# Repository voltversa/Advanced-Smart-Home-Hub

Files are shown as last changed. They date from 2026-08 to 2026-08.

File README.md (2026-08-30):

# STM32F746 Smart Home Hub

<p align="center">
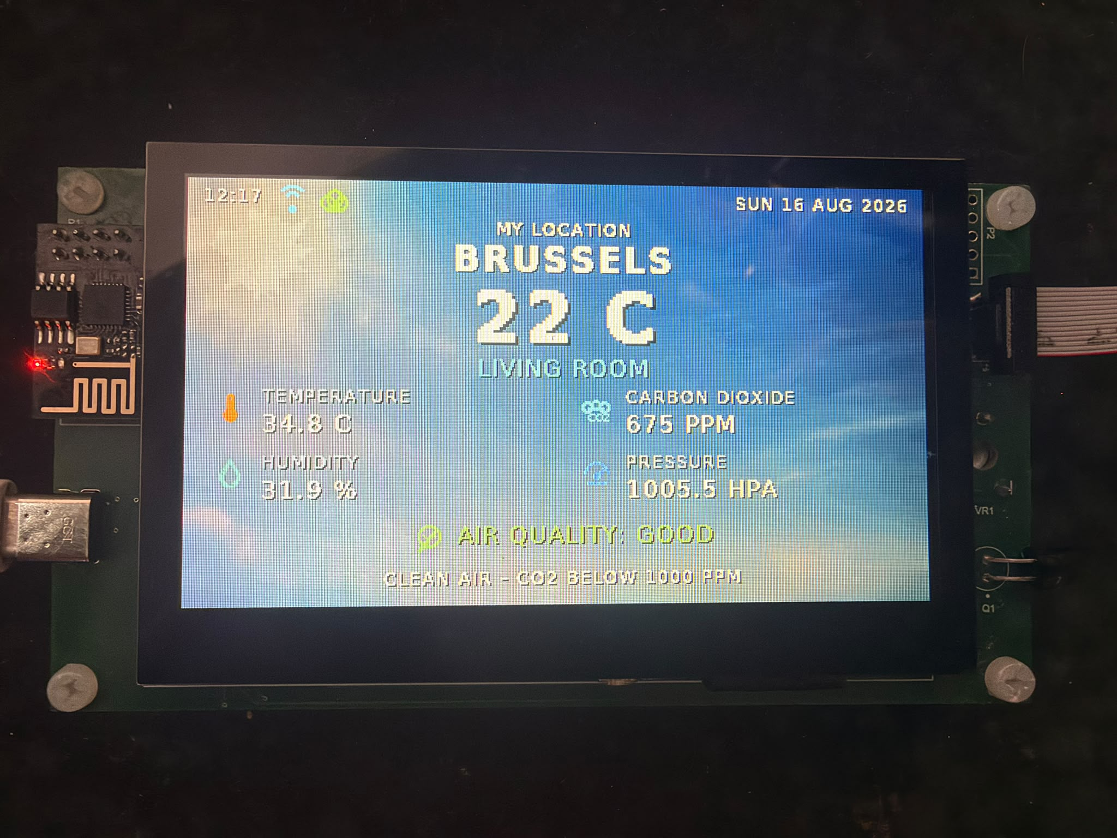
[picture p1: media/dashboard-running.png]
Smart Home Hub dashboard running on the assembled prototype
  
</p>

<p align="center">
  <strong>A custom embedded platform for environmental monitoring, local visualization, alarms, USB diagnostics, and Wi-Fi connectivity.</strong>
</p>






The Smart Home Hub is a manufactured and assembled Advanced PCB course project built around the STM32F746BGT6. It combines a 4.3-inch RGB display, external SDRAM and QSPI Flash, environmental sensing, an optical flame front end, an audible alarm, ESP-01/Blynk connectivity, and an MCP2221A USB service console on one custom PCB.

The repository contains the native Altium design history, a final four-layer submission package, manufacturing outputs, recovered application sources and GUI assets, test evidence, technical documentation, photographs, video, and the oral-demonstration presentation.

> [!IMPORTANT]
> This is an educational laboratory prototype. It is not a certified smoke, flame, gas, carbon-monoxide, or life-safety detector and must not replace approved safety equipment.

## System overview

```mermaid
flowchart TB
    POWER["USB-C power and 3.3 V buck"] --> MCU["STM32F746 control and graphics"]
    SENSORS["Environmental and flame sensors"] --> MCU
    MCU --> HMI["RGB LCD, backlight, and buzzer"]
    MCU <--> MEMORY["SDRAM and QSPI Flash"]
    MCU <--> COMMS["Wi-Fi and USB service console"]
```

| Subsystem | Implementation | Role |
|---|---|---|
| Main controller | STM32F746BGT6 | Acquisition, graphics, alarms, memory, and communications |
| Local interface | 4.3-inch 480×272 RGB LCD | Live dashboard and priority warning screens |
| Working memory | IS42S16400J, 8 MB SDRAM | Double-buffered graphics and temporary data |
| Asset storage | W25Q128JV, 16 MB QSPI NOR Flash | Persistent backgrounds, fonts, and icons |
| Environmental sensors | SCD41 and BME688 | CO₂, temperature, humidity, pressure, and relative gas-resistance diagnostics |
| Optical warning input | PT334-6B + LMV393 | Analog flame/IR response and active-low digital threshold |
| Connectivity | ESP-01 + Blynk | Wi-Fi telemetry and laboratory weather/time retrieval |
| Service interface | MCP2221A on USART3 | USB virtual COM-port diagnostics and commands |
| Power | USB-C, protected 5 V input, AP63203 3.3 V buck | Local power entry, protection, and regulation |
| Backlight | TPS61165 boost current driver | Constant-current LCD backlight control |

## Verified prototype status

These are observed bench results from the final Rev 2.1 report, not calculated targets.

| Test | Result | Evidence / note |
|---|---:|---|
| 5 V input and AP63203 3.3 V rail | **PASS** | Rails are present; the board and core peripherals operate. Fuse-trip and TVS-clamp stress tests were not documented |
| STM32 boot and SWD programming | **PASS** | Firmware programs and runs |
| RGB LCD and backlight | **PASS** | Stable image after correcting the boost-diode orientation |
| SCD41 | **PASS** | CO₂ plus temperature/humidity using a 9.3 °C installation-specific sensor offset |
| BME688 | **PASS** | Pressure, gas resistance, and diagnostics acquired |
| Flame analog/digital path | **PASS** | ADC and active-low comparator output respond |
| Buzzer driver | **PASS** | Controlled by the STM32 and silent during reset |
| ESP-01, Blynk, and outdoor data | **PASS** | AT, Wi-Fi, TCP, Blynk, and weather/time path demonstrated |
| W25Q128 QSPI | **PASS** | JEDEC ID `EF 40 18`; stored assets verified |
| IS42S16400 SDRAM | **PASS** | Full 8 MB repeatedly verified at approximately 66 MHz |
| MCP2221A USB-UART | **PASS** | Enumerates and exchanges bidirectional USART3 traffic after D+ path repair |
| GT911 capacitive touch | **NOT TESTABLE** | The display assembly's external touch flex is mechanically torn |

The current BME688 source learns 60 valid samples, then triggers only when gas resistance remains at or below 55% of baseline for six samples (about 30 seconds); it clears at or above 75% for six samples. This is only a relative air-change indicator. A calibrated gas identity, ppm result, or end-to-end gas-triggered safety response was not validated.

<p align="center">
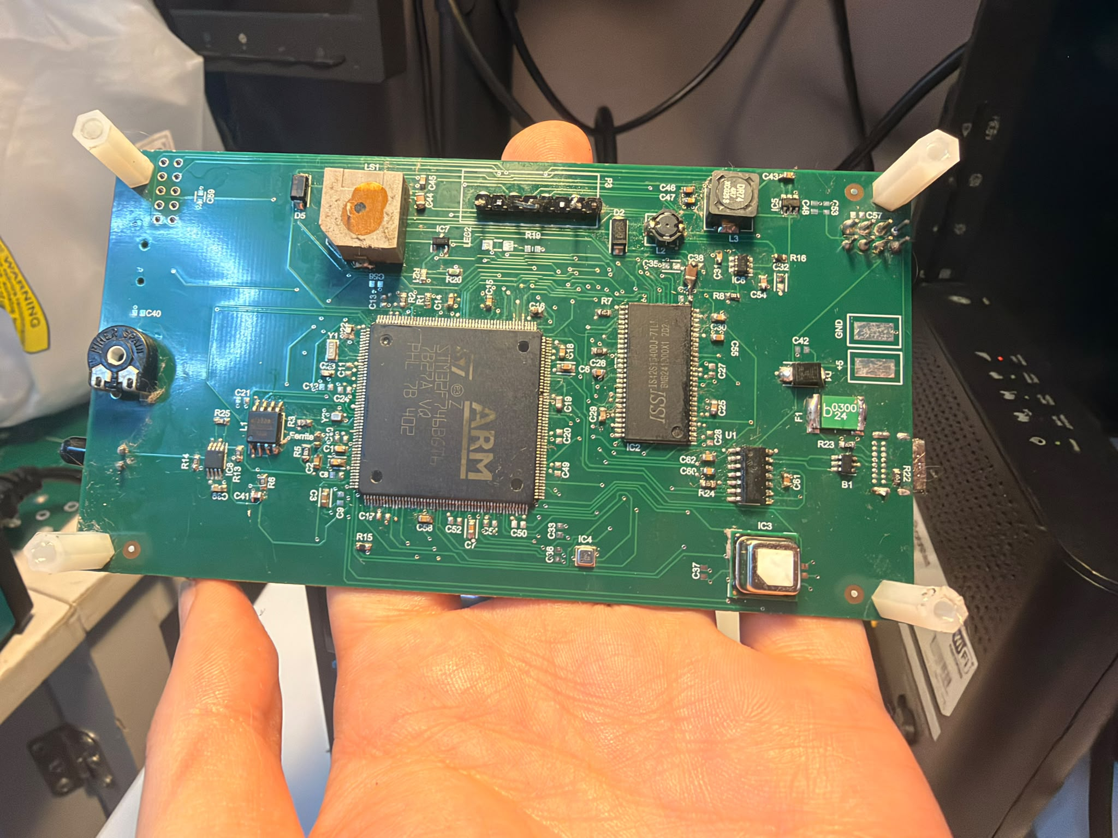
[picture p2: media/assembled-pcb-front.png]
Assembled PCB component side
  
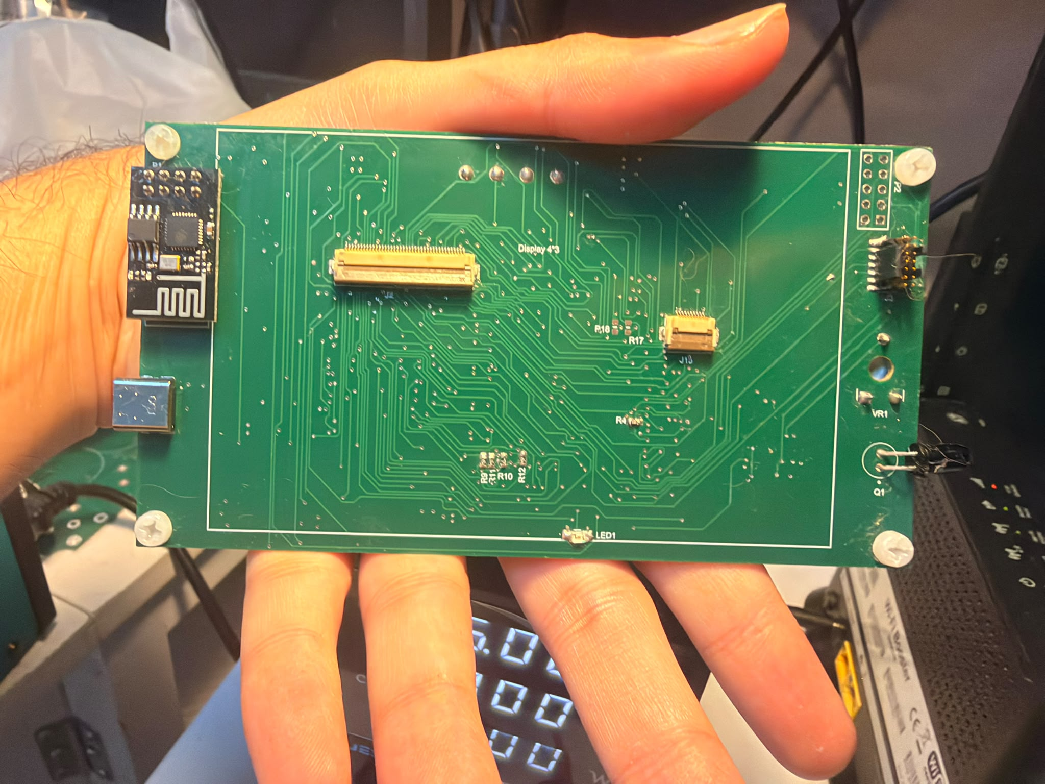
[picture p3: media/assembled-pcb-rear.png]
Assembled PCB rear side
  
</p>

## Why two external memories?

- **QSPI Flash is persistent storage.** It keeps the GUI backgrounds, fonts, icons, metadata, and checksums when power is removed.
- **SDRAM is fast working memory.** It stores the live framebuffers and temporary graphics data, but loses its contents after power-off.

The final GUI draws into an inactive SDRAM buffer and swaps the LTDC address during vertical blanking. This removes whole-screen flashing while QSPI supplies the reusable visual assets.

<p align="center">
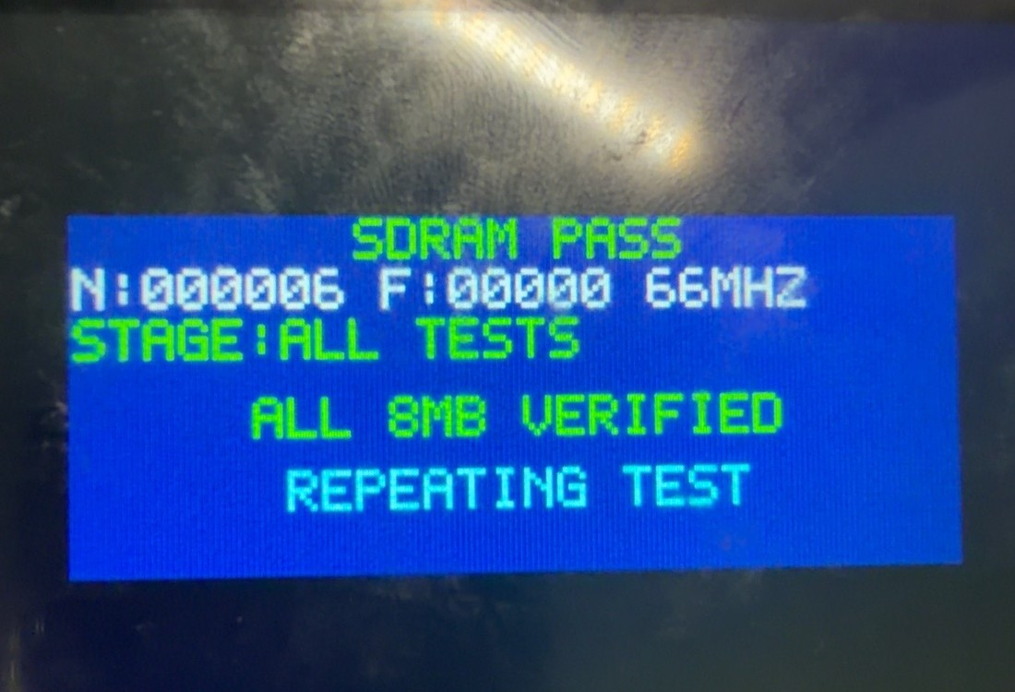
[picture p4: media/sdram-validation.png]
Repeated full 8 MB SDRAM validation result
  
</p>

## Repository layout

```text
.
├── firmware/
│   ├── Core/                 Final recovered application and asset sources
│   ├── Assets/               Weather artwork used to generate QSPI content
│   ├── Tools/                Asset-generation and preview scripts
│   └── Reference/            SDRAM diagnostic and dated legacy CubeMX files
├── hardware/
│   ├── altium/               Earlier two-layer native-design snapshot
│   └── manufacturing/        Earlier two-layer manufacturing snapshot
├── docs/
│   ├── report/               Rev 2.1 technical report in DOCX and PDF
│   ├── presentation/         Editable project presentation
│   ├── firmware-guide/       Firmware code guide in DOCX and PDF
│   └── configuration/        Legacy V0–V12 Blynk export
├── media/                    README photographs, diagrams, and validation images
└── submission/               Final four-layer handoff, complete sanitized firmware, and media
```

See [`firmware/README.md`](firmware/README.md) for source integration and QSPI installation, [`hardware/README.md`](hardware/README.md) for the hardware revision history, and [`submission/README.md`](submission/README.md) for the attached final handoff.

## Firmware integration

The curated `firmware/` tree contains the recovered final application layer, QSPI/GUI assets, MCP2221A console, asset tools, and diagnostics. The attached [`09_Firmware_sanitized.zip`](submission/Mahmoud_Mostafa_Adv_pcb/09_Firmware_sanitized.zip) adds a structurally complete STM32CubeIDE project with HAL/CMSIS drivers, startup and linker files, `main.h`, the `.ioc`, and the Bosch BME68x driver. Live credentials and the compiled `Debug/` tree were deliberately removed.

The complete archive's `main.c` and CubeMX/FMC snapshot differ from the curated final source and the passing SDRAM settings documented in Rev 2.1. It is therefore a useful integration base, not a verified one-click reproducible build.

1. Extract the sanitized complete CubeIDE archive, or generate a new `STM32F746BGTx` project.
2. Use `firmware/Core/Inc` and `firmware/Core/Src` as the application-behavior reference.
3. Reconcile the archive's FMC/LTDC configuration with the final verified settings documented in the report before regenerating code.
4. Copy `firmware/Core/Inc/app_secrets.h.example` to `app_secrets.h` and enter local credentials. Never commit that file.
5. Follow the QSPI workflow in `firmware/README.md`; the longer weather/asset guide is retained as a clearly marked historical reference.
6. Flash through SWD/ST-LINK, then verify the service console, memory tests, sensors, display, and network path.

The dated IOC under `firmware/Reference/legacy-cubemx/` is retained only as a pin-allocation reference. It predates the final verified SDRAM timing and must not be treated as a turnkey final configuration.

## USB service console

The MCP2221A exposes USART3 at **115200 8N1**. Available commands include:

- `PING` — verifies the complete PC ↔ USB ↔ MCP2221A ↔ STM32 round trip.
- `STATUS` — summarizes memory, sensor, network, and alarm state.
- `SENSORS` — prints live SCD41, BME688, gas, and flame values.
- `NETWORK` — reports ESP-01, Wi-Fi, Blynk, location, and weather state.
- `MEMORY` — reports SDRAM and QSPI state.

## Design notes and limitations

- **Touch:** the GT911 path is unavailable because the external display flex is torn; the operating dashboard does not depend on touch.
- **Location and time:** the recovered final `main.c` is fixed to Brussels for the displayed city and weather request. Its UTC offset is also fixed at `+7200` seconds, so Belgian winter time will display one hour fast unless the firmware is updated for DST. It does not provide GPS-level positioning.
- **Gas channel:** BME688 gas resistance is interpreted relative to a learned baseline. It cannot identify a gas or report validated concentration.
- **Optical flame channel:** sunlight, lamps, and other infrared sources can affect the phototransistor.
- **SCD41 compensation:** the configured 9.3 °C offset is installation-specific and must be recalibrated if enclosure, airflow, display heating, or sensor placement changes.
- **Networking:** the working ESP-01 path uses plain HTTP as a laboratory compatibility workaround; it is not a production security design.
- **Validation scope:** no claim is made for formal sensor calibration, long-duration reliability, EMC, or electrical-safety certification.
- **DRC status:** the later four-layer submission reports 23 violations (one solder-mask sliver and 22 silkscreen-to-mask); the earlier two-layer snapshot reports 55 plus two waived polygon warnings. Neither package is a clean fabrication release.
- **Layer history:** the earlier expanded `hardware/` snapshot is two-layer. The attached final Altium archive supersedes it with a native four-copper-layer stack—Top, GND plane, 3V3 plane, Bottom—and matching `GP1`/`GP2` production outputs.
- **Design archives:** the earlier Altium project references external libraries that were not recovered. Preserve both revisions and verify library resolution before editing or regenerating outputs.
- **BOM metadata:** the earlier CSV BOM contains conflicting value/description/MPN fields; the final submission adds an XLSX BOM, but procurement fields still require verification against the final schematic and selected datasheets.
- **Buzzer documentation:** the Rev 2.1 narrative describes a 5 V buzzer rail and 100 kΩ gate pull-down, while the earlier recovered schematic/BOM show 3.3 V and 10 kΩ. Verify the final native revision and assembled board before relying on either description.
- **USB schematic history:** the earlier compiled MCP2221A/USBLC6 sheet contains inconsistent D−/VUSB connections and did not capture the repaired working path. Verify the later native revision and physical board before reproducing this section.
- **Manufacturing data:** the final Altium archive includes `PCB1.cvg`, an IPC-2581 Revision B XML file despite its extension, plus a STEP model and a four-layer production archive. No claim is made that the package is order-ready while DRC violations remain.
- **Altium PDFs:** several compiled schematic/PCB/ERC PDFs contain embedded JavaScript and vendor-link actions. Open them only in a trusted viewer with active content disabled, or export flattened copies from Altium before wider distribution.

Do not test the alarm using dangerous gas exposure or uncontrolled flame. Use independently powered, certified detectors for real protection.

## Documentation

- [Technical Report — Rev 2.1 (PDF)](docs/report/Smart_Home_Hub_Technical_Report_Rev2.1.pdf)
- [Technical Report — Rev 2.1 (DOCX)](docs/report/Smart_Home_Hub_Technical_Report_Rev2.1.docx)
- [Firmware Code Guide — historical snapshot (PDF)](docs/firmware-guide/Smart_Home_Hub_Firmware_Code_Guide.pdf)
- [Project Presentation (PPTX)](docs/presentation/Smart_Home_Hub_Presentation.pptx)
- [Compiled Schematic PDF](hardware/altium/Hub_Unit%20-%20Copy.pdf)
- [Canonical Blynk V0–V16 definition](firmware/BLYNK_DATASTREAMS.md)
- [Final submission package index](submission/README.md)
- [Final four-layer Altium archive](submission/Mahmoud_Mostafa_Adv_pcb/01_Altium_Project.zip)
- [Oral-demonstration presentation](submission/Mahmoud_Mostafa_Adv_pcb/11_Smart_Home_Hub_Oral_Demonstration.pptx)

## Security

Real Wi-Fi and Blynk credentials are intentionally excluded. The attached raw firmware archive contained live credentials in `app_secrets.h` and compiled copies in its debug binaries; the repository includes a sanitized replacement without those files. Rotate the exposed credentials. The current laboratory firmware sends the Blynk token and telemetry over unencrypted HTTP; a failed ESP-01 echo-disable command can also expose the Wi-Fi join command in debug output. Do not use production credentials with this firmware.

---

Built as an Advanced PCB educational project; Rev 2.1 documentation dated 16 August 2026.

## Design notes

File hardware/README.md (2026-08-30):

# Hardware design and manufacturing data

## Final four-layer submission

The later attached handoff is preserved under [`submission/Mahmoud_Mostafa_Adv_pcb/`](../submission/Mahmoud_Mostafa_Adv_pcb/):

- `01_Altium_Project.zip` contains the native project, a four-layer `PCB1.PcbDoc`, `PCB1.step`, and `PCB1.cvg`.
- `PCB1.cvg` is an IPC-2581 Revision B XML document despite its nonstandard extension.
- The active native stack is Top copper → GND plane → 3V3 plane → Bottom copper and is configured at approximately 0.624 mm including solder masks; confirm finished thickness with the fabricator.
- `02_Production_Data.zip` includes matching `GTL`, `GP1`, `GP2`, and `GBL` files, drill data, pick-and-place, and an XLSX BOM.
- The final DRC report records 23 unwaived violations: one solder-mask sliver and 22 silkscreen-to-mask entries. Electrical routing rule groups report zero, but the release is not DRC-clean.

The final native PCB/STEP and IPC-2581 are dated in August, while the production outputs remain dated 17 July. Regenerate the production set from the final native PCB before fabrication. The XLSX BOM/PnP reference sets agree at 122 designators, but value/description/MPN conflicts remain and require line-by-line procurement review.

This final submission supersedes the layer count of the earlier snapshot below, but both are preserved for traceability.

## Earlier `altium/` snapshot

Native design data recovered from the archived Altium project:

- `Hub_Unit - Copy.PrjPcb`
- six hierarchical `SchDoc` sheets
- `PCB1.PcbDoc`
- `Hub_Unit - Copy.OutJob`
- CAM files
- compiled smart schematic PDF

The original filenames are preserved to avoid breaking Altium project references.

The project file still references three external integrated/schematic/PCB libraries that were not present in the recovered archive, and the OutJob retains dated absolute Windows output paths. The native documents can be inspected, but this is not a self-contained Altium workspace.

## Earlier `manufacturing/` snapshot

This directory preserves a 17 July 2026 output snapshot without regenerating it:

- Gerber/layer files
- plated, non-plated, slot, and counter-hole drill data
- drill reports
- pick-and-place CSV
- BOM CSV (`Hub_Unit - Copy.csv`)
- DRC report

Keep this package unchanged for traceability. Do **not** submit it unchanged for a new order. Its native `PCB1.PcbDoc` master stack contains top copper, one dielectric, and bottom copper; its Gerbers likewise contain only top and bottom copper. This is an earlier two-layer snapshot, not the later four-layer handoff.

The archived DRC report is historical output, not a zero-violation signoff. It records 55 detected violations, two waived violations, and a modified-polygon warning. Repour polygons and run a clean DRC before placing a new manufacturing order.

The BOM and PnP files contain the same populated reference set, but several BOM value/description/manufacturer-part fields conflict. Treat them as historical assembly records, not procurement-ready data; verify every line against the schematic, the assembled board, and the selected component datasheet.

One known report/schematic discrepancy is the buzzer driver: the Rev 2.1 narrative says 5 V with a 100 kΩ gate pull-down, while the recovered schematic and BOM show 3.3 V with 10 kΩ. Verify the physical board before updating or reproducing this section.

The compiled MCP2221A/USBLC6 sheet also appears to route D− and VUSB through incompatible protection-device pins and does not represent a valid USB path. The reworked prototype enumerated after a D+ repair, which means this archived drawing is not a dependable as-built record. Trace the physical board and correct/regenerate the Altium source before fabricating this section.

## Release caveats

The earlier expanded snapshot lacks IPC-2581, STEP, and a standalone XLSX BOM; the later submission provides all three. Neither revision includes a clean DRC signoff or evidence that the output set was independently approved by a fabricator. Verify stack-up, dimensions, apertures, drill classes, BOM fields, and DRC from the final native project before ordering.

The compiled Altium smart PDF contains embedded JavaScript and vendor-link actions. Use a trusted viewer with active content disabled, or export a flattened schematic PDF from Altium before wider distribution.

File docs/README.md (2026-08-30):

# Documentation index

- `report/` — final Rev 2.1 technical report, dated 16 August 2026, in editable DOCX and PDF form.
- `presentation/` — editable project presentation.
- `firmware-guide/` — historical firmware function guide in DOCX and PDF form; its IP-geolocation, timing, and source-line descriptions predate the recovered final `main.c`.
- `configuration/Blynk_Datastreams.csv` — legacy V0–V12 Blynk export recovered from the project. The canonical V0–V16 definition is `../firmware/BLYNK_DATASTREAMS.md`.
- `../submission/` — later final handoff with Rev A hardware PDFs, XLSX BOM, ERC/difference reports, a second Rev 2.1 document set, the oral-demonstration deck, photographs, and video.

The report is the primary project narrative for architecture, validation scope, repairs, limitations, and bench results. Cross-check exact thresholds, firmware behaviour, schematic values, and manufacturing metadata against the current source and native design files. The later submission's four-layer native stack and inner-plane outputs supersede the earlier two-layer snapshot retained under `hardware/`.

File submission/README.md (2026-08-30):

# Final submission package

This directory preserves the contents of the later `Mahmoud_Mostafa_Adv_pcb.zip` handoff in a browsable repository layout. Original deliverable names are retained under `Mahmoud_Mostafa_Adv_pcb/`, except that the unsafe firmware archive is replaced by `09_Firmware_sanitized.zip`.

- Source attachment SHA-256: `7dd5dbed5942abe31eb20fdf98b530309be2df47fd8e590c0eb552e7d38fed2e`
- Sanitized firmware SHA-256: `28649cce5e507eb17961e5c7566a2afb844a6b307e8eba77be5b6ce73bb02d63`
- File checksums: [`MANIFEST.sha256`](MANIFEST.sha256)

From the repository root, verify the complete submission with `sha256sum -c submission/MANIFEST.sha256`.

## Contents

| Item | Description |
|---|---|
| `01_Altium_Project.zip` | Final native four-layer Altium project, STEP model, and IPC-2581 Rev B file (`PCB1.cvg`) |
| `02_Production_Data.zip` | Four-layer Gerber/plane outputs, drill data, BOM, pick-and-place, and DRC snapshot |
| `03_*` through `08_*` | PCB/schematic PDFs, PCB documentation, XLSX BOM, DRC, ERC, and schematic-to-PCB difference report |
| `09_Firmware_sanitized.zip` | Complete CubeIDE project with HAL/CMSIS, startup/linker files, `.ioc`, Bosch BME68x, and application sources |
| `10_*` | Rev 2.1 report in DOCX and PDF |
| `11_*` | Editable oral-demonstration presentation |
| `images&videos/` | Submitted prototype screenshots, photographs, and demonstration video |
| `PCB_3D_photo.png` | Submitted PCB 3D rendering |

## Hardware evidence

The final native `PCB1.PcbDoc` uses four copper layers: Top, internal GND plane, internal 3V3 plane, and Bottom. The production archive contains corresponding `GTL`, `GP1`, `GP2`, and `GBL` outputs. The file named `PCB1.cvg` begins with an IPC-2581 Revision B XML root and is the requested IPC-2581 deliverable.

The configured native/IPC stack is approximately 0.624 mm including solder masks; confirm the intended finished thickness with the fabricator. The preserved DRC is not clean: it records 23 unwaived violations—one solder-mask sliver and 22 silkscreen-to-mask entries—although its electrical routing rule groups report zero violations. Review and resolve every entry before any fabrication order.

The production outputs and DRC are dated 17 July 2026, while the native PCB/STEP are dated 13 August and IPC-2581 was generated 16 August. Regenerate the complete output set from the final native PCB before ordering. The BOM/PnP reference sets agree, but several value/description/MPN fields remain inconsistent and are not procurement-ready.

Several Altium-generated PDFs in this package contain embedded JavaScript for document interactivity and vendor links. Open them only in a trusted viewer with active content disabled, or export flattened derivatives before wider distribution.

## Credential sanitization

The raw attached `09_Firmware.zip` is intentionally not committed. It contained live Wi-Fi/Blynk credentials in `Core/Inc/app_secrets.h`, with compiled copies embedded in debug binaries. `09_Firmware_sanitized.zip` removes that file and the entire `Debug/` tree while retaining the safe `app_secrets.h.example`, full source, device drivers, startup code, linker scripts, and project metadata.

The original outer ZIP is also omitted because it contains that unsafe nested archive; its safe contents are represented individually in this directory.

Rotate the exposed credentials before using the project again. Do not commit a replacement `app_secrets.h`.

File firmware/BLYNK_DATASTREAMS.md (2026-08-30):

# Home HUB Blynk datastreams

Create every datastream below in **Developer Zone -> Templates -> Home HUB ->
Datastreams**. The batch update is rejected if the firmware requests a pin that
does not exist in this template.

| Pin | Name | Type | Units | Suggested range |
|---|---|---|---|---|
| V0 | Flame detected | Integer | Boolean | 0 to 1 |
| V1 | Flame ADC | Integer | ADC counts | 0 to 4095 |
| V2 | Flame voltage | Double | V | 0 to 3.3 |
| V3 | CO2 | Integer | ppm | 0 to 5000 |
| V4 | Room temperature (compensated SCD41) | Double | °C | -40 to 70 |
| V5 | Room humidity (compensated SCD41) | Double | % | 0 to 100 |
| V6 | BME688 PCB temperature diagnostic | Double | °C | -40 to 85 |
| V7 | BME688 PCB humidity diagnostic | Double | % | 0 to 100 |
| V8 | BME688 pressure | Double | hPa | 300 to 1100 |
| V9 | BME688 gas resistance | Double | kΩ | 0 to 10000 |
| V10 | Gas baseline ratio | Integer | % | 0 to 200 |
| V11 | Gas alarm | Integer | Boolean | 0 to 1 |
| V12 | Outside temperature | Integer | °C | -50 to 60 |
| V13 | Outside feels-like | Integer | °C | -50 to 60 |
| V14 | Outside daily high | Integer | °C | -50 to 60 |
| V15 | Outside daily low | Integer | °C | -50 to 60 |
| V16 | Weather theme | Integer | Index | 0 to 15 |

The pin numbers are centralized in `Core/Inc/app_config.h`. If you change a
pin in Blynk, change its matching `VPIN_...` definition there as well.

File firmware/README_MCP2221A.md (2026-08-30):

# MCP2221A debug-console integration

This source package keeps the ESP-01 on **USART1** and uses the MCP2221A-I/SL
only as the PC debug console on **USART3**.

## Hardware mapping

> **As-built caveat:** the mapping below is the intended functional interface.
> The archived compiled schematic's MCP2221A/USBLC6 section contains
> inconsistent D− and VUSB connections and does not capture a reliable
> as-built path. The prototype worked after a D+ repair; trace the physical
> board and correct the Altium source before reproducing this interface.

- STM32 `PC10 / USART3_TX` -> MCP2221A `URX`
- STM32 `PC11 / USART3_RX` <- MCP2221A `UTX`
- MCP2221A `VDD` = 3.3 V
- MCP2221A `VUSB` must follow the device datasheet and the verified board wiring; do not infer it from the archived sheet
- Common ground

The MCP2221A is a transparent USB-to-UART bridge. It does not require a
special STM32 driver.

## CubeMX USART3 configuration

- Mode: Asynchronous
- Baud rate: 115200
- Word length: 8 bits
- Parity: None
- Stop bits: 1
- Hardware flow control: None
- TX: PC10, AF7
- RX: PC11, AF7

## Files to copy into the CubeIDE project

1. Replace `Core/Src/main.c` with the supplied organized version.
2. Copy `Core/Src/mcp2221a_console.c` into `Core/Src`.
3. Copy these files into `Core/Inc`:
   - `mcp2221a_console.h`
   - `app_config.h`
   - create `app_secrets.h` from `app_secrets.h.example`
4. Refresh the CubeIDE project and run **Project -> Clean**, then **Build**.

The credential-bearing `app_secrets.h` is intentionally excluded from this
repository. Keep the local file untracked; `app_secrets.h.example` is the safe
template.

## Terminal configuration

Open the MCP2221A COM port in RealTerm, Tera Term or PuTTY using:

- 115200 baud
- 8 data bits
- No parity
- 1 stop bit
- No flow control
- ASCII display

Reset the board. A HOME HUB banner should appear.

## Commands

- `HELP` or `?` - list commands
- `PING` - test both UART directions; response must be `PONG`
- `INFO` - display the USART3/MCP2221A configuration
- `STATUS` - memory, sensor, network and alarm summary
- `SENSORS` - live SCD41, BME688, gas and flame values
- `NETWORK` - ESP-01, Wi-Fi, Blynk, location and weather state
- `MEMORY` - SDRAM and QSPI state

`SENSORS` also reports the compensated SCD41 room temperature/humidity, the
BME688 PCB-side diagnostics, and their thermal difference.

Typing `PING` manually verifies the complete path:

PC -> USB -> MCP2221A UTX -> STM32 PC11 -> firmware -> STM32 PC10 ->
MCP2221A URX -> USB -> PC.

## Blynk reminder

The firmware batch request uses virtual pins V0 through V16 when all data is
available. Every transmitted pin must exist as a datastream in the `Home HUB`
template with a compatible data type.

## Temperature compensation

The dashboard and room-temperature alarms use the SCD41. At startup the
firmware writes the configured SCD41 integration offset from
`SCD41_TEMPERATURE_OFFSET10` in `app_config.h`. The current value is 93,
meaning 9.3 °C. The BME688 temperature is not averaged into the room value
because its gas heater and PCB heat make it unsuitable as the ambient source
in this assembly.

After changing the enclosure, ventilation, display brightness or power load,
run the complete hub for at least 30 minutes beside a trusted thermometer and
recalibrate the offset under thermal equilibrium.

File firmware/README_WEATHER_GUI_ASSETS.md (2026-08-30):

# Smart Home Hub — Weather GUI, QSPI Assets and SDRAM Frames

> **Historical reference:** this document describes the 14 August 2026
> IP-geolocation/Open-Meteo revision from which the GUI assets were recovered.
> The final 16 August `Core/Src/main.c` in this repository instead fixes the
> displayed location to Brussels and uses `wttr.in`. Use this guide for the
> QSPI asset map, installer workflow, artwork, and generation tools; use the
> root README and current source for final application behaviour.

This is the recovered weather/asset application package. It preserves the
working SCD41, BME688, flame detector, buzzer, ESP-01, Blynk and double-buffered
LTDC code, then adds:

- approximate IP-based city/coordinates and timezone;
- local time and date;
- outside temperature, feels-like, daily high/low and condition;
- eight full-screen weather/time backgrounds (day, dawn, sunset, night,
  cloudy, rain, storm and snow);
- a card-free 480x272 GUI in the style requested;
- calmer, persistent air-quality alarm thresholds;
- outside readings on Blynk V12 through V16.

No weather API key or ESP SSL support is needed. Location is requested from
the free HTTP `ip-api.com` JSON endpoint and weather from a compact one-day
Open-Meteo forecast containing only the fields used by the dashboard.

References:

- <https://ip-api.com/docs/api:json>
- <https://open-meteo.com/en/docs>

IP geolocation is approximate. A VPN, mobile network or ISP exit point can
produce a nearby city instead of the exact building. See “fixed location”
below if exact coordinates are required.

## What each memory does

| Memory | Address | Job |
|---|---:|---|
| STM32 internal Flash | `0x08000000` | Firmware/application logic; temporary compressed installer images only during the first build |
| W25Q128 QSPI | `0x90000000` | Eight native L8 backgrounds, shared CLUT, fonts and icons |
| IS42S16400J SDRAM | `0xC0000000` | Two live 480x272 L8 framebuffers |
| STM32 internal SRAM | automatic | Stack, sensor values and network response buffers |

The front and back display frames use 261,120 bytes total. The CPU finishes a
new frame in the hidden SDRAM buffer and swaps it only during LTDC vertical
blanking. The full background can therefore be rebuilt atomically with no
visible white/black flash.

## Files to copy into STM32CubeIDE

Back up the currently working CubeIDE project first.

Copy to `Core/Src`:

- `main.c`
- `qspi_assets.c`
- `weather_backgrounds.c` (first installer build only)
- `gui_modern_assets.c` (first installer build only)

Copy to `Core/Inc`:

- `qspi_assets.h`
- `weather_backgrounds.h`
- `gui_modern_assets.h`

Keep your already-working Bosch `bme68x.c` and `bme68x.h`. Do not add
`SDRAM_Diagnostic_main.c` to the application build; it contains another
`main()` and is only a separate diagnostic reference.

## Set the private values

For the recovered final application, copy `Core/Inc/app_secrets.h.example` to
the ignored local file `Core/Inc/app_secrets.h` and replace its placeholders:

```c
#define WIFI_SSID         "REPLACE_WITH_YOUR_WIFI_NAME"
#define WIFI_PASSWORD     "REPLACE_WITH_YOUR_WIFI_PASSWORD"
#define BLYNK_AUTH_TOKEN  "REPLACE_WITH_YOUR_DEVICE_TOKEN"
```

The template ID/name in the code are metadata for documentation. Raw Blynk
HTTP updates require the device authentication token, not those two template
strings.

Do not publish real Wi-Fi credentials or the Blynk device token in the course
archive, report, screenshots or public repository.

## First build: install QSPI asset version 4

The delivered `qspi_assets.h` intentionally starts with:

```c
#define QSPI_ASSET_INSTALLER  1U
```

1. Ensure `weather_backgrounds.c` and `gui_modern_assets.c` are included in
   the active Debug build (right-click each file, Resource Configurations,
   Exclude from Build, and leave Debug unchecked).
2. Project > Clean.
3. Build and flash.
4. Do not remove power while the display says the assets are being installed.
5. Wait until the display reports `QSPI ASSETS / INSTALLED` and then reaches
   the application.

The eight C source images are only 240x136 indexed pixels. During this one
build, the installer expands every pixel to a 2x2 block and writes native
480x272 frames into QSPI. This keeps the temporary firmware small enough for
the STM32F746 internal Flash.

## Second build: normal application

After the successful installer boot:

1. Change `QSPI_ASSET_INSTALLER` from `1U` to `0U` in `qspi_assets.h`.
2. Right-click `weather_backgrounds.c` > Resource Configurations > Exclude
   from Build, and check both Debug and Release.
3. Do the same for `gui_modern_assets.c`.
4. Clean, build and flash again.

Do not delete either generated file from your submitted source archive. They
are required to reproduce the QSPI image later, but they should not occupy
STM32 internal Flash in the normal build.

## QSPI version-4 map

| Region | QSPI offset |
|---|---:|
| Header | `0x000000` |
| 8 x 480x272 L8 backgrounds | `0x001000` to `0x0FFFFF` |
| Shared 256-entry CLUT | `0x100000` |
| Fallback 5x7 font | `0x101000` |
| Modern fonts/icons | `0x102000` |
| End of erased asset region | `0x104000` |

`qspi_assets.c` verifies W25Q128 JEDEC ID `EF 40 18`, version-4 metadata and
CRC32 values before entering memory-mapped mode.

## Blynk datastreams

The existing V0–V11 measurements are preserved. Add these optional
datastreams to show outside weather:

| Pin | Type | Meaning |
|---|---|---|
| V12 | Integer | Outside temperature, C |
| V13 | Integer | Feels-like temperature, C |
| V14 | Integer | Daily high, C |
| V15 | Integer | Daily low, C |
| V16 | Integer | Theme number: 0 day, 1 dawn, 2 sunset, 3 night, 4 cloudy, 5 rain, 6 storm, 7 snow |

## Network behavior

- Location/timezone: refresh every six hours; retry every five minutes.
- Weather: refresh every 15 minutes; retry every minute after a failure.
- The last valid forecast remains on screen and is marked `STALE` after
  30 minutes without an update.
- The HTTP `Date` header supplies UTC. The location response supplies the
  local UTC/DST offset, and `HAL_GetTick()` advances the clock between syncs.
- Weather is never required for local flame/gas/sensor alarms to function.

To use exact fixed coordinates instead of IP geolocation, set
`internet_weather.latitude`, `.longitude`, `.city`, `.utc_offset_seconds` and
`.location_valid = true` before the first `Weather_Fetch()`, then disable the
periodic `Location_Fetch()` block. Keep in mind that a manually fixed UTC
offset must be changed when daylight-saving time changes.

## Calmer air-quality behavior

The displayed CO2 interpretation is now:

| CO2 | Display/action |
|---:|---|
| below 1000 ppm | GOOD |
| 1000–1499 ppm | FAIR |
| 1500–2499 ppm | POOR; a short reminder beep every 30 seconds |
| 2500 ppm or higher | DANGER/critical alarm |

The BME688 gas alarm now:

- learns its heater-stable baseline for 60 valid samples (about five minutes);
- ignores resistance increases;
- triggers only below 55% of baseline for six consecutive samples
  (about 30 seconds);
- clears only above 75% for six consecutive samples.

Flame detection stays immediate and uses the fast critical buzzer pattern.
Sensor-maintenance faults now beep only once per minute.

These thresholds reduce nuisance alarms, but the BME688 is not a calibrated
combustible-gas or CO safety detector. This project remains an experimental
monitor. Keep independently powered, certified smoke, fire, carbon-monoxide
and combustible-gas alarms installed.

## CubeMX settings that must remain unchanged

Use the already proven settings:

- HCLK: 200 MHz;
- FMC SDCLK: HCLK/3 = 66.667 MHz;
- SDRAM refresh count: 1022;
- 8 column bits, 12 row bits, 16-bit bus, 4 banks, CAS 3;
- read burst disabled and read-pipe delay 0;
- HSE bypass for the powered 8 MHz ASCO oscillator;
- LTDC 480x272 timings already proven on the MDT0430A01ISC-RGB;
- I2C3/BME688, I2C4/SCD41, ADC1 IN1/PA1, PH2 flame input,
  USART1/ESP-01 and the current buzzer GPIO.

## Bench test

1. First installer boot reports `QSPI ASSETS / INSTALLED`.
2. Normal build reports `QSPI ASSETS / READY`.
3. City, local time/date and outside forecast appear after Wi-Fi connects.
4. Background changes for day, dawn, sunset, night and weather conditions.
5. Indoor values update without a whole-screen flash.
6. Disconnect the router briefly: the local sensors and alarms continue.
7. Reconnect: weather and Blynk recover automatically.
8. Exercise alarm logic electronically by simulating inputs or flags. Do not
   use dangerous gas exposure or uncontrolled flame; use certified test
   equipment and independently powered approved detectors.
9. Run the complete hub continuously for at least 30 minutes.

`Assets/previews/weather_gui_preview_sheet.png` shows four representative
no-card layouts after running `Tools/preview_weather_gui.py`.

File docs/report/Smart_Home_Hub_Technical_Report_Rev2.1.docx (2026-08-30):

THOMAS MORE · ELECTRONICS-ICT

ADVANCED PCB PROJECT

Smart Home Hub

Four-layer STM32F746 environmental, connected-weather and alert platform

STUDENT | Mahmoud Mostafa
PROGRAMME | Professional Bachelor Electronics-ICT
COURSE | Advanced PCB: Lab · B-TM-YT6250 · 3 ECTS
LECTURER | Jurre De Weerdt
ACADEMIC YEAR | 2025–2026

AS-BUILT TECHNICAL REPORT · REVISION 2.1

# Document summary

Field | Value
Document | Smart Home Hub — Advanced PCB Project Technical Report
Revision / date | 2.1 / 16 August 2026
Project stage | Manufactured, assembled and integrated prototype; full core system demonstrated
Design tools | Altium Designer; STM32CubeMX / STM32CubeIDE
Board | Four-layer rigid PCB: Top signal / GND plane / 3V3 plane / Bottom signal
Primary MCU | STM32F746BGT6

## Abstract

This report documents the design, manufacture, assembly and bench verification of a smart-home hub developed for the Advanced PCB laboratory. The custom four-layer board is centred on an STM32F746BGT6 microcontroller and integrates a 4.3-inch RGB display, SCD41 and BME688 environmental sensors, a flame-detection front end, an audible alarm, Wi-Fi connectivity, a USB service interface and two external memories.

The final system presents location-aware outdoor information and the important indoor measurements on a QSPI-themed graphical dashboard. The SCD41 provides the compensated room temperature, relative humidity and CO₂ concentration; the BME688 provides pressure and relative gas-resistance diagnostics. Flame and persistent gas-change monitoring remain active in the background and can raise a priority on-screen warning and sound the buzzer independently of the cloud connection.

Bench testing confirms the protected 5 V input, regulated 3.3 V rail, MCU, RGB display and backlight, SCD41, BME688, flame detector, buzzer, ESP-01 Wi-Fi/Blynk link, internet time/date/outdoor temperature, W25Q128 QSPI flash, the full 8 MB IS42S16400 SDRAM and the MCP2221A USB-to-UART console. The USB bridge originally failed because the USBLC6-2SC6 D+ protection path was shorted to ground; after rework it enumerated and carried bidirectional USART3 traffic. The only remaining unavailable function is touch input because the display assembly's external GT911 flex tail is mechanically torn.

SAFETY SCOPE
This is an educational prototype. The flame and gas-change functions are not certified fire, gas-leak or life-safety detectors and must not replace approved alarms.

# Project outcome at a glance

Area | Status | Evidence
Core environmental dashboard | PASS | Live compensated SCD41 values and BME688 pressure shown on the RGB display
Local alarm path | PASS | Priority warning screen and controlled buzzer verified
Cloud and weather data | PASS | Blynk plus Brussels outdoor temperature, time and date
External graphics storage | PASS | W25Q128 ID EF 40 18; themed backgrounds, fonts and icons
External frame memory | PASS | All 8 MB repeatedly verified and used for GUI double buffering
USB service console | PASS | MCP2221A enumerates and exchanges terminal commands over USART3
Capacitive touch | NOT TESTABLE | External GT911 FPC mechanically torn


Figure 1 — Final working dashboard with network/cloud status, outdoor temperature, indoor measurements and evaluated air quality.

# Contents

1 | Introduction and scope
2 | Requirements and success criteria
3 | System architecture
4 | Hardware design
5 | PCB implementation
6 | Manufacture and assembly
7 | Firmware and graphical interface
8 | Verification and test results
9 | Problems, corrections and lessons
10 | Improvement plan for Rev B
11 | Conclusion
Appendix A | Delivered project data
Appendix B | References

READING GUIDE
Sections 4–7 explain the implementation. Sections 8–10 contain the strongest evaluation evidence because they distinguish verified behaviour from remaining technical risks.

# 1 Introduction and scope

A single PCB that senses, informs, communicates and warns

The Smart Home Hub was conceived as a compact wall-mounted room controller and environmental monitor. It collects indoor measurements, presents them locally on a 480 × 272 display, publishes selected values remotely, retrieves location-aware outdoor information and raises an alert when an abnormal condition persists. The project deliberately combines digital buses, analog sensing, a high-pin-count RGB interface, switch-mode power conversion, external memory, USB and radio communication so that the PCB exercises the complete Advanced PCB workflow.

## 1.1 Functional scope

- Measure CO₂ concentration, temperature and humidity using the SCD41 on I²C4.
- Measure barometric pressure and relative gas resistance using the BME688 on I²C3; retain its temperature as a PCB/heater diagnostic.
- Monitor a phototransistor flame channel through ADC1/PA1 and an active-low comparator output on PH2.
- Show compensated room temperature/humidity, CO₂, pressure, air-quality interpretation, Wi-Fi/cloud state, local time/date and outdoor temperature on the 4.3-inch RGB display.
- Maintain flame and persistent gas-change monitoring in the background; display a warning and sound the buzzer when alarm criteria are met.
- Connect the ESP-01 through USART1 for Wi-Fi, Blynk and weather/time HTTP; use the MCP2221A on USART3 for PC service commands.

## 1.2 Deliberate limitations

The board is a laboratory prototype rather than a certified appliance. No claim is made for calibrated gas identification, fire-alarm compliance, long-term environmental accuracy, EMC or electrical-safety certification. The BME688 gas channel is a relative baseline-change detector and does not report a validated gas concentration in ppm. Plain HTTP is used only as a laboratory compatibility workaround for the installed ESP-01 firmware.

## 1.3 Evaluation evidence

Evidence comes from the archived Altium project, production data, schematic and PCB documentation, assembly observations, firmware source and repeatable bench tests. PASS is reserved for an observed end-to-end path. The GT911 touch function is marked NOT TESTABLE because its external flex is torn rather than because the PCB interface failed.

# 2 Requirements and success criteria

ID | Requirement | Acceptance evidence | Status
R1 | 5 V input and stable 3.3 V rail | Power-up without overheating; regulated rail present | PASS
R2 | STM32 boots and can be programmed | SWD programming and integrated firmware execution | PASS
R3 | Environmental sensing | Credible SCD41 and BME688 data | PASS
R4 | Local display | Legible dashboard; smooth double-buffered updates | PASS
R5 | Abnormal-condition alert | Priority screen and controlled buzzer | PASS
R6 | Wi-Fi/cloud link | ESP-01 joins AP; Blynk update succeeds | PASS
R7 | QSPI asset storage | JEDEC ID plus read/write and asset loading | PASS
R8 | SDRAM | Repeated full 8 MB test at 0xC0000000 | PASS
R9 | Capacitive touch | GT911 enumeration and coordinate reports | NOT TESTABLE
R10 | USB-to-UART contingency | COM enumeration and bidirectional terminal commands | PASS

DEFINITION OF DONE
The prototype is demonstrable when the MCU, display, environmental sensors, local alarm, Wi-Fi telemetry, memories and PC service interface operate together. Touch remains an external mechanical limitation and is disclosed separately.

# 3 System architecture

Domain separation simplifies design, bring-up and fault isolation

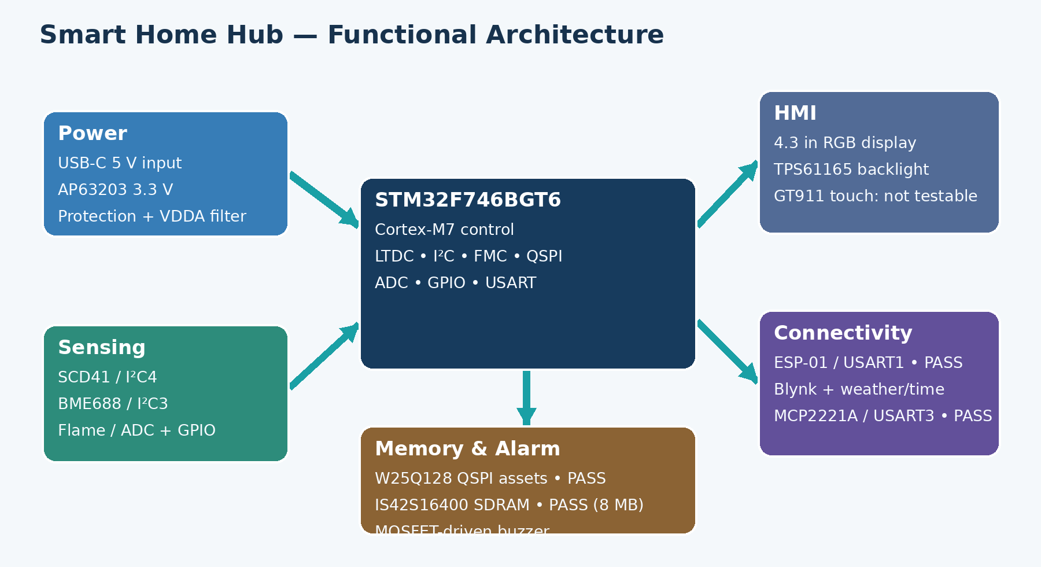
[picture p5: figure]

Figure 2 — Functional architecture and final verification state.

## 3.1 Interface allocation

MCU resource | Connected block | Purpose
LTDC / RGB | MDT0430A01ISC-RGB | 480 × 272 parallel pixel data and timing
I²C4 | SCD41 | Compensated room CO₂, temperature and humidity
I²C3 | BME688 | Pressure, gas resistance and PCB thermal diagnostics
ADC1 IN1 / PA1 | Flame A0 | Continuous analog optical response
GPIO PH2 | Flame D0 | Active-low comparator alarm
USART1 | ESP-01 | AT commands, Wi-Fi, Blynk and weather/time HTTP
USART3 | MCP2221A | Bidirectional USB PC service console
QUADSPI | W25Q128JV | Background themes, font glyphs and icons
FMC SDRAM | IS42S16400J | 8 MB framebuffers and working memory
GPIO | Buzzer MOSFET | Default-off low-side alarm switching

# 4 Hardware design

Power, processing, sensing, HMI, alarm, connectivity and memory

## 4.1 Power entry, protection and conversion

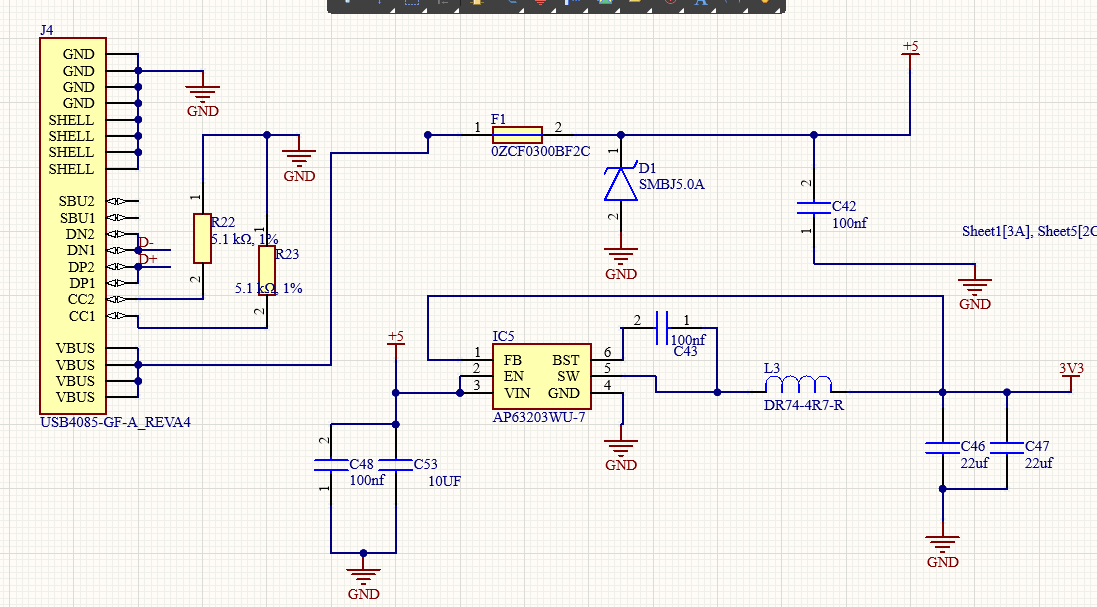
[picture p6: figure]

Figure 3 — USB-C power entry, protection and AP63203 3.3 V buck converter.

The hub is powered from a 5 V adapter rated for 3–5 A. The USB-C receptacle is configured as a sink with 5.1 kΩ pull-downs on CC1 and CC2. Joined VBUS pins feed a resettable fuse and 5 V TVS device before the protected rail reaches the load. The AP63203 synchronous buck converts 5 V to 3.3 V using local ceramic input, bootstrap and output capacitors and a shielded inductor.

The 5 V rail also supplies the display backlight and buzzer. The 3.3 V plane supplies the STM32 digital domain, sensors, memories, MCP2221A I/O and ESP-01. A ferrite-bead branch supplies VDDA to reduce switching noise before the ADC/reference domain.

BRING-UP RULE
Fit the MCU decoupling capacitors before functional testing. A Cortex-M7 may appear to boot without every 100 nF capacitor, but that is not a robust or valid hardware test.

# 4.2 MCU supply, clocking and display backlight

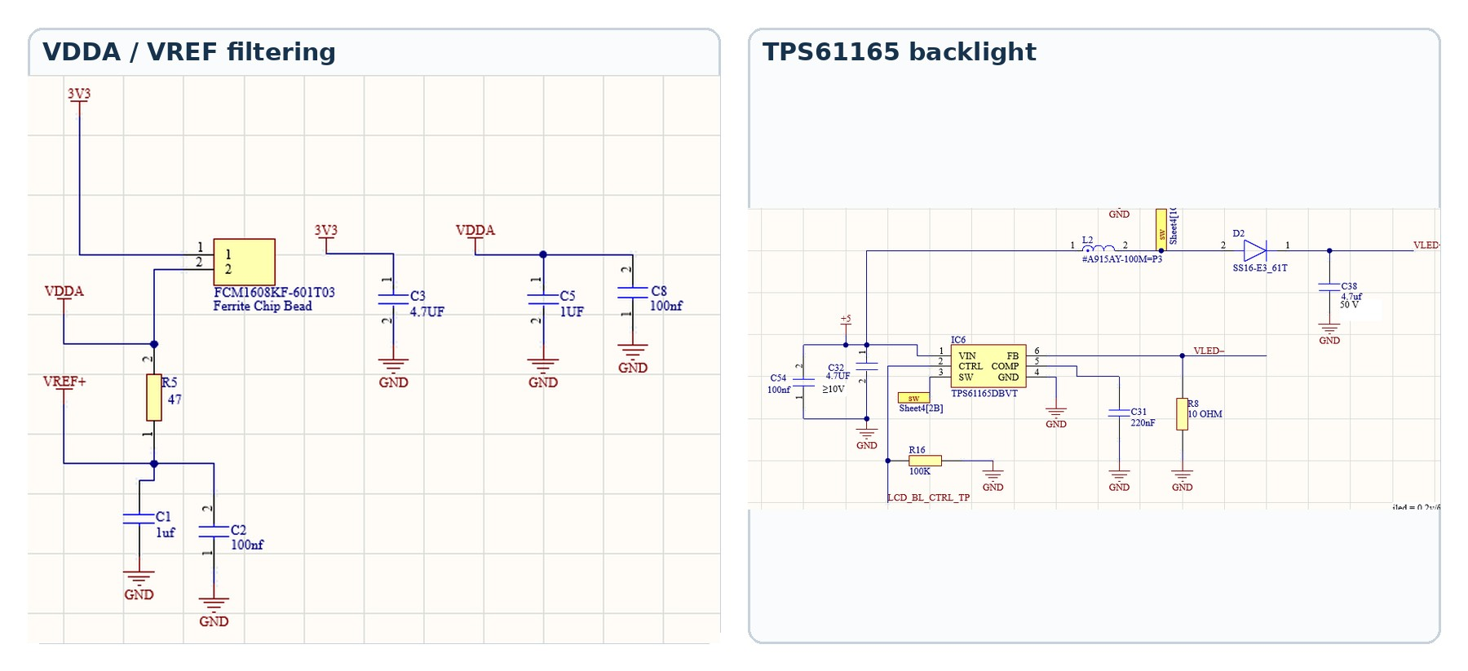
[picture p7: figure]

Figure 4 — Analog-supply filtering and the TPS61165 constant-current backlight stage.

## MCU and analog reference

The STM32F746BGT6 is powered at 3.3 V with one 100 nF ceramic capacitor per VDD group and nearby bulk capacitance. VDDA is fed through the FCM1608KF-601T03 ferrite bead and locally decoupled. VREF+ is derived through 47 Ω and separately filtered, providing a quiet reference for the flame-sensor ADC.

The clock tree uses a 32.768 kHz low-speed crystal and an 8 MHz oscillator module. The final system runs at 200 MHz HCLK, while the FMC SDRAM clock is approximately 66 MHz.

## Display and backlight

The 40-contact display flex carries 24-bit RGB, pixel clock, display enable and synchronization. The TPS61165 regulates LED-string current. CTRL is driven by the STM32 and has a 100 kΩ pull-down, so the backlight remains off while the MCU is unpowered. The boost output capacitor is rated for the LED-string voltage.

ASSEMBLY CORRECTION
The first backlight test failed because the external Schottky diode was fitted with reversed polarity. Correcting its orientation restored operation; the 4.7 µF / 50 V output capacitor was not the root cause.

# 4.3 Environmental sensing and compensation

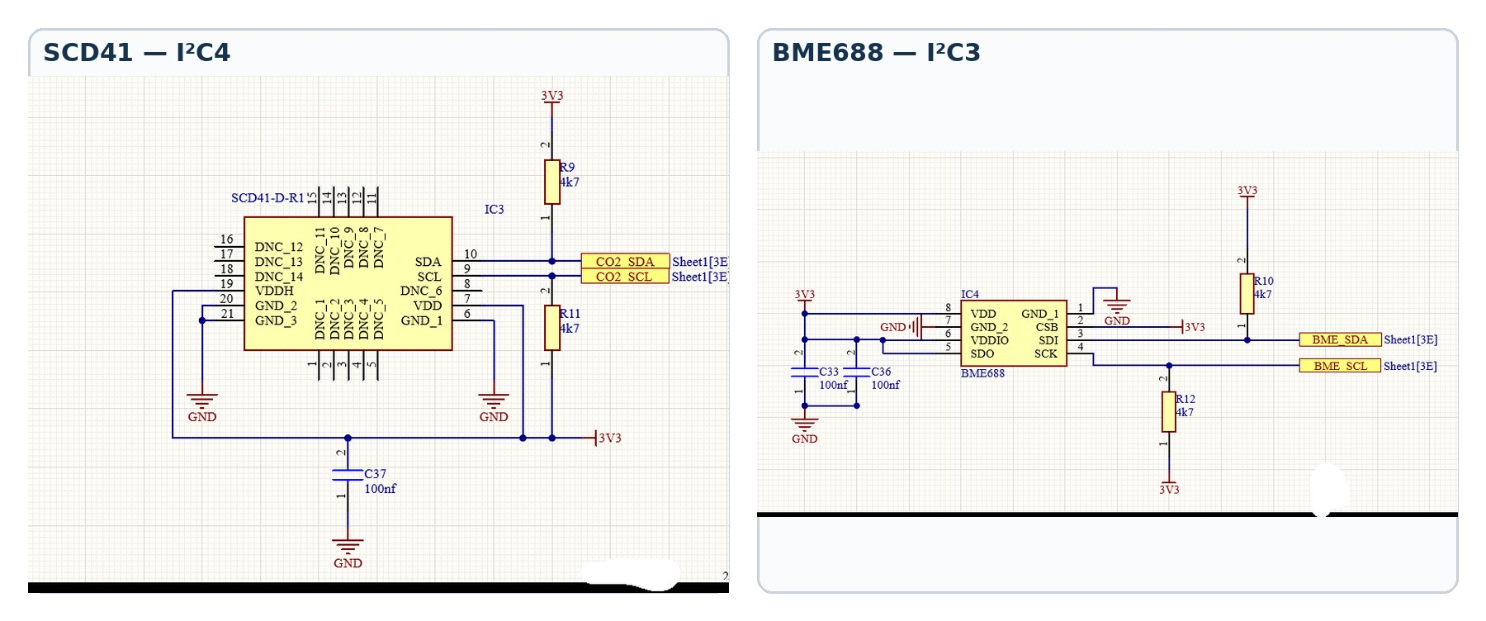
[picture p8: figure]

Figure 5 — Separate I²C buses and local pull-ups for the SCD41 and BME688.

The SCD41 is powered from 3.3 V and connected to I²C4 with 4.7 kΩ pull-ups. It is the authoritative source for room CO₂, temperature and relative humidity. Because the assembled display/PCB heats the local air, firmware programs a board-specific 9.3 °C SCD4x temperature offset at boot and applies 1/4 IIR smoothing. The compensated SCD41 values drive the dashboard, Blynk V4/V5 and room temperature/humidity alarms.

The BME688 is connected to I²C3 with independent VDD/VDDIO decoupling. CSB selects I²C mode, and firmware checks addresses 0x76 and 0x77. Pressure and gas resistance are used operationally. BME688 temperature remains visible in diagnostics as an indicator of PCB/heater conditions rather than the displayed room temperature.

## Relative gas-change interpretation

After 60 valid heater-stable samples at 5 s intervals (about 5 min in clean air), the firmware establishes a baseline. An alarm requires a persistent change of roughly 30% from baseline for four consecutive samples (about 20 s). It clears only after the value returns within roughly 15% for six samples (about 30 s). This persistence and hysteresis suppress nuisance alarms while retaining sensitivity to a sustained change.

CALIBRATION CAUTION
The 9.3 °C SCD41 offset is installation-specific and must be recalibrated if the enclosure, display heating, airflow or sensor placement changes. Neither sensor result is a traceable calibration certificate.

# 4.4 Flame detector and audible alarm

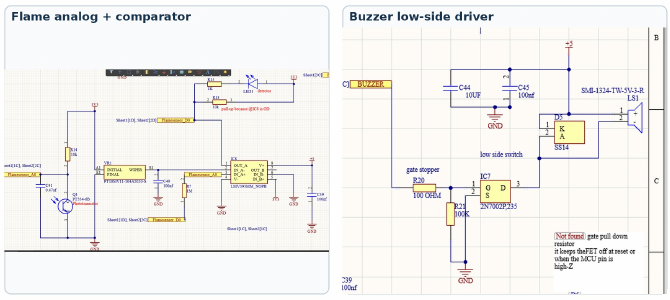
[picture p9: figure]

Figure 6 — Dual analog/digital flame path and default-off buzzer driver.

The PT334-6B phototransistor creates a light-dependent voltage at Flamesensor_A0. A 10 kΩ pull-up converts photocurrent to voltage and a 0.47 µF capacitor reduces high-frequency noise. PA1 samples this node using ADC1. The LMV393 compares the signal with the potentiometer threshold and generates an open-drain active-low D0 signal on PH2; a 10 kΩ pull-up defines the logic level and a local LED indicates detection.

The buzzer is supplied from 5 V and switched on the low side by a 2N7002 MOSFET. A 100 Ω gate resistor limits edge current, while the essential 100 kΩ gate-to-ground resistor keeps the MOSFET off during reset so the buzzer does not sound immediately at power-up.

Condition | Analog observation | Comparator | System response
No flame | A0 ≈ 3.19 V / ADC ≈3950 | D0 high | Buzzer off
Lighter presented | A0 ≈ 1.5 V / ADC ≈1730 | D0 low | Priority alarm logic active

SENSOR LIMITATION
A phototransistor can respond to sunlight, lamps and infrared sources. The dual analog/digital path aids diagnosis but is not a certified flame detector.

# 4.5 Connectivity and service interfaces

Interface | Electrical link | Purpose | Observed state
ESP-01 | USART1 | Wi-Fi AT command link | PASS — WLAN, TCP, Blynk and weather/time
MCP2221A | USB D+/D−; USART3 | PC service/debug console | PASS — enumerates and exchanges commands
SWD | SWDIO / SWCLK / NRST | Programming and debug | PASS — essential bring-up path
Test pads | Power/control nets | Probe access and rework | Included where practical

## ESP-01 and cloud path

The ESP-01 operates at 3.3 V on USART1. Firmware confirms AT operation, joins the configured access point, opens TCP connections, updates Blynk and retrieves Brussels weather/time data. The working laboratory build uses plain HTTP on port 80 because the installed ESP AT firmware could not complete current TLS negotiation.

## MCP2221A USB service console — resolved

The MCP2221A initially stopped enumerating and D+ measured shorted to ground. Continuity inspection isolated the fault to the USBLC6-2SC6 protection pin/path. After removing the short/reworking the device, Windows enumeration returned, the Microchip utility read the bridge configuration and bidirectional UART traffic was verified. PC10/USART3_TX drives MCP2221A URX; PC11/USART3_RX receives MCP2221A UTX at 115200 8N1.

The service console accepts HELP, PING, INFO, STATUS, SENSORS, NETWORK and MEMORY. A PING→PONG round trip proves the complete PC→USB→MCP2221A→STM32→MCP2221A→USB→PC path.

SECURITY IMPROVEMENT
Plain HTTP is acceptable only as a laboratory diagnostic. A deployable product should use current TLS, certificate validation and secure credential provisioning.

# 4.6 External memory

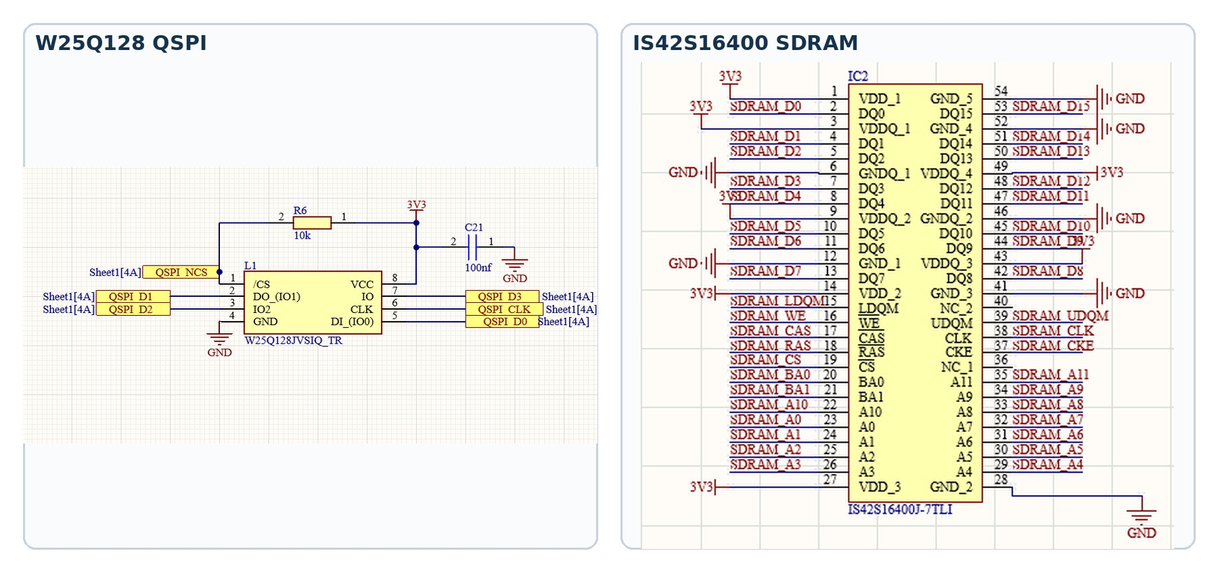
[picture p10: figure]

Figure 7 — External W25Q128 QSPI flash and 16-bit IS42S16400 SDRAM interfaces.

## W25Q128JV QSPI flash

The 128-Mbit W25Q128JV provides 16 MB of non-volatile storage. /CS has a 10 kΩ pull-up so the flash remains deselected during reset. Firmware read JEDEC ID EF 40 18 and verified erase/program/read in a reserved region. The final build stores time/condition-themed backgrounds, the modern font and GUI icons in QSPI.

## IS42S16400J SDRAM

The 64-Mbit SDR SDRAM is connected to the FMC through a 16-bit data bus plus address, bank, byte-mask, clock, enable and command signals. Startup issues clock-enable, precharge-all, auto-refresh and mode-register commands before programming refresh. Rework and a clean CubeMX FMC pin/timing configuration converted an early mismatch into a repeatable full-capacity PASS.

Item | Verified result
Base address | 0xC0000000
Capacity exercised | 8 MB / complete address range
Diagnostic clock | Approximately 66 MHz
Test | Address + multiple data patterns, repeated
Production use | Two 480 × 272 L8 GUI buffers plus working memory

MEMORY ROLE SEPARATION
QSPI is persistent asset storage; SDRAM is volatile framebuffer/working memory; internal SRAM holds stacks, drivers and compact control state.

# 5 PCB implementation

Four-layer stack, plane strategy, routing and design-rule control

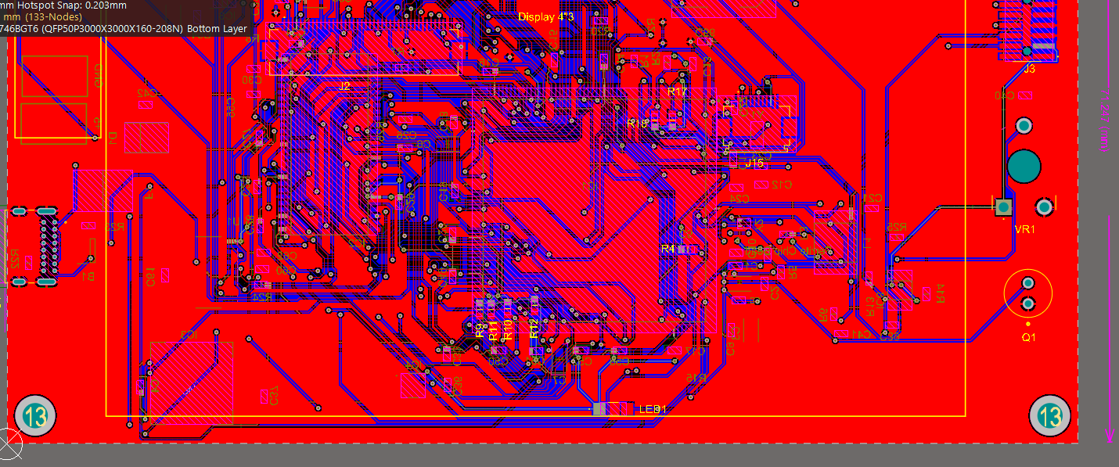
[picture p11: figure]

Figure 8 — Altium PCB view with top/bottom routing and internal planes visible.

Layer | Assignment | Design intent
Top | Signal + components | Dense STM32, memory and display escape routing
Layer 1 | GND plane | Low-impedance return path and reference plane
Layer 2 | 3V3 plane | Main low-voltage distribution
Bottom | Signal + components | Secondary routing, connectors and peripheral circuits

## 5.1 Placement and routing strategy

The STM32, SDRAM and QSPI flash occupy the dense central region to minimize parallel-bus length. The display connector sits at the edge to suit the flex direction. Power conversion remains near USB-C, while the optical flame sensor and threshold control are near the perimeter. Situs autorouting provided a starting point, followed by visual review and manual cleanup of power distribution, plane connections and constrained areas.

- Reference high-frequency signals to an uninterrupted ground plane and avoid return-current detours.
- Place each 100 nF decoupler beside its supply pin group with a short pad-to-via loop.
- Keep the backlight SW/inductor loop compact and away from analog/sensor signals.
- Use wide copper for 5 V backlight/buzzer current and the 3.3 V regulator output.

# 5.2 Design-rule and manufacturing checks

The board was checked for electrical clearance, routing width, via geometry, solder-mask slivers, silkscreen-to-mask clearance, component clearance and power-plane relief. Rules that generated excessive warnings were aligned with the selected fabricator's published capability; individual geometry errors were corrected rather than hidden by globally disabling checks.

Review item | Final treatment
Copper clearance / width | Checked against the selected fabricator's limits
Solder-mask slivers | Rule aligned with process capability; dense-pad cases manually reviewed
Silkscreen clearance | Overlay moved where it could interfere with soldering
Plane thermal relief | Blocked-spoke warnings reviewed at USB-C and plane-connected pads
Hole geometry | Four overlapping NPTH features corrected after CAM feedback

PLANE CONNECTIVITY
Layer 1 is assigned to GND and Layer 2 to 3V3. Plane-net assignment, repour, zero unrouted nets and final DRC are all required; a visually filled plane alone does not prove connectivity.

# 6 Manufacture and assembly


(a) Component side of the functional PCB. | (b) Rear/connector side with display interfaces, ESP-01 and USB.

Figure 9 — Assembled four-layer prototype, shown from both sides.

## 6.1 Production package

Output | Purpose
Gerber / layer outputs | Copper, mask, overlay, paste and mechanical data
NC drill | Plated, non-plated, round and slot holes
Pick-and-place + BOM | Centroids/orientations and fitted-part information
Draftsman | Fabrication, assembly and drill drawings
DRC / ERC / differences | Design verification records
STEP | Board-level 3D exchange model

## 6.2 Fabrication query and assembly lessons

The fabricator identified four overlapping non-plated holes and asked whether the final diameter should be 3.45 mm or 3.2 mm. The source geometry was corrected before production. The most important component-level faults were also diagnosed systematically: the reversed TPS61165 Schottky diode, FMC/SDRAM solder/configuration issues and the USBLC6-2SC6 D+ short.

# 7 Firmware and graphical interface

Non-blocking acquisition, compensated values, local alarms and external-memory graphics

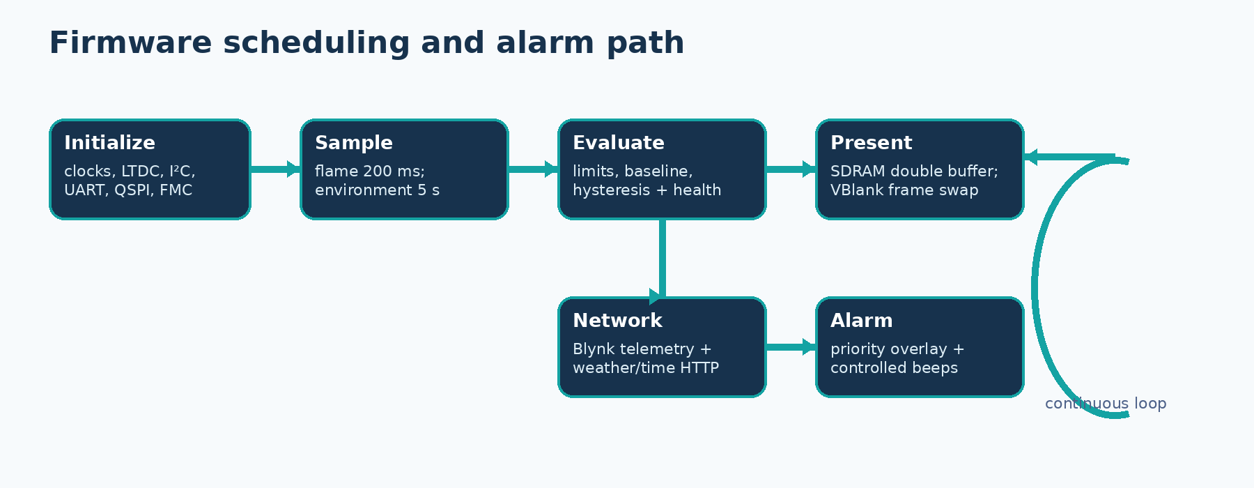
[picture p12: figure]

Figure 10 — Cooperative time-based scheduler used by the integrated firmware.

## 7.1 Peripheral configuration

Peripheral | Role
LTDC | 480 × 272 RGB timing with SDRAM-backed L8 layers
I²C3 / I²C4 | BME688 and SCD41 on separate buses
ADC1 / GPIO | Flame analog PA1, D0 PH2 and buzzer control
USART1 | ESP-01 AT commands and internet services
USART3 | MCP2221A bidirectional PC service console
QUADSPI | W25Q128 background/font/icon assets
FMC | 8 MB SDRAM diagnostics and GUI framebuffers

## 7.2 Timing and fault isolation

HAL_GetTick() schedules the cooperative main loop. Flame sampling runs every 200 ms; environmental acquisition approximately every 5 s; GUI refresh every 500 ms; Blynk upload every 10 s; Wi-Fi retry every 30 s; and weather/time retrieval at a slower interval. Each service owns an independent status so a failed cloud request does not disable local sensing or alarms.

# 7.3 Final graphical dashboard

Figure 11 — Final QSPI-themed, SDRAM-double-buffered dashboard with live local and internet data.

The top bar shows the clock, Wi-Fi/cloud icons and date. The centre shows the configured location and outdoor temperature. Indoor values use a two-column layout: compensated SCD41 room temperature/humidity on the left, and SCD41 CO₂ plus BME688 pressure on the right. The air-quality state and explanation remain visible below. Raw flame, gas and BME temperature continue in diagnostics/background monitoring and do not clutter the normal screen.

Flicker was removed by drawing the next dynamic layer into the inactive 480 × 272 L8 buffer in SDRAM, cleaning the relevant Cortex-M7 cache range and swapping the LTDC layer address during vertical blanking. QSPI supplies the themed background, modern font and icons; only a complete, ready frame is presented.

MEMORY USAGE
Two L8 GUI buffers consume about 255 KiB of SDRAM. QSPI supplies persistent assets without enlarging internal flash, and internal SRAM remains available for the scheduler, network parser and drivers.

# 7.4 Cloud data and alarm policy

Blynk datastream | Content | Representation
V0–V2 | Flame state, ADC and voltage | Boolean / raw / V
V3 | SCD41 CO₂ | ppm
V4 / V5 | Compensated SCD41 room T / RH | °C / %RH
V6 / V7 | BME688 temperature / humidity diagnostics | °C / %RH
V8 | BME688 pressure | hPa
V9–V11 | Gas resistance, ratio and alarm | Ω / % / Boolean

Measurements are batched where possible; flame state changes can be sent immediately. A separate HTTP request obtains Brussels outdoor temperature and the HTTP Date header supplies local date/time. The parser anchors on the actual HTTP/1.x header within the ESP-01 transcript, skips the header terminator and parses the signed body value.

## Alarm philosophy

- Local indication and buzzer control never depend on Wi-Fi or Blynk availability.
- SCD41 compensated values drive room temperature/humidity decisions; BME temperature is diagnostic only.
- Gas detection arms only after a stable baseline and uses persistence plus clear hysteresis.
- The physical MOSFET gate pull-down guarantees buzzer-off during reset.
- Flame has priority; severe persistent environmental conditions can also produce a priority screen and buzzer pattern.

# 8 Verification and test results

Bench evidence for every major subsystem

## 8.1 Incremental method

Power rails and control pins were measured before firmware integration. Each digital peripheral was first tested with a narrow diagnostic program and only then added to the combined dashboard. The display was an immediate local test surface; the MCP2221A/USART3 console provided persistent diagnostic responses.

- Power — verify 5 V, regulated 3.3 V, acceptable current and repeatable MCU boot.
- Sensors — confirm I²C acknowledgement, manufacturer command sequence and plausible live values.
- Flame/buzzer — compare ADC voltage and D0/LED state, then verify controlled sounder behaviour.
- Connectivity — verify ESP AT responses, WLAN, Blynk, weather/time parsing and MCP terminal round trips.
- Memory — read QSPI ID and repeat complete 8 MB SDRAM address/data-pattern tests.
- HMI — verify backlight, QSPI assets, cache maintenance, VBlank buffer swapping and alarm priority.

## 8.2 Integrated demonstration snapshots

Snapshot | Outdoor | Room T / RH | CO₂ | Pressure | Air quality
Normal GUI photo | 22 °C | 34.3 °C / 31.9 % | 675 ppm | 1005.5 hPa | GOOD
Second stable state | 24 °C | 26.3 °C / 52.7 % | 600 ppm | 1009.2 hPa | GOOD

INTERPRETATION
These snapshots prove the complete acquisition/display path. They are not calibration certificates. The installation-specific SCD41 compensation should be verified against a reference after enclosure thermal equilibrium.

# 8.3 Verification matrix

Subsystem | Status | Evidence
5 V input / AP63203 3.3 V | PASS | Rails present; MCU/peripherals operate
STM32F746 boot / SWD | PASS | Firmware programs and runs
RGB LCD + TPS61165 | PASS | Image and backlight stable after diode correction
SCD41 on I²C4 | PASS | Compensated CO₂/T/RH integrated
BME688 on I²C3 | PASS | Pressure/gas and diagnostics acquired
Flame A0 / D0 | PASS | ADC and active-low D0 respond
Buzzer driver | PASS | Controlled by STM32; silent at reset
ESP-01 / Blynk / weather | PASS | AT, AP, TCP, Blynk and outdoor data
W25Q128 QSPI | PASS | EF 40 18; verified data and assets
IS42S16400 SDRAM | PASS | All 8 MB repeatedly verified at ~66 MHz
MCP2221A USB-UART | PASS | USBLC6 fault repaired; enumeration and two-way commands
GT911 touch | NOT TESTABLE | External touch FPC completely torn

## 8.4 Recommended demonstration sequence

1. Show the stable dashboard and explain the compensated indoor values.
2. Present a controlled flame or temperature alarm and the buzzer response.
3. Show a Blynk update and a weather/time refresh through the ESP-01.
4. Open the MCP2221A COM port and demonstrate PING→PONG plus SENSORS or MEMORY.
5. Run QSPI identification and the repeated full 8 MB SDRAM diagnostic.
6. Show the archived Altium source, layer stack, DRC/ERC, Draftsman, BOM, STEP and factory outputs.

# 8.5 Priority alarm evidence

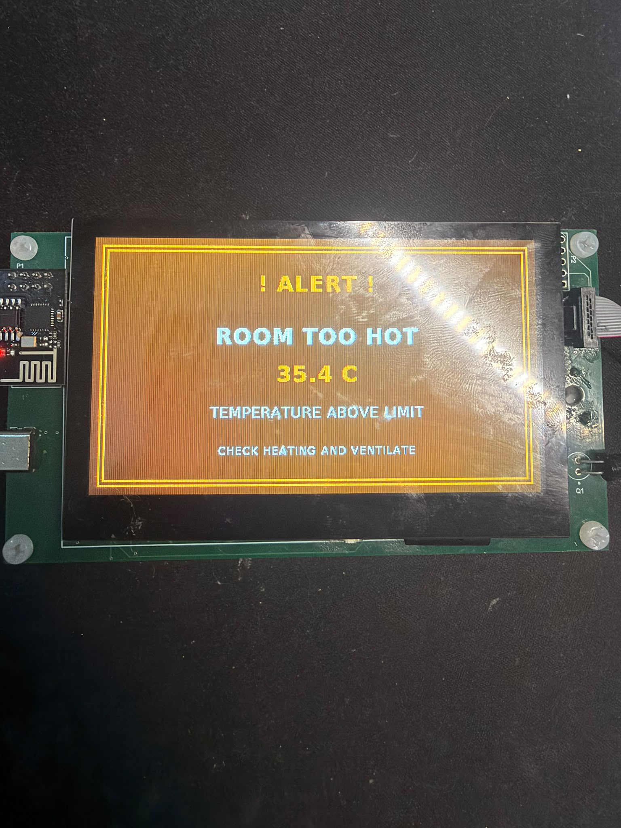
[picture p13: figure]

Figure 12 — Persistent high-temperature condition produces a priority warning screen and simultaneously activates the controlled buzzer.

The screen explicitly identifies the active condition, measured value and recommended response. The dashboard is restored after the alarm clears. This behaviour verifies the complete sensor decision → GUI priority → GPIO/MOSFET → buzzer chain rather than only an isolated buzzer test.

SAFETY STATEMENT
Alarm functions are valuable course demonstrations but remain non-certified. The hub must not replace approved smoke, flame, gas or carbon-monoxide alarms.

# 9 Problems, corrections and lessons

Failures were retained as structured engineering evidence

Symptom | Cause / status | Action | Rev-B prevention
Backlight remained off | External Schottky reversed | Corrected polarity | Larger cathode marking + checklist
Display flashed | Whole frame exposed while drawing | SDRAM double buffer + VBlank swap | Retain cache/VBlank discipline
ESP weather/SSL failed | Old TLS path; parser start wrong | HTTP and bounded HTTP-body parser | Current TLS-capable radio/firmware
MCP2221A did not enumerate | USBLC6-2SC6 D+ path shorted to GND | Continuity diagnosis + rework; full UART PASS | Verify ESD footprint; isolation/loopback pads
SDRAM mismatch | FMC conflicts plus solder/contact | Rework + clean FMC config; 8 MB PASS | Preserve production self-test
Touch unavailable | External flex mechanically torn | Removed from demonstration | Replaceable FFC + strain relief
Fabricator hole query | Four overlapping NPTH features | Corrected before production | Explicit hole-to-hole review


Figure 13 — Repeated full 8 MB SDRAM diagnostic after FMC correction and rework.

ENGINEERING LESSON
The SDRAM fault was not solved by adding bus pull-ups, and the MCP fault was not software. Repeatable electrical measurements, narrow subsystem tests and controlled rework converted both faults into repeatable PASS results.

# 10 Improvement plan for Rev B

Priority | Change | Implementation | Benefit
P1 | Touch serviceability | Replaceable FFC/assembly, strain relief and no copper at bend | Restores and protects input
P1 | Secure radio | Current TLS, certificate validation and supply margin | Removes plain-HTTP dependency
P2 | USB robustness | Keep ESD, add labelled D+/D−/TX/RX loopback and 0 Ω isolation | Faster deterministic diagnosis
P2 | Sensor thermal layout | Vented edge/peninsula away from display, MCU and inductors | Improves accuracy/response
P2 | Memory robustness | Preserve 8 MB self-test and optional series footprints | Protects framebuffer path
P2 | Manufacturing clarity | Stronger polarity/pin-1/NPTH checks and assembly drawings | Reduces rework/CAM queries
P3 | Firmware resilience | Watchdog, fault log, alarm latching, OTA and self-test | Improves maintainability

## 10.1 Validation additions

A second revision should include a written test specification covering supply current/ripple, sensor warm-up, reference-instrument comparison, gas-baseline repeatability, alarm thresholds, Wi-Fi reconnect behaviour, extended run time, temperature exposure and ESD/EMI pre-compliance. The present board proves the architecture but does not provide statistical product-validation evidence.

HIGHEST-VALUE NEXT ACTION
Replace the damaged touch assembly and improve touch-flex strain relief, then repeat sensor compensation inside the intended enclosure. Preserve the passing SDRAM and MCP service tests as production self-tests.

# 11 Conclusion

The Smart Home Hub achieved the central objective of the Advanced PCB course: a custom manufactured four-layer PCB that boots, senses the room, presents information locally, warns through an independently controlled buzzer and communicates over both Wi-Fi and USB service links. The design integrates a high-pin-count STM32, parallel RGB display, multiple I²C buses, analog comparator/ADC path, switch-mode conversion, external serial flash, parallel SDRAM and a complete production-data workflow.

Every populated/core PCB subsystem now passes end-to-end testing: stable power, STM32/SWD, display/backlight, SCD41, BME688, flame detector, buzzer, ESP-01/Blynk, internet weather/time, W25Q128 QSPI, full 8 MB SDRAM and the repaired MCP2221A/USART3 service console. The final firmware assigns memory correctly: QSPI holds persistent backgrounds, fonts and icons; SDRAM provides double-buffered GUI layers and working space; internal SRAM retains control state.

The only unavailable feature is GT911 touch input because the display assembly's external flex tail is mechanically torn. The operating hub does not depend on that input. Plain HTTP, installation-specific temperature compensation and non-certified flame/gas algorithms remain explicit development limitations rather than hidden product claims.

FINAL ASSESSMENT
The prototype is demonstrable and functionally useful for the course. Core paths, external memories, cloud data, alarm behaviour and the USB service console are verified; the remaining touch limitation and Rev-B risks are clearly documented.

## Submission talking points

- Explain the four-layer GND/3V3 plane stack and dense FMC/LTDC routing.
- Demonstrate the compensated dashboard, alarm screen and controlled buzzer.
- Show the separate QSPI asset-store and SDRAM framebuffer roles.
- Demonstrate the MCP2221A console and explain how the USBLC6 short was diagnosed.
- State the torn touch flex and safety/calibration scope without overstating the result.

# Appendix A Delivered project data

ID | Deliverable | Content | State
A1 | Archived Altium project | PrjPcb, SchDoc, PcbDoc, OutJob and STEP | READY
A2 | Production package | Factory Gerber/layer files and NC drill | READY
A3 | Smart schematic PDF | Compiled hierarchical schematic set | READY
A4 | Draftsman | Assembly, fabrication and drill drawings | READY
A5 | Bill of materials | Standalone XLSX export | READY
A6 | Verification | DRC, ERC and differences reports | READY
A7 | Firmware | STM32CubeIDE project/source and build notes | READY
A8 | Technical report | This Rev 2.1 DOCX and PDF | READY
A9 | Presentation | Project PPT for oral demonstration | READY
A10 | A4 poster | Concise project overview | PENDING

## Recommended submission folder

Folder | Contents
01_Altium_Source | Archived source project and libraries
02_Production_Data | Exact factory-accepted package
03_Schematic_PDF | Smart PDF
04_Draftsman | Assembly/fabrication/drill PDF
05_BOM | XLSX and optional PDF
06_Verification | DRC, ERC and differences
07_3D | Board STEP
08_Firmware | STM32CubeIDE project/source and notes
09_Report | DOCX and PDF
10_Presentation_Poster | PPTX and A4 poster

REPRODUCIBILITY
Keep the production package identical to the fabricator-accepted files. If outputs are regenerated later, archive them as a separate revision with an explicit reason.

# Appendix B References

[1] STMicroelectronics, STM32F746BG product page and device documentation. https://www.st.com/en/microcontrollers-microprocessors/stm32f746bg.html

[2] Sensirion, SCD41 product page, SCD4x data sheet and temperature-offset guidance. https://sensirion.com/products/catalog/SCD41

[3] Bosch Sensortec, BME688 gas sensor product documentation. https://www.bosch-sensortec.com/en/products/environmental-sensors/gas-sensors/bme688/

[4] Texas Instruments, TPS61165 high-brightness LED driver data sheet. https://www.ti.com/product/TPS61165

[5] Diodes Incorporated, AP63203 synchronous buck converter. https://www.diodes.com/part/view/AP63203

[6] Microchip Technology, MCP2221A USB-to-I²C/UART bridge. https://www.microchip.com/en-us/product/mcp2221a

[7] Integrated Silicon Solution Inc., IS42S16400J SDR SDRAM family. https://www.issi.com/US/product-dram-SDR.shtml

[8] Winbond Electronics, W25Q128JV QSPI NOR flash family. https://www.winbond.com/hq/product/code-storage-flash/qspi-nor/

[9] Blynk documentation. https://docs.blynk.io/

[10] Altium Designer documentation. https://www.altium.com/documentation/altium-designer

[11] Project evidence: archived Altium design, factory outputs, schematics, STM32CubeIDE firmware, final dashboard photographs and bench observations.

## Component naming note

Part numbers in this report follow the design and assembled prototype evidence available during preparation. The fabrication BOM, schematic libraries and fitted-component inspection remain authoritative for package, tolerance and ordering-suffix details.

Mahmoud Mostafa | Rev 2.1 · 16 August 2026 | Page 1

SMART HOME HUB | ADVANCED PCB TECHNICAL REPORT

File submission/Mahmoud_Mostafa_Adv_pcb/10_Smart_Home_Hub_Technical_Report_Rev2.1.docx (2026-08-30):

THOMAS MORE · ELECTRONICS-ICT

ADVANCED PCB PROJECT

Smart Home Hub

Four-layer STM32F746 environmental, connected-weather and alert platform

STUDENT | Mahmoud Mostafa
PROGRAMME | Professional Bachelor Electronics-ICT
COURSE | Advanced PCB: Lab · B-TM-YT6250 · 3 ECTS
LECTURER | Jurre De Weerdt
ACADEMIC YEAR | 2025–2026

AS-BUILT TECHNICAL REPORT · REVISION 2.1

# Document summary

Field | Value
Document | Smart Home Hub — Advanced PCB Project Technical Report
Revision / date | 2.1 / 16 August 2026
Project stage | Manufactured, assembled and integrated prototype; full core system demonstrated
Design tools | Altium Designer; STM32CubeMX / STM32CubeIDE
Board | Four-layer rigid PCB: Top signal / GND plane / 3V3 plane / Bottom signal
Primary MCU | STM32F746BGT6

## Abstract

This report documents the design, manufacture, assembly and bench verification of a smart-home hub developed for the Advanced PCB laboratory. The custom four-layer board is centred on an STM32F746BGT6 microcontroller and integrates a 4.3-inch RGB display, SCD41 and BME688 environmental sensors, a flame-detection front end, an audible alarm, Wi-Fi connectivity, a USB service interface and two external memories.

The final system presents location-aware outdoor information and the important indoor measurements on a QSPI-themed graphical dashboard. The SCD41 provides the compensated room temperature, relative humidity and CO₂ concentration; the BME688 provides pressure and relative gas-resistance diagnostics. Flame and persistent gas-change monitoring remain active in the background and can raise a priority on-screen warning and sound the buzzer independently of the cloud connection.

Bench testing confirms the protected 5 V input, regulated 3.3 V rail, MCU, RGB display and backlight, SCD41, BME688, flame detector, buzzer, ESP-01 Wi-Fi/Blynk link, internet time/date/outdoor temperature, W25Q128 QSPI flash, the full 8 MB IS42S16400 SDRAM and the MCP2221A USB-to-UART console. The USB bridge originally failed because the USBLC6-2SC6 D+ protection path was shorted to ground; after rework it enumerated and carried bidirectional USART3 traffic. The only remaining unavailable function is touch input because the display assembly's external GT911 flex tail is mechanically torn.

SAFETY SCOPE
This is an educational prototype. The flame and gas-change functions are not certified fire, gas-leak or life-safety detectors and must not replace approved alarms.

# Project outcome at a glance

Area | Status | Evidence
Core environmental dashboard | PASS | Live compensated SCD41 values and BME688 pressure shown on the RGB display
Local alarm path | PASS | Priority warning screen and controlled buzzer verified
Cloud and weather data | PASS | Blynk plus Brussels outdoor temperature, time and date
External graphics storage | PASS | W25Q128 ID EF 40 18; themed backgrounds, fonts and icons
External frame memory | PASS | All 8 MB repeatedly verified and used for GUI double buffering
USB service console | PASS | MCP2221A enumerates and exchanges terminal commands over USART3
Capacitive touch | NOT TESTABLE | External GT911 FPC mechanically torn

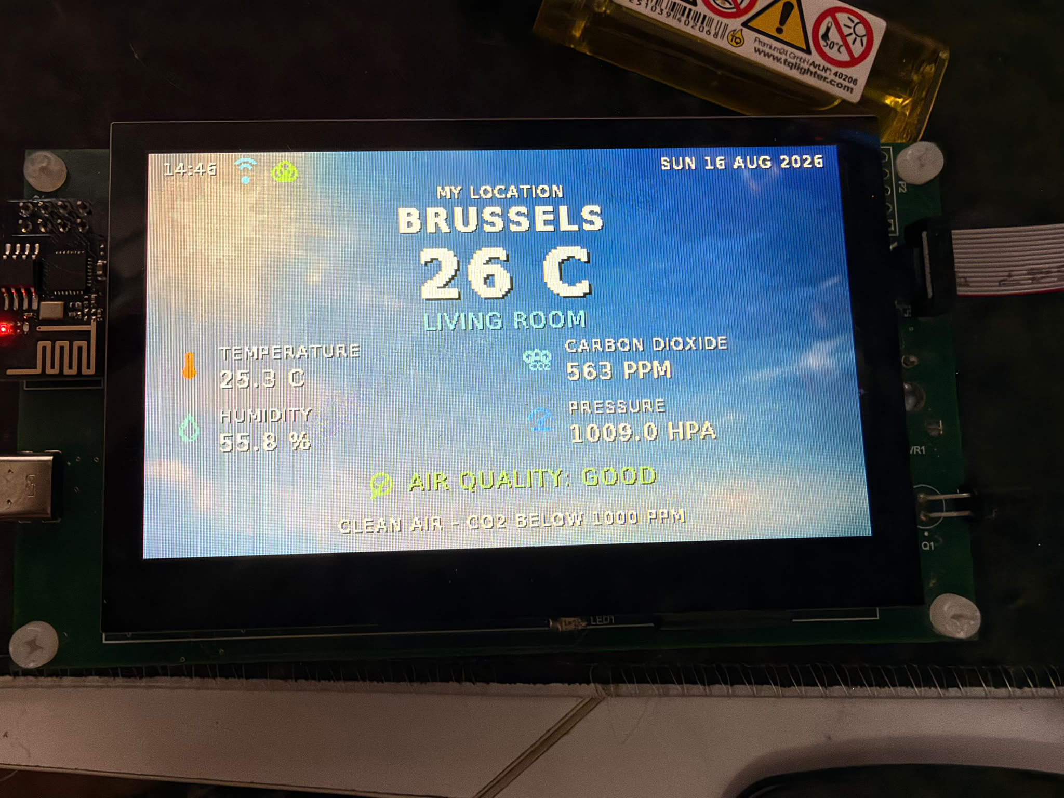
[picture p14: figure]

Figure 1 — Final working dashboard with network/cloud status, outdoor temperature, indoor measurements and evaluated air quality.

# Contents

1 | Introduction and scope
2 | Requirements and success criteria
3 | System architecture
4 | Hardware design
5 | PCB implementation
6 | Manufacture and assembly
7 | Firmware and graphical interface
8 | Verification and test results
9 | Problems, corrections and lessons
10 | Improvement plan for Rev B
11 | Conclusion
Appendix A | Delivered project data
Appendix B | References

READING GUIDE
Sections 4–7 explain the implementation. Sections 8–10 contain the strongest evaluation evidence because they distinguish verified behaviour from remaining technical risks.

# 1 Introduction and scope

A single PCB that senses, informs, communicates and warns

The Smart Home Hub was conceived as a compact wall-mounted room controller and environmental monitor. It collects indoor measurements, presents them locally on a 480 × 272 display, publishes selected values remotely, retrieves location-aware outdoor information and raises an alert when an abnormal condition persists. The project deliberately combines digital buses, analog sensing, a high-pin-count RGB interface, switch-mode power conversion, external memory, USB and radio communication so that the PCB exercises the complete Advanced PCB workflow.

## 1.1 Functional scope

- Measure CO₂ concentration, temperature and humidity using the SCD41 on I²C4.
- Measure barometric pressure and relative gas resistance using the BME688 on I²C3; retain its temperature as a PCB/heater diagnostic.
- Monitor a phototransistor flame channel through ADC1/PA1 and an active-low comparator output on PH2.
- Show compensated room temperature/humidity, CO₂, pressure, air-quality interpretation, Wi-Fi/cloud state, local time/date and outdoor temperature on the 4.3-inch RGB display.
- Maintain flame and persistent gas-change monitoring in the background; display a warning and sound the buzzer when alarm criteria are met.
- Connect the ESP-01 through USART1 for Wi-Fi, Blynk and weather/time HTTP; use the MCP2221A on USART3 for PC service commands.

## 1.2 Deliberate limitations

The board is a laboratory prototype rather than a certified appliance. No claim is made for calibrated gas identification, fire-alarm compliance, long-term environmental accuracy, EMC or electrical-safety certification. The BME688 gas channel is a relative baseline-change detector and does not report a validated gas concentration in ppm. Plain HTTP is used only as a laboratory compatibility workaround for the installed ESP-01 firmware.

## 1.3 Evaluation evidence

Evidence comes from the archived Altium project, production data, schematic and PCB documentation, assembly observations, firmware source and repeatable bench tests. PASS is reserved for an observed end-to-end path. The GT911 touch function is marked NOT TESTABLE because its external flex is torn rather than because the PCB interface failed.

# 2 Requirements and success criteria

ID | Requirement | Acceptance evidence | Status
R1 | 5 V input and stable 3.3 V rail | Power-up without overheating; regulated rail present | PASS
R2 | STM32 boots and can be programmed | SWD programming and integrated firmware execution | PASS
R3 | Environmental sensing | Credible SCD41 and BME688 data | PASS
R4 | Local display | Legible dashboard; smooth double-buffered updates | PASS
R5 | Abnormal-condition alert | Priority screen and controlled buzzer | PASS
R6 | Wi-Fi/cloud link | ESP-01 joins AP; Blynk update succeeds | PASS
R7 | QSPI asset storage | JEDEC ID plus read/write and asset loading | PASS
R8 | SDRAM | Repeated full 8 MB test at 0xC0000000 | PASS
R9 | Capacitive touch | GT911 enumeration and coordinate reports | NOT TESTABLE
R10 | USB-to-UART contingency | COM enumeration and bidirectional terminal commands | PASS

DEFINITION OF DONE
The prototype is demonstrable when the MCU, display, environmental sensors, local alarm, Wi-Fi telemetry, memories and PC service interface operate together. Touch remains an external mechanical limitation and is disclosed separately.

# 3 System architecture

Domain separation simplifies design, bring-up and fault isolation


Figure 2 — Functional architecture and final verification state.

## 3.1 Interface allocation

MCU resource | Connected block | Purpose
LTDC / RGB | MDT0430A01ISC-RGB | 480 × 272 parallel pixel data and timing
I²C4 | SCD41 | Compensated room CO₂, temperature and humidity
I²C3 | BME688 | Pressure, gas resistance and PCB thermal diagnostics
ADC1 IN1 / PA1 | Flame A0 | Continuous analog optical response
GPIO PH2 | Flame D0 | Active-low comparator alarm
USART1 | ESP-01 | AT commands, Wi-Fi, Blynk and weather/time HTTP
USART3 | MCP2221A | Bidirectional USB PC service console
QUADSPI | W25Q128JV | Background themes, font glyphs and icons
FMC SDRAM | IS42S16400J | 8 MB framebuffers and working memory
GPIO | Buzzer MOSFET | Default-off low-side alarm switching

# 4 Hardware design

Power, processing, sensing, HMI, alarm, connectivity and memory

## 4.1 Power entry, protection and conversion


Figure 3 — USB-C power entry, protection and AP63203 3.3 V buck converter.

The hub is powered from a 5 V adapter rated for 3–5 A. The USB-C receptacle is configured as a sink with 5.1 kΩ pull-downs on CC1 and CC2. Joined VBUS pins feed a resettable fuse and 5 V TVS device before the protected rail reaches the load. The AP63203 synchronous buck converts 5 V to 3.3 V using local ceramic input, bootstrap and output capacitors and a shielded inductor.

The 5 V rail also supplies the display backlight and buzzer. The 3.3 V plane supplies the STM32 digital domain, sensors, memories, MCP2221A I/O and ESP-01. A ferrite-bead branch supplies VDDA to reduce switching noise before the ADC/reference domain.

BRING-UP RULE
Fit the MCU decoupling capacitors before functional testing. A Cortex-M7 may appear to boot without every 100 nF capacitor, but that is not a robust or valid hardware test.

# 4.2 MCU supply, clocking and display backlight


Figure 4 — Analog-supply filtering and the TPS61165 constant-current backlight stage.

## MCU and analog reference

The STM32F746BGT6 is powered at 3.3 V with one 100 nF ceramic capacitor per VDD group and nearby bulk capacitance. VDDA is fed through the FCM1608KF-601T03 ferrite bead and locally decoupled. VREF+ is derived through 47 Ω and separately filtered, providing a quiet reference for the flame-sensor ADC.

The clock tree uses a 32.768 kHz low-speed crystal and an 8 MHz oscillator module. The final system runs at 200 MHz HCLK, while the FMC SDRAM clock is approximately 66 MHz.

## Display and backlight

The 40-contact display flex carries 24-bit RGB, pixel clock, display enable and synchronization. The TPS61165 regulates LED-string current. CTRL is driven by the STM32 and has a 100 kΩ pull-down, so the backlight remains off while the MCU is unpowered. The boost output capacitor is rated for the LED-string voltage.

ASSEMBLY CORRECTION
The first backlight test failed because the external Schottky diode was fitted with reversed polarity. Correcting its orientation restored operation; the 4.7 µF / 50 V output capacitor was not the root cause.

# 4.3 Environmental sensing and compensation


Figure 5 — Separate I²C buses and local pull-ups for the SCD41 and BME688.

The SCD41 is powered from 3.3 V and connected to I²C4 with 4.7 kΩ pull-ups. It is the authoritative source for room CO₂, temperature and relative humidity. Because the assembled display/PCB heats the local air, firmware programs a board-specific 9.3 °C SCD4x temperature offset at boot and applies 1/4 IIR smoothing. The compensated SCD41 values drive the dashboard, Blynk V4/V5 and room temperature/humidity alarms.

The BME688 is connected to I²C3 with independent VDD/VDDIO decoupling. CSB selects I²C mode, and firmware checks addresses 0x76 and 0x77. Pressure and gas resistance are used operationally. BME688 temperature remains visible in diagnostics as an indicator of PCB/heater conditions rather than the displayed room temperature.

## Relative gas-change interpretation

After 60 valid heater-stable samples at 5 s intervals (about 5 min in clean air), the firmware establishes a baseline. An alarm requires a persistent change of roughly 30% from baseline for four consecutive samples (about 20 s). It clears only after the value returns within roughly 15% for six samples (about 30 s). This persistence and hysteresis suppress nuisance alarms while retaining sensitivity to a sustained change.

CALIBRATION CAUTION
The 9.3 °C SCD41 offset is installation-specific and must be recalibrated if the enclosure, display heating, airflow or sensor placement changes. Neither sensor result is a traceable calibration certificate.

# 4.4 Flame detector and audible alarm


Figure 6 — Dual analog/digital flame path and default-off buzzer driver.

The PT334-6B phototransistor creates a light-dependent voltage at Flamesensor_A0. A 10 kΩ pull-up converts photocurrent to voltage and a 0.47 µF capacitor reduces high-frequency noise. PA1 samples this node using ADC1. The LMV393 compares the signal with the potentiometer threshold and generates an open-drain active-low D0 signal on PH2; a 10 kΩ pull-up defines the logic level and a local LED indicates detection.

The buzzer is supplied from 5 V and switched on the low side by a 2N7002 MOSFET. A 100 Ω gate resistor limits edge current, while the essential 100 kΩ gate-to-ground resistor keeps the MOSFET off during reset so the buzzer does not sound immediately at power-up.

Condition | Analog observation | Comparator | System response
No flame | A0 ≈ 3.19 V / ADC ≈3950 | D0 high | Buzzer off
Lighter presented | A0 ≈ 1.5 V / ADC ≈1730 | D0 low | Priority alarm logic active

SENSOR LIMITATION
A phototransistor can respond to sunlight, lamps and infrared sources. The dual analog/digital path aids diagnosis but is not a certified flame detector.

# 4.5 Connectivity and service interfaces

Interface | Electrical link | Purpose | Observed state
ESP-01 | USART1 | Wi-Fi AT command link | PASS — WLAN, TCP, Blynk and weather/time
MCP2221A | USB D+/D−; USART3 | PC service/debug console | PASS — enumerates and exchanges commands
SWD | SWDIO / SWCLK / NRST | Programming and debug | PASS — essential bring-up path
Test pads | Power/control nets | Probe access and rework | Included where practical

## ESP-01 and cloud path

The ESP-01 operates at 3.3 V on USART1. Firmware confirms AT operation, joins the configured access point, opens TCP connections, updates Blynk and retrieves Brussels weather/time data. The working laboratory build uses plain HTTP on port 80 because the installed ESP AT firmware could not complete current TLS negotiation.

## MCP2221A USB service console — resolved

The MCP2221A initially stopped enumerating and D+ measured shorted to ground. Continuity inspection isolated the fault to the USBLC6-2SC6 protection pin/path. After removing the short/reworking the device, Windows enumeration returned, the Microchip utility read the bridge configuration and bidirectional UART traffic was verified. PC10/USART3_TX drives MCP2221A URX; PC11/USART3_RX receives MCP2221A UTX at 115200 8N1.

The service console accepts HELP, PING, INFO, STATUS, SENSORS, NETWORK and MEMORY. A PING→PONG round trip proves the complete PC→USB→MCP2221A→STM32→MCP2221A→USB→PC path.

SECURITY IMPROVEMENT
Plain HTTP is acceptable only as a laboratory diagnostic. A deployable product should use current TLS, certificate validation and secure credential provisioning.

# 4.6 External memory


Figure 7 — External W25Q128 QSPI flash and 16-bit IS42S16400 SDRAM interfaces.

## W25Q128JV QSPI flash

The 128-Mbit W25Q128JV provides 16 MB of non-volatile storage. /CS has a 10 kΩ pull-up so the flash remains deselected during reset. Firmware read JEDEC ID EF 40 18 and verified erase/program/read in a reserved region. The final build stores time/condition-themed backgrounds, the modern font and GUI icons in QSPI.

## IS42S16400J SDRAM

The 64-Mbit SDR SDRAM is connected to the FMC through a 16-bit data bus plus address, bank, byte-mask, clock, enable and command signals. Startup issues clock-enable, precharge-all, auto-refresh and mode-register commands before programming refresh. Rework and a clean CubeMX FMC pin/timing configuration converted an early mismatch into a repeatable full-capacity PASS.

Item | Verified result
Base address | 0xC0000000
Capacity exercised | 8 MB / complete address range
Diagnostic clock | Approximately 66 MHz
Test | Address + multiple data patterns, repeated
Production use | Two 480 × 272 L8 GUI buffers plus working memory

MEMORY ROLE SEPARATION
QSPI is persistent asset storage; SDRAM is volatile framebuffer/working memory; internal SRAM holds stacks, drivers and compact control state.

# 5 PCB implementation

Four-layer stack, plane strategy, routing and design-rule control

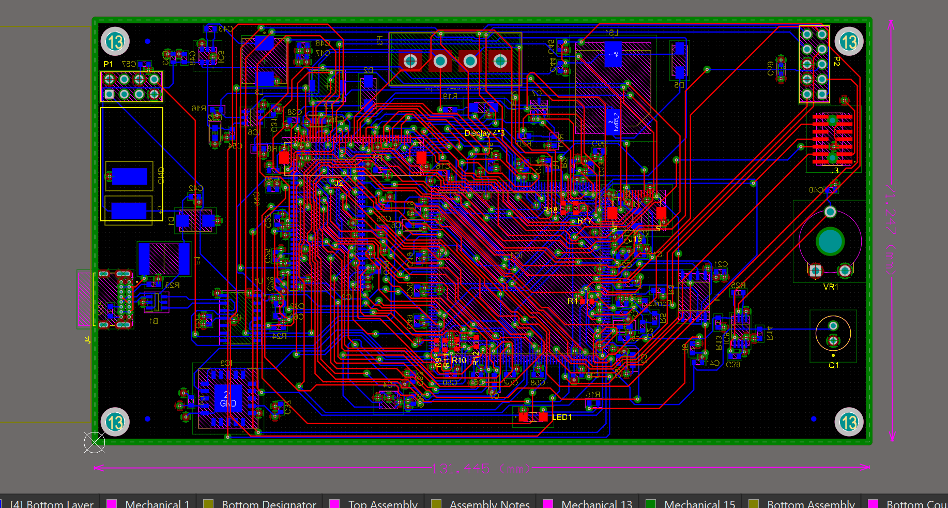
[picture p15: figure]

Figure 8 — Altium PCB view with top/bottom routing and internal planes visible.

Layer | Assignment | Design intent
Top | Signal + components | Dense STM32, memory and display escape routing
Layer 1 | GND plane | Low-impedance return path and reference plane
Layer 2 | 3V3 plane | Main low-voltage distribution
Bottom | Signal + components | Secondary routing, connectors and peripheral circuits

## 5.1 Placement and routing strategy

The STM32, SDRAM and QSPI flash occupy the dense central region to minimize parallel-bus length. The display connector sits at the edge to suit the flex direction. Power conversion remains near USB-C, while the optical flame sensor and threshold control are near the perimeter. Situs autorouting provided a starting point, followed by visual review and manual cleanup of power distribution, plane connections and constrained areas.

- Reference high-frequency signals to an uninterrupted ground plane and avoid return-current detours.
- Place each 100 nF decoupler beside its supply pin group with a short pad-to-via loop.
- Keep the backlight SW/inductor loop compact and away from analog/sensor signals.
- Use wide copper for 5 V backlight/buzzer current and the 3.3 V regulator output.

# 5.2 Design-rule and manufacturing checks

The board was checked for electrical clearance, routing width, via geometry, solder-mask slivers, silkscreen-to-mask clearance, component clearance and power-plane relief. Rules that generated excessive warnings were aligned with the selected fabricator's published capability; individual geometry errors were corrected rather than hidden by globally disabling checks.

Review item | Final treatment
Copper clearance / width | Checked against the selected fabricator's limits
Solder-mask slivers | Rule aligned with process capability; dense-pad cases manually reviewed
Silkscreen clearance | Overlay moved where it could interfere with soldering
Plane thermal relief | Blocked-spoke warnings reviewed at USB-C and plane-connected pads
Hole geometry | Four overlapping NPTH features corrected after CAM feedback

PLANE CONNECTIVITY
Layer 1 is assigned to GND and Layer 2 to 3V3. Plane-net assignment, repour, zero unrouted nets and final DRC are all required; a visually filled plane alone does not prove connectivity.

# 6 Manufacture and assembly


(a) Component side of the functional PCB. | (b) Rear/connector side with display interfaces, ESP-01 and USB.

Figure 9 — Assembled four-layer prototype, shown from both sides.

## 6.1 Production package

Output | Purpose
Gerber / layer outputs | Copper, mask, overlay, paste and mechanical data
NC drill | Plated, non-plated, round and slot holes
Pick-and-place + BOM | Centroids/orientations and fitted-part information
Draftsman | Fabrication, assembly and drill drawings
DRC / ERC / differences | Design verification records
STEP | Board-level 3D exchange model

## 6.2 Fabrication query and assembly lessons

The fabricator identified four overlapping non-plated holes and asked whether the final diameter should be 3.45 mm or 3.2 mm. The source geometry was corrected before production. The most important component-level faults were also diagnosed systematically: the reversed TPS61165 Schottky diode, FMC/SDRAM solder/configuration issues and the USBLC6-2SC6 D+ short.

# 7 Firmware and graphical interface

Non-blocking acquisition, compensated values, local alarms and external-memory graphics


Figure 10 — Cooperative time-based scheduler used by the integrated firmware.

## 7.1 Peripheral configuration

Peripheral | Role
LTDC | 480 × 272 RGB timing with SDRAM-backed L8 layers
I²C3 / I²C4 | BME688 and SCD41 on separate buses
ADC1 / GPIO | Flame analog PA1, D0 PH2 and buzzer control
USART1 | ESP-01 AT commands and internet services
USART3 | MCP2221A bidirectional PC service console
QUADSPI | W25Q128 background/font/icon assets
FMC | 8 MB SDRAM diagnostics and GUI framebuffers

## 7.2 Timing and fault isolation

HAL_GetTick() schedules the cooperative main loop. Flame sampling runs every 200 ms; environmental acquisition approximately every 5 s; GUI refresh every 500 ms; Blynk upload every 10 s; Wi-Fi retry every 30 s; and weather/time retrieval at a slower interval. Each service owns an independent status so a failed cloud request does not disable local sensing or alarms.

# 7.3 Final graphical dashboard

Figure 11 — Final QSPI-themed, SDRAM-double-buffered dashboard with live local and internet data.

The top bar shows the clock, Wi-Fi/cloud icons and date. The centre shows the configured location and outdoor temperature. Indoor values use a two-column layout: compensated SCD41 room temperature/humidity on the left, and SCD41 CO₂ plus BME688 pressure on the right. The air-quality state and explanation remain visible below. Raw flame, gas and BME temperature continue in diagnostics/background monitoring and do not clutter the normal screen.

Flicker was removed by drawing the next dynamic layer into the inactive 480 × 272 L8 buffer in SDRAM, cleaning the relevant Cortex-M7 cache range and swapping the LTDC layer address during vertical blanking. QSPI supplies the themed background, modern font and icons; only a complete, ready frame is presented.

MEMORY USAGE
Two L8 GUI buffers consume about 255 KiB of SDRAM. QSPI supplies persistent assets without enlarging internal flash, and internal SRAM remains available for the scheduler, network parser and drivers.

# 7.4 Cloud data and alarm policy

Blynk datastream | Content | Representation
V0–V2 | Flame state, ADC and voltage | Boolean / raw / V
V3 | SCD41 CO₂ | ppm
V4 / V5 | Compensated SCD41 room T / RH | °C / %RH
V6 / V7 | BME688 temperature / humidity diagnostics | °C / %RH
V8 | BME688 pressure | hPa
V9–V11 | Gas resistance, ratio and alarm | Ω / % / Boolean

Measurements are batched where possible; flame state changes can be sent immediately. A separate HTTP request obtains Brussels outdoor temperature and the HTTP Date header supplies local date/time. The parser anchors on the actual HTTP/1.x header within the ESP-01 transcript, skips the header terminator and parses the signed body value.

## Alarm philosophy

- Local indication and buzzer control never depend on Wi-Fi or Blynk availability.
- SCD41 compensated values drive room temperature/humidity decisions; BME temperature is diagnostic only.
- Gas detection arms only after a stable baseline and uses persistence plus clear hysteresis.
- The physical MOSFET gate pull-down guarantees buzzer-off during reset.
- Flame has priority; severe persistent environmental conditions can also produce a priority screen and buzzer pattern.

# 8 Verification and test results

Bench evidence for every major subsystem

## 8.1 Incremental method

Power rails and control pins were measured before firmware integration. Each digital peripheral was first tested with a narrow diagnostic program and only then added to the combined dashboard. The display was an immediate local test surface; the MCP2221A/USART3 console provided persistent diagnostic responses.

- Power — verify 5 V, regulated 3.3 V, acceptable current and repeatable MCU boot.
- Sensors — confirm I²C acknowledgement, manufacturer command sequence and plausible live values.
- Flame/buzzer — compare ADC voltage and D0/LED state, then verify controlled sounder behaviour.
- Connectivity — verify ESP AT responses, WLAN, Blynk, weather/time parsing and MCP terminal round trips.
- Memory — read QSPI ID and repeat complete 8 MB SDRAM address/data-pattern tests.
- HMI — verify backlight, QSPI assets, cache maintenance, VBlank buffer swapping and alarm priority.

## 8.2 Integrated demonstration snapshots

Snapshot | Outdoor | Room T / RH | CO₂ | Pressure | Air quality
Normal GUI photo | 22 °C | 34.3 °C / 31.9 % | 675 ppm | 1005.5 hPa | GOOD
Second stable state | 24 °C | 26.3 °C / 52.7 % | 600 ppm | 1009.2 hPa | GOOD

INTERPRETATION
These snapshots prove the complete acquisition/display path. They are not calibration certificates. The installation-specific SCD41 compensation should be verified against a reference after enclosure thermal equilibrium.

# 8.3 Verification matrix

Subsystem | Status | Evidence
5 V input / AP63203 3.3 V | PASS | Rails present; MCU/peripherals operate
STM32F746 boot / SWD | PASS | Firmware programs and runs
RGB LCD + TPS61165 | PASS | Image and backlight stable after diode correction
SCD41 on I²C4 | PASS | Compensated CO₂/T/RH integrated
BME688 on I²C3 | PASS | Pressure/gas and diagnostics acquired
Flame A0 / D0 | PASS | ADC and active-low D0 respond
Buzzer driver | PASS | Controlled by STM32; silent at reset
ESP-01 / Blynk / weather | PASS | AT, AP, TCP, Blynk and outdoor data
W25Q128 QSPI | PASS | EF 40 18; verified data and assets
IS42S16400 SDRAM | PASS | All 8 MB repeatedly verified at ~66 MHz
MCP2221A USB-UART | PASS | USBLC6 fault repaired; enumeration and two-way commands
GT911 touch | NOT TESTABLE | External touch FPC completely torn

# 8.5 Priority alarm evidence


Figure 12 — Persistent high-temperature condition produces a priority warning screen and simultaneously activates the controlled buzzer.

The screen explicitly identifies the active condition, measured value and recommended response. The dashboard is restored after the alarm clears. This behaviour verifies the complete sensor decision → GUI priority → GPIO/MOSFET → buzzer chain rather than only an isolated buzzer test.

SAFETY STATEMENT
Alarm functions are valuable course demonstrations but remain non-certified. The hub must not replace approved smoke, flame, gas or carbon-monoxide alarms.

# 9 Problems, corrections and lessons

Failures were retained as structured engineering evidence

Symptom | Cause / status | Action | Rev-B prevention
Backlight remained off | External Schottky reversed | Corrected polarity | Larger cathode marking + checklist
Display flashed | Whole frame exposed while drawing | SDRAM double buffer + VBlank swap | Retain cache/VBlank discipline
ESP weather/SSL failed | Old TLS path; parser start wrong | HTTP and bounded HTTP-body parser | Current TLS-capable radio/firmware
MCP2221A did not enumerate | USBLC6-2SC6 D+ path shorted to GND | Continuity diagnosis + rework; full UART PASS | Verify ESD footprint; isolation/loopback pads
SDRAM mismatch | FMC conflicts plus solder/contact | Rework + clean FMC config; 8 MB PASS | Preserve production self-test
Touch unavailable | External flex mechanically torn | Removed from demonstration | Replaceable FFC + strain relief
Fabricator hole query | Four overlapping NPTH features | Corrected before production | Explicit hole-to-hole review


Figure 13 — Repeated full 8 MB SDRAM diagnostic after FMC correction and rework.

ENGINEERING LESSON
The SDRAM fault was not solved by adding bus pull-ups, and the MCP fault was not software. Repeatable electrical measurements, narrow subsystem tests and controlled rework converted both faults into repeatable PASS results.

# 10 Improvement plan for Rev B

Priority | Change | Implementation | Benefit
P1 | Touch serviceability | Replaceable FFC/assembly, strain relief and no copper at bend | Restores and protects input
P1 | Secure radio | Current TLS, certificate validation and supply margin | Removes plain-HTTP dependency
P2 | USB robustness | Keep ESD, add labelled D+/D−/TX/RX loopback and 0 Ω isolation | Faster deterministic diagnosis
P2 | Sensor thermal layout | Vented edge/peninsula away from display, MCU and inductors | Improves accuracy/response
P2 | Memory robustness | Preserve 8 MB self-test and optional series footprints | Protects framebuffer path
P2 | Manufacturing clarity | Stronger polarity/pin-1/NPTH checks and assembly drawings | Reduces rework/CAM queries
P3 | Firmware resilience | Watchdog, fault log, alarm latching, OTA and self-test | Improves maintainability

## 10.1 Validation additions

A second revision should include a written test specification covering supply current/ripple, sensor warm-up, reference-instrument comparison, gas-baseline repeatability, alarm thresholds, Wi-Fi reconnect behaviour, extended run time, temperature exposure and ESD/EMI pre-compliance. The present board proves the architecture but does not provide statistical product-validation evidence.

HIGHEST-VALUE NEXT ACTION
Replace the damaged touch assembly and improve touch-flex strain relief, then repeat sensor compensation inside the intended enclosure. Preserve the passing SDRAM and MCP service tests as production self-tests.

# 11 Conclusion

The Smart Home Hub achieved the central objective of the Advanced PCB course: a custom manufactured four-layer PCB that boots, senses the room, presents information locally, warns through an independently controlled buzzer and communicates over both Wi-Fi and USB service links. The design integrates a high-pin-count STM32, parallel RGB display, multiple I²C buses, analog comparator/ADC path, switch-mode conversion, external serial flash, parallel SDRAM and a complete production-data workflow.

Every populated/core PCB subsystem now passes end-to-end testing: stable power, STM32/SWD, display/backlight, SCD41, BME688, flame detector, buzzer, ESP-01/Blynk, internet weather/time, W25Q128 QSPI, full 8 MB SDRAM and the repaired MCP2221A/USART3 service console. The final firmware assigns memory correctly: QSPI holds persistent backgrounds, fonts and icons; SDRAM provides double-buffered GUI layers and working space; internal SRAM retains control state.

The only unavailable feature is GT911 touch input because the display assembly's external flex tail is mechanically torn. The operating hub does not depend on that input. Plain HTTP, installation-specific temperature compensation and non-certified flame/gas algorithms remain explicit development limitations rather than hidden product claims.

FINAL ASSESSMENT
The prototype is demonstrable and functionally useful for the course. Core paths, external memories, cloud data, alarm behaviour and the USB service console are verified; the remaining touch limitation and Rev-B risks are clearly documented.

# Appendix A Delivered project data

ID | Deliverable | Content | State
A1 | Archived Altium project | PrjPcb, SchDoc, PcbDoc, OutJob and STEP | READY
A2 | Production package | Factory Gerber/layer files and NC drill | READY
A3 | Smart schematic PDF | Compiled hierarchical schematic set | READY
A4 | Draftsman | Assembly, fabrication and drill drawings | READY
A5 | Bill of materials | Standalone XLSX export | READY
A6 | Verification | DRC, ERC and differences reports | READY
A7 | Firmware | STM32CubeIDE project/source and build notes | READY
A8 | Technical report | This Rev 2.1 DOCX and PDF | READY
A9 | Presentation | Project PPT for oral demonstration | READY
A10 | A4 poster | Concise project overview | READY

## Submission folder

Folder | Contents
01_Altium_Source | Archived source project and libraries
02_Production_Data | Exact factory-accepted package
03_Schematic_PDF | Smart PDF
04_Draftsman | Assembly/fabrication/drill PDF
05_BOM | XLSX and optional PDF
06_Verification | DRC, ERC and differences
07_ Electrical Rules Check Report
08_ PCB Differences | Differences
09_Firmware | STM32CubeIDE project/source and notes
10_Report | DOCX and PDF
11_Presentation_Poster | PPTX and A4 poster

# Appendix B References

[1] STMicroelectronics, STM32F746BG product page and device documentation. https://www.st.com/en/microcontrollers-microprocessors/stm32f746bg.html

[2] Sensirion, SCD41 product page, SCD4x data sheet and temperature-offset guidance. https://sensirion.com/products/catalog/SCD41

[3] Bosch Sensortec, BME688 gas sensor product documentation. https://www.bosch-sensortec.com/en/products/environmental-sensors/gas-sensors/bme688/

[4] Texas Instruments, TPS61165 high-brightness LED driver data sheet. https://www.ti.com/product/TPS61165

[5] Diodes Incorporated, AP63203 synchronous buck converter. https://www.diodes.com/part/view/AP63203

[6] Microchip Technology, MCP2221A USB-to-I²C/UART bridge. https://www.microchip.com/en-us/product/mcp2221a

[7] Integrated Silicon Solution Inc., IS42S16400J SDR SDRAM family. https://www.issi.com/US/product-dram-SDR.shtml

[8] Winbond Electronics, W25Q128JV QSPI NOR flash family. https://www.winbond.com/hq/product/code-storage-flash/qspi-nor/

[9] Blynk documentation. https://docs.blynk.io/

[10] Altium Designer documentation. https://www.altium.com/documentation/altium-designer

[11] Project evidence: archived Altium design, factory outputs, schematics, STM32CubeIDE firmware, final dashboard photographs and bench observations.

## Component naming note

Part numbers in this report follow the design and assembled prototype evidence available during preparation. The fabrication BOM, schematic libraries and fitted-component inspection remain authoritative for package, tolerance and ordering-suffix details.

Mahmoud Mostafa | Rev 2.1 · 16 August 2026 | Page 1

SMART HOME HUB | ADVANCED PCB TECHNICAL REPORT

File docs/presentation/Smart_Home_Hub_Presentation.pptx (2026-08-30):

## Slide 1

THOMAS MORE · ELECTRONICS-ICT

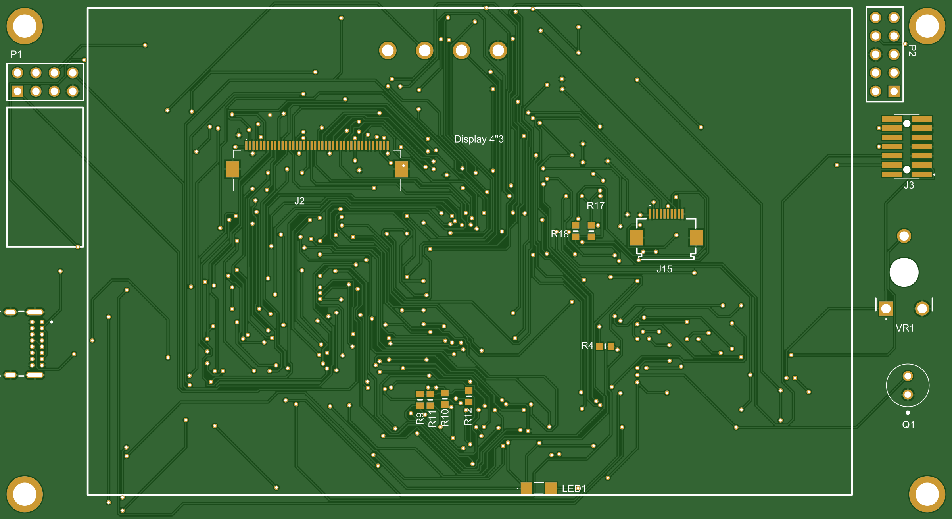
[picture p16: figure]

SMART HOME
HUB

A manufactured four-layer STM32 platform that senses the room, communicates and alarms locally.

Mahmoud Mostafa
Advanced PCB: Lab · 2025–2026

STM32F746 · RGB TFT · SCD41 · BME688 · ESP-01 · QSPI

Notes: Opening: the goal was not a development board demo, but a complete custom PCB that combines environmental sensing, a local GUI, alarms, Wi-Fi and service interfaces.

[Sources]
- Project PCB Gerber render: user-authored production data.

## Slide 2

DESIGN CHALLENGE

One board had to sense, warn and communicate

High-speed video and memory share the board with quiet analog sensing and two power rails.

- 480 × 272 RGB display driven directly by LTDC
- CO₂, temperature, humidity, pressure and relative gas response
- Independent local flame warning and default-off buzzer
- Wi-Fi telemetry through an ESP-01
- Manufacturable four-layer PCB with reproducible outputs

4

PCB layers

2

I²C buses

480×272

RGB pixels

5 V

system input

Success criterion

3.3 V

logic rail

16 MB

QSPI flash

A demonstrable working unit with traceable production data—and limitations that are measured, contained and documented.

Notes: Explain that the challenge was the combination of interfaces, not any one sensor. The central engineering problem was maintaining power integrity and return paths while routing LTDC/FMC-density signals.

[Sources]
- Project requirements and measurements: user-authored technical report.

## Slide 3

SYSTEM ARCHITECTURE

Domain separation simplified bring-up

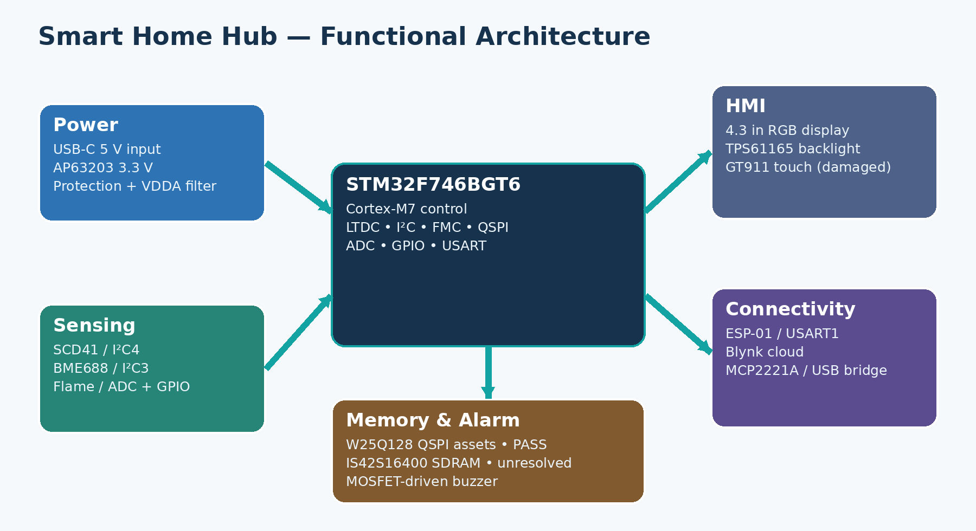
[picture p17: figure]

Interface map

LTDC

RGB display

I²C4

SCD41

I²C3

BME688

ADC1 / PH2

USART1

Flame A0 / D0

ESP-01

QUADSPI

W25Q128

FMC

SDRAM

Why it matters

A failed bus or memory device does not prevent the rest of the dashboard and alarms from operating.

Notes: Walk clockwise through the architecture. Emphasize separate I²C buses and the decision to keep the working GUI independent of SDRAM.

[Sources]
- Project architecture graphic: user-authored report asset.
- STMicroelectronics STM32F746BG: https://www.st.com/en/microcontrollers-microprocessors/stm32f746bg.html

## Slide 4

POWER AND DISPLAY

Power integrity anchors the HMI

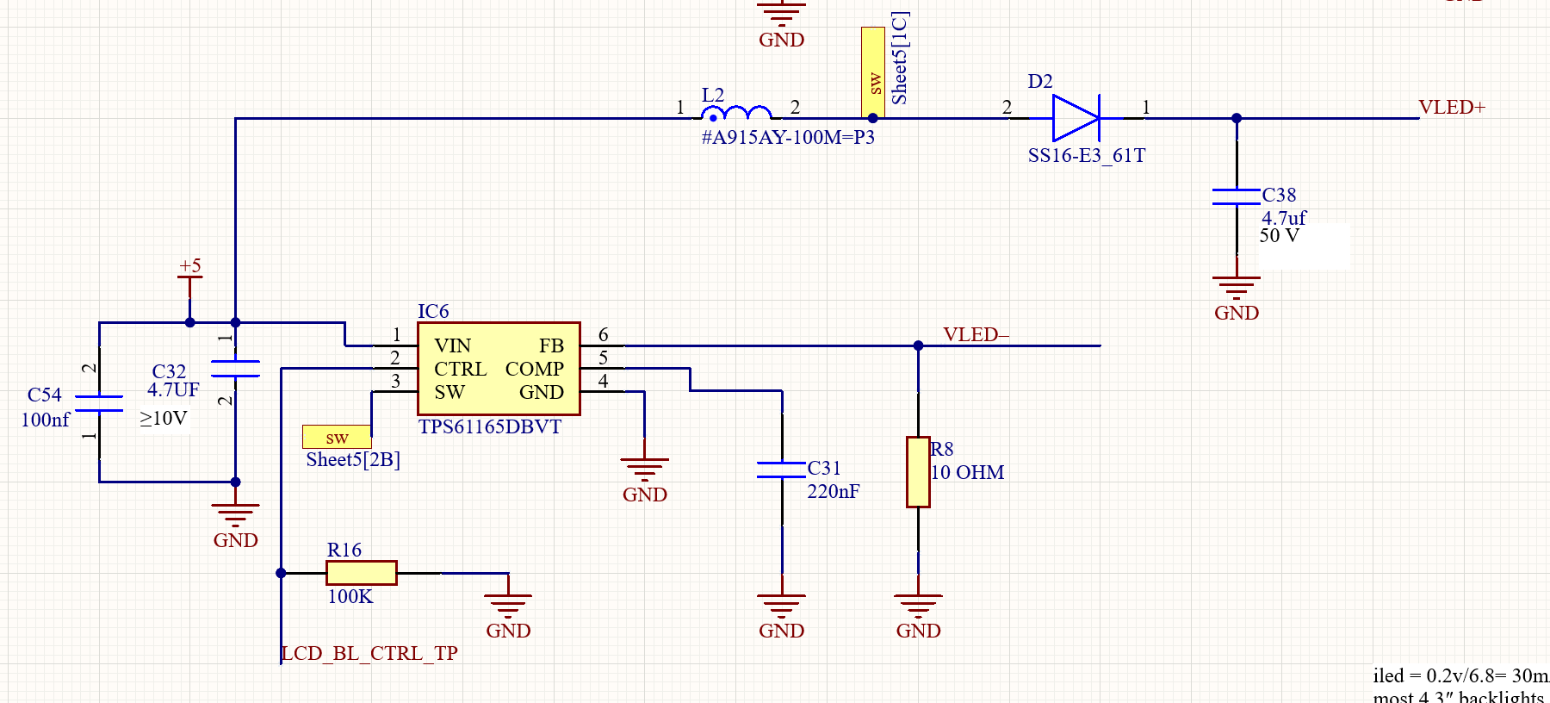
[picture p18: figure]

5 V → 3.3 V power tree

- USB-C sink: 5.1 kΩ on CC1/CC2
- Fuse + TVS protection
- AP63203 synchronous buck
- Ferrite-isolated VDDA/VREF+

TPS61165 backlight

- Constant-current LED-string drive
- CTRL held low until MCU control
- High-voltage output capacitor
- Schottky polarity corrected during bring-up

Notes: Explain the two power domains and the VDDA filter. For the backlight, the first failure was not the capacitor or inductor: the external Schottky diode was reversed. Measurements at VIN, CTRL, FB and VLED led to the correction.

[Sources]
- User-authored schematic captures.
- Texas Instruments TPS61165: https://www.ti.com/product/TPS61165
- Diodes AP63203: https://www.diodes.com/part/view/AP63203

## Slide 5

SENSING AND ALARMS

Visible comfort data, hidden safety channels

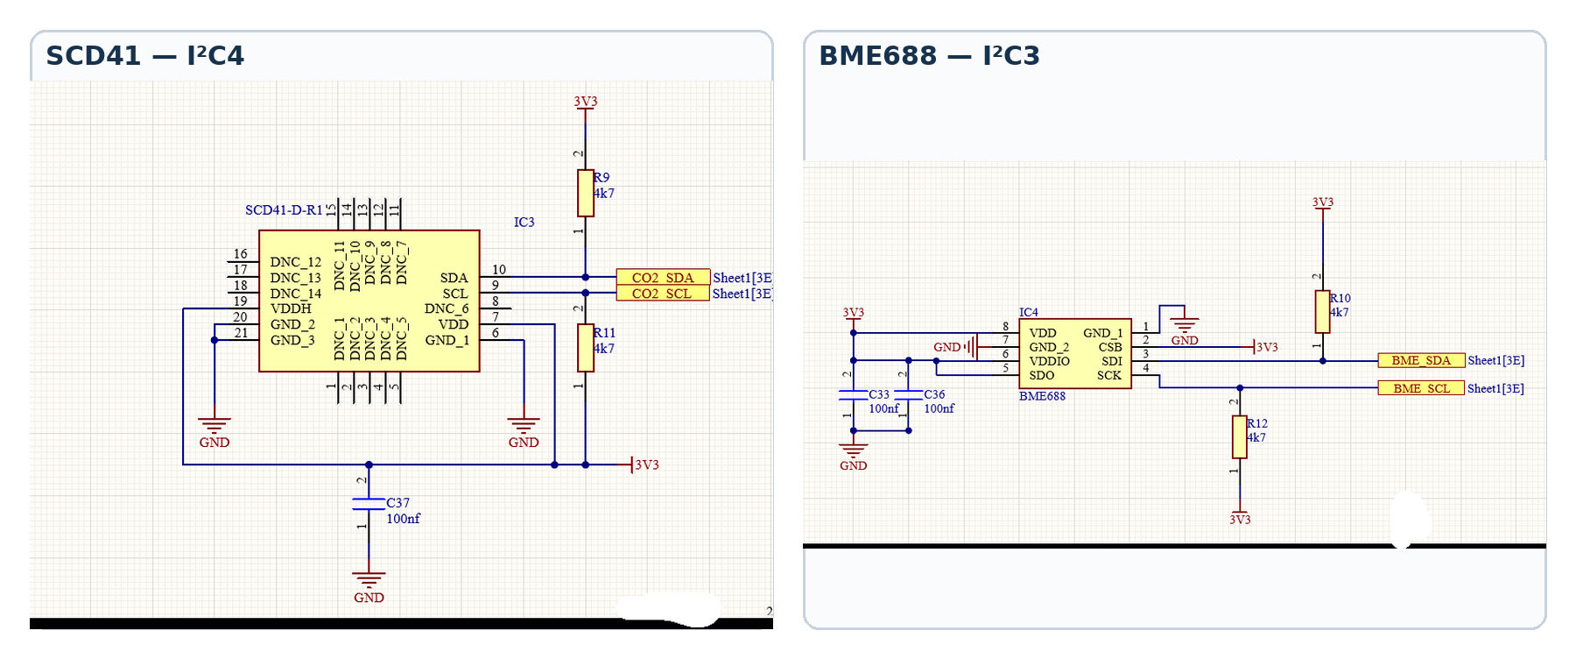
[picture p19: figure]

Visible environmental data

- SCD41: CO₂ + T/RH on I²C4
- BME688: T/RH + pressure + gas resistance on I²C3
- Local pull-ups and decoupling on both buses

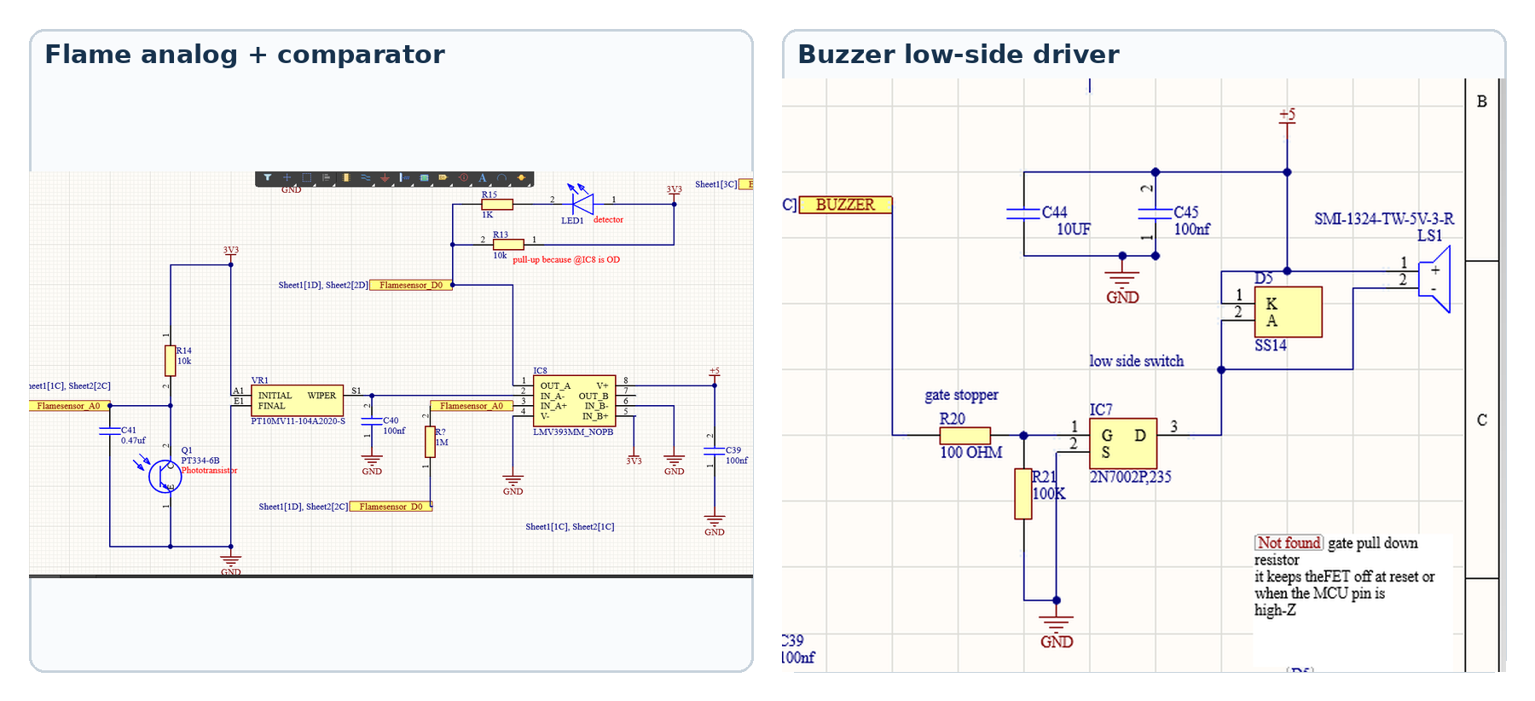
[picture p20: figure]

Background safety logic

- PA1 continuously samples flame A0
- PH2 reads active-low comparator D0
- Gas change is judged against a learned clean-air baseline
- 100 kΩ gate pull-down keeps buzzer silent at reset

LOCAL ALARM DOES NOT REQUIRE WI-FI

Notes: The normal dashboard intentionally does not show flame or gas values. They remain active in the background and take over the screen only during a fault. Gas resistance is a relative air-change indicator—not gas identification.

[Sources]
- User-authored schematic captures and firmware tests.
- Sensirion SCD41: https://sensirion.com/products/catalog/SCD41
- Bosch BME688: https://www.bosch-sensortec.com/products/environmental-sensors/gas-sensors/bme688/

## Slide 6

PCB IMPLEMENTATION

A four-layer stack protects return paths

The autorouter established a baseline; power, constrained regions and return paths were reviewed manually.

TOP

signals + components

L1

solid GND plane

L2

3.3 V plane

BOTTOM

signals + components

Routing priorities

- Dense MCU–memory escape
- Compact boost SW loop
- Wide 5 V / 3.3 V paths
- Manufacturer-aligned DRC

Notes: Describe the L1 GND and L2 3V3 plane assignment. The PCB view is derived from the production Gerbers; final constrained and power routes were manually reviewed after autorouting.

[Sources]
- PCB Gerber render: user-authored production data.
- Altium Designer documentation: https://www.altium.com/documentation/altium-designer

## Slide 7

FIRMWARE AND GUI

Partial updates eliminate screen flashing

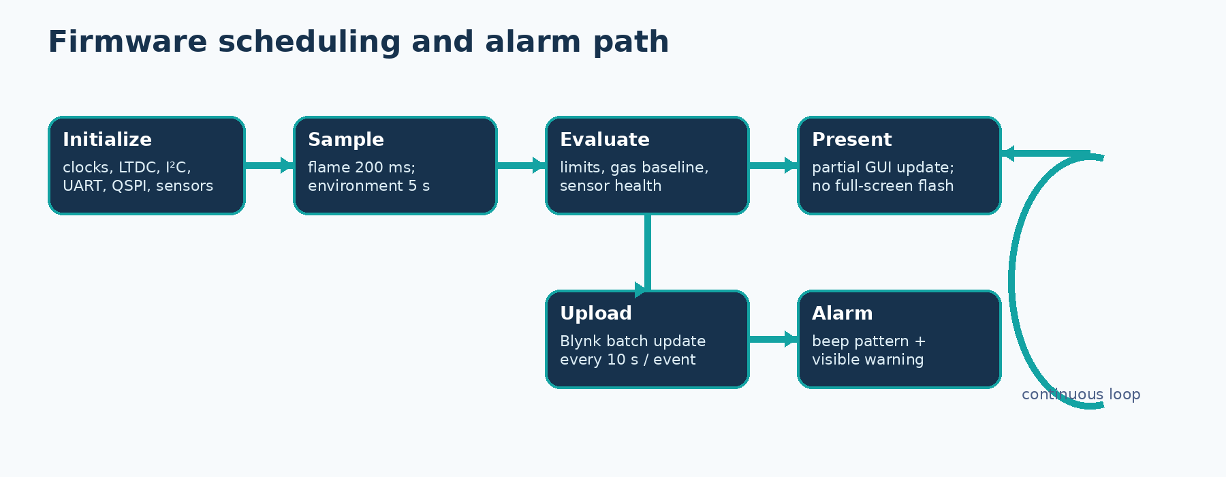
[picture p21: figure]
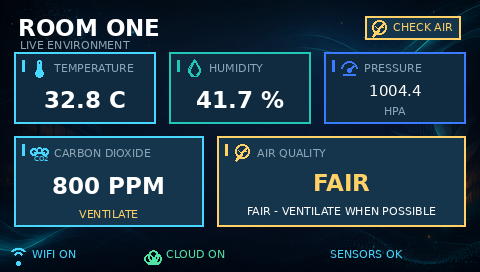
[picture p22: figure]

Smooth rendering

- Static QSPI background remains in place
- Only changed value rectangles are redrawn
- D-cache cleaned before LTDC presentation when required

200 ms

flame sample

5 s

environment

500 ms

display

10 s

Blynk batch

GUI RUNS WITHOUT SDRAM

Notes: The integrated loop is time-based rather than built around long delays. The final GUI fixes visible flashing by keeping static assets in QSPI and redrawing only dynamic fields.

[Sources]
- Firmware flow and GUI image: user-authored project assets.

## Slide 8

CONNECTIVITY AND STORAGE

QSPI stores visuals; ESP-01 exports data

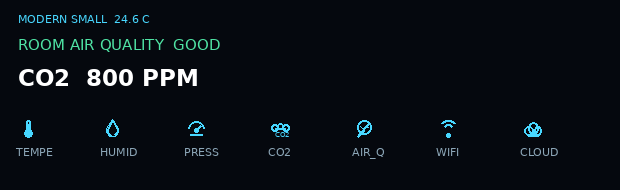
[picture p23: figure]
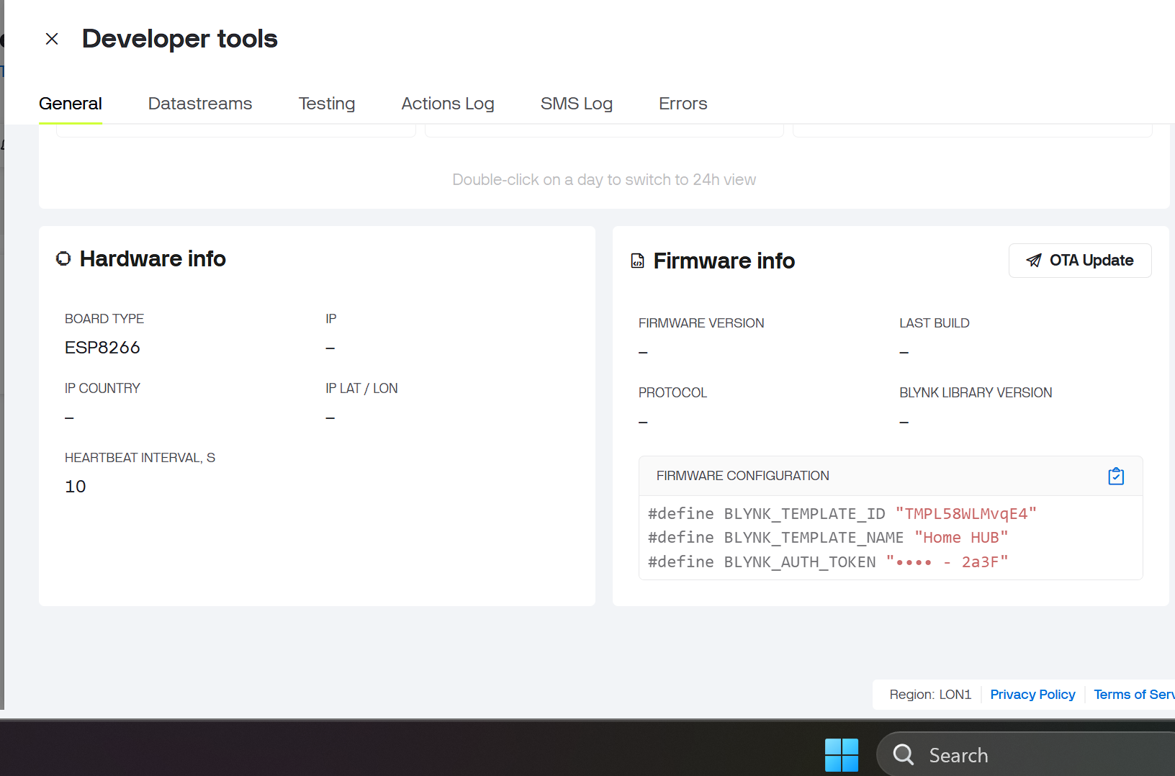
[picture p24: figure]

W25Q128 QSPI

- JEDEC ID EF 40 18 verified
- 16 MB non-volatile storage
- Background and modern font/icon assets

ESP-01 + Blynk

- USART1 AT command link
- Wi-Fi association and TCP confirmed
- Virtual-pin update passed
- Lab proof uses HTTP; Rev B should use current TLS

QSPI PASS

BLYNK PASS

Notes: QSPI is used for the background image and font/icon assets, so internal flash is not consumed by all GUI resources. The installed ESP-01 firmware could not establish a usable SSL path; HTTP was kept only for lab proof.

[Sources]
- User-authored QSPI GUI assets and Blynk screenshot.
- Winbond W25Q128JV family: https://www.winbond.com/hq/product/code-storage-flash/qspi-nor/

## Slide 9

MEASURED EVIDENCE

Live readings confirm both I²C buses

800

ppm CO₂

30.4

°C · SCD41

54.5

%RH · SCD41

Flame response

3.19 V → 1.50 V

ADC ≈3950 → ≈1730 when a lighter is presented

32.8

°C · BME688

41.7

%RH · BME688

1004.4

hPa pressure

Interpretation

These readings prove the electrical and firmware data paths. They are not calibration certificates.

SENSORS PASS

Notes: State the readings exactly as observed. Differences between the SCD41 and BME688 temperature/humidity channels are expected from timestamps, thermal coupling, airflow and self-heating; no calibrated accuracy claim is made.

[Sources]
- Bench observations recorded by the user in the project report.

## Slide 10

VERIFICATION MATRIX

Core functions pass; three features remain limited

SUBSYSTEM | STATUS | EVIDENCE
Power + STM32 + RGB LCD | PASS | Stable rails, boot and visible GUI
SCD41 + BME688 | PASS | Live CO₂ / T / RH / pressure
Flame + buzzer | PASS | ADC + D0 response; silent at reset
ESP-01 + Blynk | PASS | Wi-Fi, TCP and V-pin update
W25Q128 QSPI | PASS | EF 40 18 + data test
IS42S16400 SDRAM | FAIL | A5A55A5A → FF00FF00
GT911 touch | NOT TESTABLE | Flex tail torn
MCP2221A USB-UART | PARTIAL | Enumerates; UART unconfirmed

The demonstrable environmental-monitoring system remains usable because the GUI does not depend on SDRAM and the touch input is not required for sensing or alarm output.

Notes: This is the most important honesty slide. Do not imply that every fitted feature works. Separate the working core from SDRAM FAIL, touch NOT TESTABLE and MCP2221A PARTIAL.

[Sources]
- User-authored bench test results and technical report.

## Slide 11

CORRECTIONS AND LESSONS

Bring-up failures became Rev-B design rules

01

Backlight off

Reversed diode → clearer polarity marking

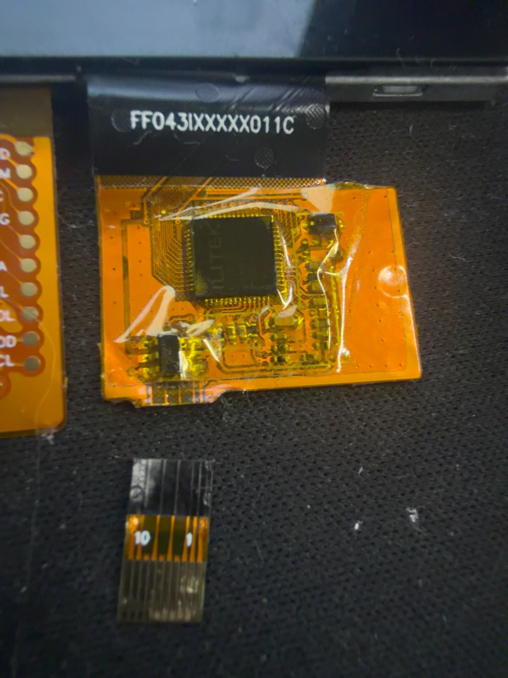
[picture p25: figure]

02

Whole display flashed

Full-frame redraw → update dynamic fields only

03

SSL connection failed

Legacy AT firmware → use current TLS-capable module

04

SDRAM mismatch

Unresolved → verify FMC pins, joints and timing

Mechanical lesson

The touch failure is a torn flex—not a GT911 software problem. Replacement is the robust remedy.

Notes: Use each failure as evidence of diagnostic method: measure first, isolate the subsystem, and prevent the same failure in the next revision. The touch flex is physically severed; it cannot be fixed in software.

[Sources]
- User-authored bring-up record and touch-flex photograph.

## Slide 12

CONCLUSION

The architecture works—and Rev B is clear

Demonstrated now

- Custom four-layer PCB boots reliably
- Environmental dashboard updates smoothly
- Local flame/gas logic drives a controlled buzzer
- Wi-Fi telemetry and QSPI assets work

Rev-B priorities

- Diagnose/redesign the FMC SDRAM path
- Replace the touch assembly and add strain relief
- Use modern secure Wi-Fi hardware
- Add deterministic USB-UART loopback and isolation points

A demonstrable and functionally useful course prototype—with verified core paths and limitations that are explicit, contained and actionable.

LIVE DEMO: power → dashboard → sensor updates → flame warning → Blynk → QSPI test

Final takeaway

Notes: Close by resolving the opening challenge. The board senses, explains, warns and communicates. Then run the live demonstration in the footer order.

[Sources]
- Synthesis of user-authored project evidence and technical report.

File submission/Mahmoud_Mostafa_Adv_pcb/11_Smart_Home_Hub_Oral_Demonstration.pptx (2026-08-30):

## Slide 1

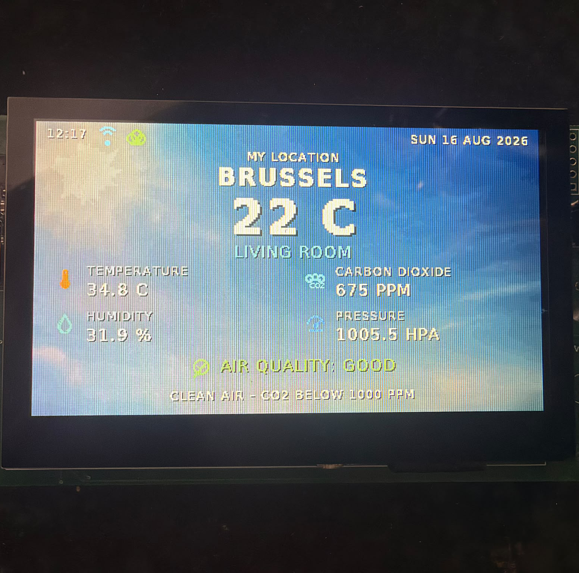
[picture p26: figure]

MANUFACTURED · ASSEMBLED · VERIFIED

ADVANCED PCB PROJECT

Smart Home
Hub

A four-layer STM32 environmental, connected-weather and alert platform

Mahmoud Mostafa

Professional Bachelor Electronics-ICT

B-TM-YT6250 · Jurre De Weerdt · 2025–2026

SMART HOME HUB · ADVANCED PCB

01 / 12

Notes: This project covers the complete Advanced PCB workflow: schematic capture, a custom four-layer PCB, fabrication, assembly, embedded firmware and final verification. The finished hub measures the room, presents data locally, reports selected values remotely and raises independent local alarms.

[Sources]
- Smart_Home_Hub_Technical_Report(1).pdf, cover and pp. 2–5.
- User-supplied final-system photograph: WhatsApp Image 2026-08-16 at 1.04.45 PM.jpeg.

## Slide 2

PROJECT OUTCOME

One PCB delivers four complete outcomes

02

The prototype is evaluated as an integrated system—not as isolated circuits.

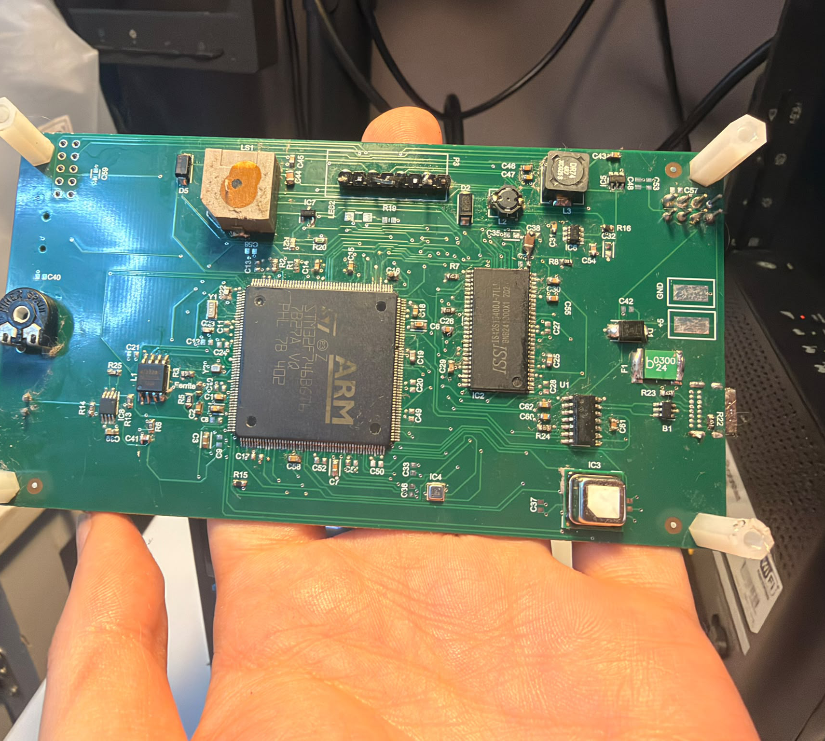
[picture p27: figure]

LIVE

LOCAL ENVIRONMENTAL DASHBOARD

LOCAL

INDEPENDENT ALARM PATH

CLOUD

WI-FI, BLYNK AND WEATHER

2×

EXTERNAL-MEMORY TECHNOLOGIES

Core result

Senses · displays · warns · stores · communicates

SMART HOME HUB · ADVANCED PCB

02 / 12
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

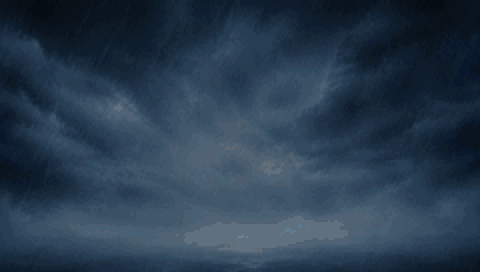
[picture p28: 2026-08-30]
firmware/Assets/weather_generated/rain_480x272.png

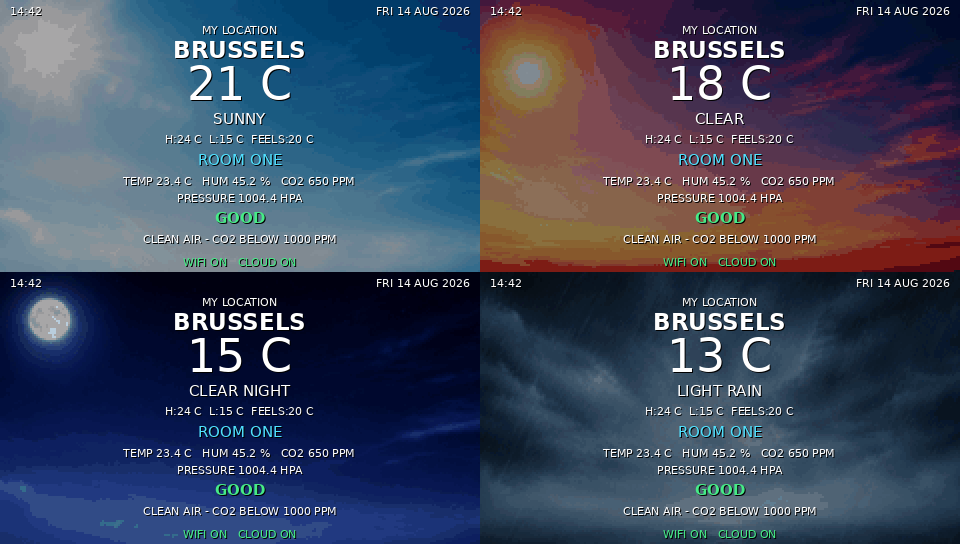
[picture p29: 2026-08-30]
firmware/Assets/previews/weather_gui_preview_sheet.png

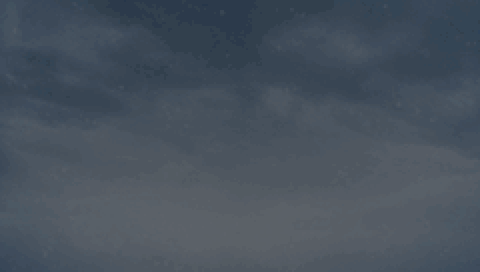
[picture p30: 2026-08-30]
firmware/Assets/weather_generated/snow_480x272.png

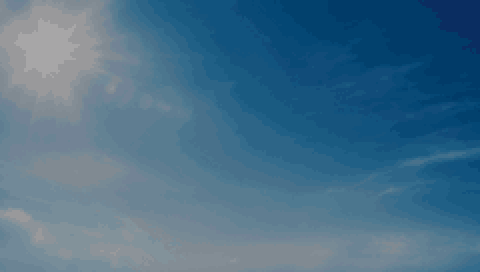
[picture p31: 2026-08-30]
firmware/Assets/weather_generated/clear_day_480x272.png

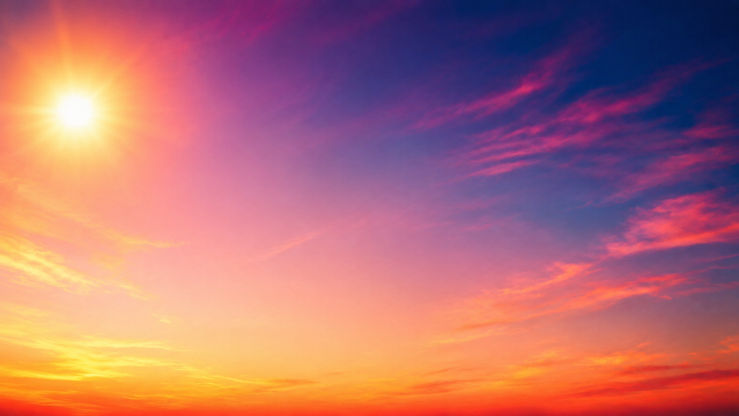
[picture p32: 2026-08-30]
firmware/Assets/weather_sources/sunset_source.png

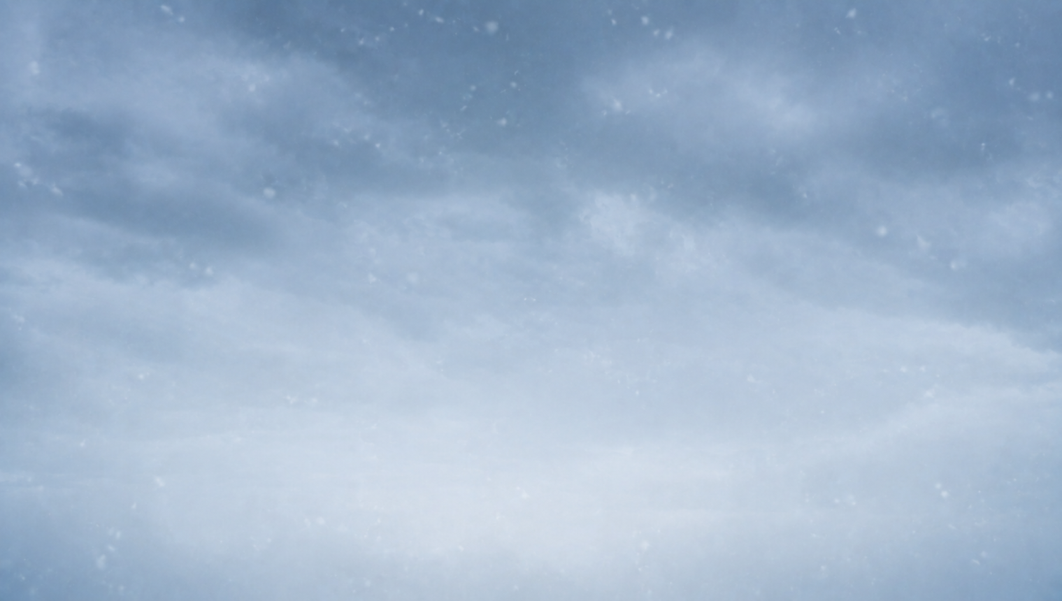
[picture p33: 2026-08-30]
firmware/Assets/weather_sources/snow_source.png

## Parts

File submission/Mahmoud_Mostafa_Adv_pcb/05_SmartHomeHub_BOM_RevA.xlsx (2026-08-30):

Name | Description | Designator | Footprint | LibRef | Quantity
1 |  | +5, GND | ANT | 1 | 2
USBLC6-2SC6 | TVS Diode Array Uni-Directional USBLC6-2SC6 17V, SOT-23 6-Pin | B1 | SOT95P280X145-6N | USBLC6-2SC6 | 1
1uf | WALSIN - 0603X105K250CT - SMD Multilayer Ceramic Capacitor, 1 F, 25 V, 0603 [1608 Metric], +/- 10%, X5R | C1 | CAPC1608X95N | 0603X105K250CT | 1
100nf | Capacitor | C2, C8, C9, C10, C11, C12, C13, C14, C15, C16, C17, C18, C19, C20, C21, C24, C25, C26, C27, C28, C29, C30, C33, C34, C36, C37, C39, C40, C42, C43, C45, C48, C49, C50, C51, C52, C54, C56, C57, C58, C60, C62 | CAPC1608X95N | VJ0603Y104KXACW1BC | 42
4.7uf | Cap Ceramic 2.2uF 10V X7R ±10% Pad SMD 0603 +125°C T/R | C3, C32, C35 | FP-CL10-IPC_A | CMP-13271-003582-1 | 3
10Uf | Capacitor | C4 | CAPC1608X95N | VJ0603Y104KXACW1BC | 1
1UF | Cap Ceramic 2.2uF 10V X7R ±10% Pad SMD 0603 +125°C T/R | C5 | FP-CL10-IPC_A | CMP-13271-003582-1 | 1
2.2uf | Cap Ceramic 2.2uF 10V X7R ±10% Pad SMD 0603 +125°C T/R | C6, C7 | FP-CL10-IPC_A | CMP-13271-003582-1 | 2
18pf | Multilayer Ceramic Capacitors MLCC - SMD/SMT 50volts 18pF 5% C0G | C22, C23 | CAPC1608X87N | C0603C180J5GAC | 2
220nF | WALSIN - 0603B223K500CT - CAPACITOR, MLCC, X7R, 0.022UF, 50V, 0603 | C31 | CAPC1608X87N | 0603B223K500CT | 1
4.7uf | WALSIN - 0603X105K250CT - SMD Multilayer Ceramic Capacitor, 1 F, 25 V, 0603 [1608 Metric], +/- 10%, X5R, Capacitor | C38, C55 | CAPC1608X95N | 0603X105K250CT, VJ0603Y104KXACW1BC | 2
0.47uf | Phycomp 0603 Standard 470nF Ceramic Multilayer Capacitor, 10 V dc, +125C, X7R Dielectric, +/-10% SMD | C41 | CAPC1608X90N | CC0603KRX7R6BB474 | 1
10uf | 10F +/-10% 10V Ceramic Capacitor X5R 0603 (1608 Metric) | C44, C53 | CAPC1608X90N | CL10A106KP8NNNC | 2
22uf | Capacitor | C46, C47 | CAPC1608X95N | VJ0603Y104KXACW1BC | 2
100nf | CAP CER 0.1UF 50V X7R 0603 | C59 | FP-VJ0603X-MFG | CMP-02417-000051-1 | 1
330nf | Capacitor | C61 | CAPC1608X95N | VJ0603Y104KXACW1BC | 1
SMBJ5.0A | TVS Diode (Uni-directional) | D1 | SMBJ12A | SMBJ5.0A | 1
SS16-E3_61T | Diode | D2 | DIOM5127X229N | SS16-E3_61T | 1
SS14 | Battery | D5 | DIOM5026X262N | SS14 | 1
0ZCF0300BF2C | Fuse | F1 | FUSC7451X115N | 0ZCF0300BF2C | 1
FCM1608KF-601T03 | Ferrite Bead | Ferrite | BEADC1608X95N | FCM1608KF-601T03 | 1
STM32F746BGT6 | Integrated Circuit | IC1 | QFP50P3000X3000X160-208N | STM32F746BGT6 | 1
IS42S16400J-7TLI | Integrated Circuit | IC2 | SOP80P1176X120-54N | IS42S16400J-7TLI | 1
SCD41-D-R1 | Integrated Circuit | IC3 | SCD41DR1 | SCD41-D-R1 | 1
BME688 | Integrated Circuit | IC4 | BME688 | BME688 | 1
AP63203WU-7 | Integrated Circuit | IC5 | AP63203WU7 | AP63203WU-7 | 1
TPS61165DBVT | Integrated Circuit | IC6 | SOT95P280X145-6N | TPS61165DBVT | 1
2N7002P,235 | Integrated Circuit | IC7 | SOT95P230X110-3N | 2N7002P,235 | 1
LMV393MM_NOPB | Integrated Circuit | IC8 | SOP65P490X110-8N | LMV393MM_NOPB | 1
FH12-40S-0.5SH_55_ | Connector | J2 | FH1240S05SH55 | FH12-40S-0.5SH_55_ | 1
FTSH-107-01-L-DV-K-A | Connector | J3 | FTSH-107-XX-YYY-DV-K-A | FTSH-107-01-L-DV-K-A | 1
USB4085-GF-A_REVA4 | USB-C (USB TYPE-C) USB 2.0 Receptacle Connector 24 (16+8 Dummy) Position Through Hole, Right Angle, low cost, 3.46mm profile, 16 pin, horizontal, Top mount | J4 | GCT_USB4085-GF-A_REVA4 | USB4085-GF-A_REVA4 | 1
FH12-10S-0.5SH_55_ | Connector | J15 | FH1210S05SH55 | FH12-10S-0.5SH_55_ | 1
W25Q128JVSIQ_TR | Inductor | L1 | SOIC127P780X195-8N | W25Q128JVSIQ_TR | 1
#A915AY-100M=P3 | FIXED IND 10UH 1.49A 90 MOHM SMD | L2 | FP-D53LC-MFG | CMP-06042-000140-1 | 1
DR74-4R7-R | High Power Density, High Efficiency, Shielded Inductor, 4.7 uH, -40 to 125 degC, RoHS, Tape and Reel | L3 | COBU-DR74-4R7-R_V | CMP-2000-06180-1 | 1
KPTL-3216SURCK-01-VS | LED | LED1, LED2 | KPTL3216SURCK01VS | KPTL-3216SURCK-01-VS | 2
SMI-1324-TW-5V-3-R | Loudspeaker or Buzzer | LS1 | SMI1324TW5V3R | SMI-1324-TW-5V-3-R | 1
ESP-01 | Modified .025" SQ Post Header, Through-hole, Vertical, -55 to 105 degC, 2.54 mm Pitch, 8-Pin, Male, RoHS | P1 | SMTC-MTSW-104-12-X-D-006 | CMP-1024-00110-1 | 1
TSW-105-05-G-D | 0.025" SQ Post Header, Through-hole, Vertical, -55 to 125 degC, 2.54 mm Pitch, 10-Pin, Male, RoHS | P2 | SMTC-TSW-105-05-X-D | CMP-1024-00362-1 | 1
691701510004B | Terminal Block, 5.08MM, Close Vertical Pcb Header, Thr Type, 4 Pins | P3 | 691701510004B | CMP-1502-02331-3 | 1
PT334-6B | Phototransistor | Q1 | PT3346B | PT334-6B | 1
10k | Resistor | R1, R2, R3, R4, R6, R13, R14, R24, R26 | RESC1608X55N | RC0603FR-071KL | 9
47 | Resistor | R5 | RESC1608X55N | RC0603FR-071KL | 1
4k7 | Resistor | R7, R9, R10, R11, R12, R17, R18, R19 | RESC1608X55N | CRCW06034K70JNEAC | 8
10 OHM | AR03BTCX6R80 | R8 | RESC1608X50N | RCA0603100KFKEA | 1
1k | CRCW0603 Resistor T/R 0.10W,1%,1K Vishay CRCW Series Thick Film Surface Mount Resistor 0603 Case 1k +/-1% 0.1W +/-100ppm/C | R15 | RESC1608X50N | CRCW06031K00FKEA | 1
100k | 100 kOhms +/-1% 0.1W, 1/10W Chip Resistor 0603 (1608 Metric) Anti-Sulfur, Automotive AEC-Q200 Thick Film | R16 | RESC1608X50N | RCA0603100KFKEA | 1
100 OHM | Res Thin Film 0603 100 Ohm 1% 0.1W(1/10W) +/-50ppm/C Sulfur Resistant Pad SMD Automotive Medical T/R | R20 | RESC1608X55N | TNPW0603100RFHEA | 1
10K | 100 kOhms +/-1% 0.1W, 1/10W Chip Resistor 0603 (1608 Metric) Anti-Sulfur, Automotive AEC-Q200 Thick Film | R21 | RESC1608X50N | RCA0603100KFKEA | 1
5.1 kΩ, 1% | Resistor | R22, R23 | RESC1608X55N | RC0603FR-071KL | 2
1M | Resistor | R25 | RESC1608X55N | RC0603FR-071KL | 1
MCP2221A-I/SL | IC USB TO I2C/UART 14SOIC | U1 | FP-C04-065-SL-MFG | CMP-06284-000011-1 | 1
PT10MV11-104A2020-S | Variable Resistor | VR1 | PT10MV11104A2020S | PT10MV11-104A2020-S | 1
ABS07-32.768KHZ-T | Crystal or Oscillator | Y1 | ABS07 | ABS07-32.768KHZ-T | 1
ASCO-8.000MHZ-EK-T3 | Crystal or Oscillator | Y2 | ASCO16000MHZEKT | ASCO-8.000MHZ-EK-T3 | 1

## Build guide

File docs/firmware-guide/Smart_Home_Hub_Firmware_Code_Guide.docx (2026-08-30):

THOMAS MORE · ELECTRONICS-ICT

SMART HOME HUB

Firmware Code Guide

Function-by-function explanation of the STM32F746 smart-home firmware

Student | Mahmoud Mostafa
Target | STM32F746BGT6 · STM32CubeIDE / HAL
Source baseline | SmartHome_Weather_GUI_CubeIDE
Functions documented | 141
Build state | 124 active · 17 conditional/diagnostic
Revision | 1.0 · 15 August 2026

SCOPE

This guide documents every function defined in main.c and qspi_assets.c. Generated bitmap/font arrays and STM32 HAL library internals contain no project functions and are described only at module level.

1 How the firmware is organized

A map from startup to sensing, safety, presentation and cloud services

The firmware is a cooperative, super-loop application. It has no RTOS: main() owns the schedule and invokes short local tasks at fixed HAL tick intervals. The only intentionally blocking work is ESP-01 AT/HTTP communication; flame safety is sampled inside those waits and the buzzer is restored immediately afterward.


Figure 1. Main-loop scheduling and the local-safety priority path.

## 1.1 Source modules

Module | Role | Function definitions
Core/Src/main.c | Application, drivers, GUI, scheduling and CubeMX initializers | 109
Core/Src/qspi_assets.c | W25Q128 asset installer, CRC validation and memory-mapped accessors | 32
gui_modern_assets.c | Generated font and icon byte arrays; no functions | 0
weather_backgrounds.c | Generated weather background byte arrays; no functions | 0

## 1.2 Important data ownership

Data | Owner / address | Why it matters
GUI frame 0 | SDRAM 0xC0000000 | Visible or drawing L8 frame, depending on current swap state
GUI frame 1 | SDRAM 0xC0040000 | Second full-screen L8 frame for tear-free updates
Weather/fonts/icons | QSPI 0x90000000 window | Persistent, CRC-checked read-only assets after startup
SensorValues | Internal SRAM | Latest validated local readings and alarm state
InternetWeather | Internal SRAM | Detected location, time sync, weather cache and selected theme

UNITS

Temperatures and relative humidity use integer tenths (for example 302 means 30.2 °C). Pressure uses hPa×10. This avoids float-dependent logic in the safety and formatting paths.

2 Complete function reference

Every function defined by the project, including conditional diagnostics and installer-only helpers

Entries are grouped by subsystem rather than source order. “Active” means compiled in the normal application. Conditional entries remain useful documentation but are excluded by #if 0, QSPI_ASSET_INSTALLER or USE_FULL_ASSERT in a normal release build.

## 2.1 Startup, scheduler and fault handling

6 functions in this subsystem.

Function | What it does / how it works | Interface | Dependencies
MPU_FixExternalMemory() main.c:2394–2446 Active | Re-applies safe MPU regions for FMC/QSPI registers, 8 MiB SDRAM and the 16 MiB memory-mapped QSPI window. It coordinates HAL_MPU_Disable(), HAL_MPU_ConfigRegion(), HAL_MPU_Enable(). | In: None. Out: No return value; the function acts through hardware, buffers or state. | Calls: HAL_MPU_Disable(), HAL_MPU_ConfigRegion(), HAL_MPU_Enable(), __DSB(), __ISB(); Uses: LTDC.
main() main.c:5036–5467 Active | Initializes memory, peripherals, sensors and Wi-Fi, then runs the cooperative scheduler for sampling, alarms, GUI, weather and Blynk uploads. It coordinates MPU_Config(), HAL_Init(), MPU_FixExternalMemory(), SystemClock_Config(), MX_GPIO_Init(), MX_LTDC_Init(). The implementation contains 31 explicit decision/error checks and 1 loop. | In: None. Out: Returns a numeric result of type int. | Calls: MPU_Config(), HAL_Init(), MPU_FixExternalMemory(), SystemClock_Config(), MX_GPIO_Init(), MX_LTDC_Init(), MX_USART1_UART_Init(), MX_ADC1_Init(); Uses: LTDC, QUADSPI/W25Q128, USART3 debug, buzzer GPIO.
SystemClock_Config() main.c:5474–5524 Active | Configures HSE/PLL clocks for the 200 MHz Cortex-M7 system and peripheral clock domains. It coordinates HAL_PWR_EnableBkUpAccess(), HAL_RCC_OscConfig(), Error_Handler(), HAL_PWREx_EnableOverDrive(), HAL_RCC_ClockConfig(). The implementation contains 3 explicit decision/error checks. | In: None. Out: No return value; the function acts through hardware, buffers or state. | Calls: HAL_PWR_EnableBkUpAccess(), __HAL_RCC_PWR_CLK_ENABLE(), __HAL_PWR_VOLTAGESCALING_CONFIG(), HAL_RCC_OscConfig(), Error_Handler(), HAL_PWREx_EnableOverDrive(), HAL_RCC_ClockConfig().
MPU_Config() main.c:6061–6111 Active | Installs the base MPU policy before HAL startup, including protection required by the Cortex-M7 memory system. It coordinates HAL_MPU_Disable(), HAL_MPU_ConfigRegion(), HAL_MPU_Enable(). | In: None. Out: No return value; the function acts through hardware, buffers or state. | Calls: HAL_MPU_Disable(), HAL_MPU_ConfigRegion(), HAL_MPU_Enable().
Error_Handler() main.c:6118–6126 Active | Disables interrupts and traps execution after an unrecoverable initialization or HAL error. The implementation contains 1 loop. | In: None. Out: No return value; the function acts through hardware, buffers or state. | Calls: __disable_irq().
assert_failed() main.c:6136–6141 USE_FULL_ASSERT only | Optional full-assert callback that exposes the source file and line of a failed HAL assertion to the debugger. | In: uint8_t *file, uint32_t line Out: No return value; the function acts through hardware, buffers or state. | Pure/local helper; no direct peripheral dependency detected..

## 2.2 CubeMX peripheral initialization

10 functions in this subsystem.

Function | What it does / how it works | Interface | Dependencies
MX_ADC1_Init() main.c:5532–5577 Active | Configures ADC1 for the PA1 flame analog channel. It coordinates HAL_ADC_Init(), Error_Handler(), HAL_ADC_ConfigChannel(). The implementation contains 2 explicit decision/error checks. | In: None. Out: No return value; the function acts through hardware, buffers or state. | Calls: HAL_ADC_Init(), Error_Handler(), HAL_ADC_ConfigChannel(); Uses: ADC1/PA1.
MX_I2C1_Init() main.c:5585–5625 Active | Configures I2C1 retained for the display/touch hardware path. It coordinates HAL_I2C_Init(), Error_Handler(), HAL_I2CEx_ConfigAnalogFilter(), HAL_I2CEx_ConfigDigitalFilter(). The implementation contains 3 explicit decision/error checks. | In: None. Out: No return value; the function acts through hardware, buffers or state. | Calls: HAL_I2C_Init(), Error_Handler(), HAL_I2CEx_ConfigAnalogFilter(), HAL_I2CEx_ConfigDigitalFilter().
MX_I2C3_Init() main.c:5633–5673 Active | Configures I2C3 for the BME688 bus. It coordinates HAL_I2C_Init(), Error_Handler(), HAL_I2CEx_ConfigAnalogFilter(), HAL_I2CEx_ConfigDigitalFilter(). The implementation contains 3 explicit decision/error checks. | In: None. Out: No return value; the function acts through hardware, buffers or state. | Calls: HAL_I2C_Init(), Error_Handler(), HAL_I2CEx_ConfigAnalogFilter(), HAL_I2CEx_ConfigDigitalFilter(); Uses: I2C3/BME688.
MX_I2C4_Init() main.c:5681–5721 Active | Configures I2C4 for the SCD41 bus. It coordinates HAL_I2C_Init(), Error_Handler(), HAL_I2CEx_ConfigAnalogFilter(), HAL_I2CEx_ConfigDigitalFilter(). The implementation contains 3 explicit decision/error checks. | In: None. Out: No return value; the function acts through hardware, buffers or state. | Calls: HAL_I2C_Init(), Error_Handler(), HAL_I2CEx_ConfigAnalogFilter(), HAL_I2CEx_ConfigDigitalFilter(); Uses: I2C4/SCD41.
MX_LTDC_Init() main.c:5729–5817 Active | Programs LTDC timing, polarity, pixel clock interface and initial layers for the 480×272 RGB panel. It coordinates HAL_LTDC_Init(), Error_Handler(), HAL_LTDC_ConfigLayer(). The implementation contains 4 explicit decision/error checks. | In: None. Out: No return value; the function acts through hardware, buffers or state. | Calls: HAL_LTDC_Init(), Error_Handler(), HAL_LTDC_ConfigLayer(); Uses: LTDC.
MX_QUADSPI_Init() main.c:5825–5854 Active | Configures the STM32 QUADSPI peripheral for the W25Q128 flash geometry and clock. It coordinates HAL_QSPI_Init(), Error_Handler(). The implementation contains 1 explicit decision/error check. | In: None. Out: No return value; the function acts through hardware, buffers or state. | Calls: HAL_QSPI_Init(), Error_Handler(); Uses: LTDC, QUADSPI/W25Q128.
MX_USART1_UART_Init() main.c:5862–5889 Active | Configures USART1 for ESP-01 AT communication. It coordinates HAL_UART_Init(), Error_Handler(). The implementation contains 1 explicit decision/error check. | In: None. Out: No return value; the function acts through hardware, buffers or state. | Calls: HAL_UART_Init(), Error_Handler(); Uses: USART1/ESP-01.
MX_USART3_UART_Init() main.c:5897–5924 Active | Configures USART3 as the firmware diagnostic/debug UART. It coordinates HAL_UART_Init(), Error_Handler(). The implementation contains 1 explicit decision/error check. | In: None. Out: No return value; the function acts through hardware, buffers or state. | Calls: HAL_UART_Init(), Error_Handler(); Uses: USART3 debug.
MX_FMC_Init() main.c:5928–5972 Active | Configures FMC SDRAM Bank 1 bus width, row/column geometry and timing for the IS42S16400J. It coordinates HAL_SDRAM_Init(), Error_Handler(). The implementation contains 1 explicit decision/error check. | In: None. Out: No return value; the function acts through hardware, buffers or state. | Calls: HAL_SDRAM_Init(), Error_Handler(); Uses: FMC/SDRAM.
MX_GPIO_Init() main.c:5980–6052 Active | Enables GPIO clocks, establishes safe output levels and configures buzzer, flame, ESP and control pins. It coordinates HAL_GPIO_WritePin(), HAL_GPIO_Init(), HAL_Delay(). | In: None. Out: No return value; the function acts through hardware, buffers or state. | Calls: __HAL_RCC_GPIOE_CLK_ENABLE(), __HAL_RCC_GPIOC_CLK_ENABLE(), __HAL_RCC_GPIOI_CLK_ENABLE(), __HAL_RCC_GPIOF_CLK_ENABLE(), __HAL_RCC_GPIOH_CLK_ENABLE(), __HAL_RCC_GPIOA_CLK_ENABLE(), __HAL_RCC_GPIOB_CLK_ENABLE(), __HAL_RCC_GPIOJ_CLK_ENABLE(); Uses: buzzer GPIO.

## 2.3 External memory and QSPI assets

43 functions in this subsystem.

Function | What it does / how it works | Interface | Dependencies
SDRAM_Startup() main.c:1920–1971 Active | Sends the JEDEC SDRAM power-up command sequence and programs the proven 66.7 MHz refresh count. It coordinates HAL_SDRAM_SendCommand(), HAL_Delay(), HAL_SDRAM_ProgramRefreshRate(). The implementation contains 4 explicit decision/error checks. | In: None. Out: HAL_OK on success; HAL_ERROR (or another HAL status) is propagated on failure. | Calls: HAL_SDRAM_SendCommand(), HAL_Delay(), HAL_SDRAM_ProgramRefreshRate(); Uses: FMC/SDRAM.
SDRAM_Test() main.c:1982–2051 Disabled diagnostic (#if 0) | Destructively writes and verifies two complementary pseudo-random patterns across all 8 MiB while caches are disabled. The implementation contains 6 explicit decision/error checks and 3 loops. | In: None. Out: true when the operation/result is valid; false on unavailable data, validation failure or I/O error. | Calls: SCB_CleanDCache(), SCB_DisableDCache(), __DSB(), SCB_InvalidateDCache(), SCB_EnableDCache().
QSPI_CommandDefaults() main.c:2059–2072 Disabled diagnostic (#if 0) | Legacy diagnostic copy: initializes a QSPI command descriptor with safe single-line defaults before a helper specializes it. | In: QSPI_CommandTypeDef *cmd, uint8_t instruction Out: No return value; the function acts through hardware, buffers or state. | Pure/local helper; no direct peripheral dependency detected..
QSPI_CommandOnly() main.c:2075–2081 Disabled diagnostic (#if 0) | Legacy diagnostic copy: sends a one-byte flash instruction that has no address or data phase. It coordinates QSPI_CommandDefaults(), HAL_QSPI_Command(). | In: uint8_t instruction Out: HAL_OK on success; HAL_ERROR (or another HAL status) is propagated on failure. | Calls: QSPI_CommandDefaults(), HAL_QSPI_Command(); Uses: QUADSPI/W25Q128.
QSPI_ReadRegister() main.c:2085–2096 Disabled diagnostic (#if 0) | Legacy diagnostic copy: reads one W25Q128 status/register byte through a single-line data phase. It coordinates QSPI_CommandDefaults(), HAL_QSPI_Command(), HAL_QSPI_Receive(). The implementation contains 1 explicit decision/error check. | In: uint8_t instruction, uint8_t *value Out: HAL_OK on success; HAL_ERROR (or another HAL status) is propagated on failure. | Calls: QSPI_CommandDefaults(), HAL_QSPI_Command(), HAL_QSPI_Receive(); Uses: QUADSPI/W25Q128.
QSPI_PollStatus() main.c:2101–2123 Disabled diagnostic (#if 0) | Legacy diagnostic copy: uses HAL automatic polling to wait until masked W25Q128 status bits match an expected value. It coordinates QSPI_CommandDefaults(), HAL_QSPI_AutoPolling(). | In: uint8_t match, uint8_t mask, uint32_t timeout Out: HAL_OK on success; HAL_ERROR (or another HAL status) is propagated on failure. | Calls: QSPI_CommandDefaults(), HAL_QSPI_AutoPolling(); Uses: QUADSPI/W25Q128.
QSPI_WaitReady() main.c:2126–2129 Disabled diagnostic (#if 0) | Legacy diagnostic copy: waits for the W25Q128 BUSY bit to clear. It coordinates QSPI_PollStatus(). | In: uint32_t timeout Out: HAL_OK on success; HAL_ERROR (or another HAL status) is propagated on failure. | Calls: QSPI_PollStatus().
QSPI_WriteEnable() main.c:2132–2138 Disabled diagnostic (#if 0) | Legacy diagnostic copy: issues Write Enable and confirms the write-enable latch before erase/program operations. It coordinates QSPI_CommandOnly(), QSPI_PollStatus(). The implementation contains 1 explicit decision/error check. | In: None. Out: HAL_OK on success; HAL_ERROR (or another HAL status) is propagated on failure. | Calls: QSPI_CommandOnly(), QSPI_PollStatus().
QSPI_EnableQuadMode() main.c:2141–2175 Disabled diagnostic (#if 0) | Legacy diagnostic copy: reads status register 2, sets the QE bit when needed and verifies that four-line transfers are enabled. It coordinates QSPI_ReadRegister(), QSPI_WriteEnable(), QSPI_CommandDefaults(), HAL_QSPI_Command(), HAL_QSPI_Transmit(), QSPI_WaitReady(). The implementation contains 7 explicit decision/error checks. | In: None. Out: HAL_OK on success; HAL_ERROR (or another HAL status) is propagated on failure. | Calls: QSPI_ReadRegister(), QSPI_WriteEnable(), QSPI_CommandDefaults(), HAL_QSPI_Command(), HAL_QSPI_Transmit(), QSPI_WaitReady(); Uses: QUADSPI/W25Q128.
QSPI_Test() main.c:2179–2307 Disabled diagnostic (#if 0) | Legacy diagnostic copy: destructive legacy flash diagnostic that checks JEDEC ID, erases one sector, programs a pattern and verifies a quad readback. It coordinates QSPI_CommandOnly(), HAL_Delay(), QSPI_CommandDefaults(), HAL_QSPI_Command(), HAL_QSPI_Receive(), QSPI_EnableQuadMode(). The implementation contains 13 explicit decision/error checks and 1 loop. | In: None. Out: true when the operation/result is valid; false on unavailable data, validation failure or I/O error. | Calls: QSPI_CommandOnly(), HAL_Delay(), QSPI_CommandDefaults(), HAL_QSPI_Command(), HAL_QSPI_Receive(), QSPI_EnableQuadMode(), QSPI_WriteEnable(), QSPI_WaitReady(); Uses: QUADSPI/W25Q128.
MemoryTest_Show() main.c:2312–2369 Disabled diagnostic (#if 0) | Displays SDRAM/QSPI diagnostic results, including the first failing SDRAM address and expected/actual words. It coordinates LCD_ClearTextLayer(), LCD_DrawString(), LCD_PresentTextLayer(). The implementation contains 1 explicit decision/error check. | In: bool sdram_ok, bool qspi_ok Out: No return value; the function acts through hardware, buffers or state. | Calls: LCD_ClearTextLayer(), LCD_DrawString(), LCD_PresentTextLayer().
QSPI_CommandDefaults() qspi_assets.c:155–167 Active | Initializes a QSPI command descriptor with safe single-line defaults before a helper specializes it. | In: QSPI_CommandTypeDef *command, uint8_t instruction Out: No return value; the function acts through hardware, buffers or state. | Pure/local helper; no direct peripheral dependency detected..
QSPI_CommandOnly() qspi_assets.c:170–175 Active | Sends a one-byte flash instruction that has no address or data phase. It coordinates QSPI_CommandDefaults(), HAL_QSPI_Command(). | In: uint8_t instruction Out: HAL_OK on success; HAL_ERROR (or another HAL status) is propagated on failure. | Calls: QSPI_CommandDefaults(), HAL_QSPI_Command().
QSPI_ReadRegister() qspi_assets.c:179–190 Active | Reads one W25Q128 status/register byte through a single-line data phase. It coordinates QSPI_CommandDefaults(), HAL_QSPI_Command(), HAL_QSPI_Receive(). The implementation contains 1 explicit decision/error check. | In: uint8_t instruction, uint8_t *value Out: HAL_OK on success; HAL_ERROR (or another HAL status) is propagated on failure. | Calls: QSPI_CommandDefaults(), HAL_QSPI_Command(), HAL_QSPI_Receive().
QSPI_PollStatus() qspi_assets.c:195–215 Active | Uses HAL automatic polling to wait until masked W25Q128 status bits match an expected value. It coordinates QSPI_CommandDefaults(), HAL_QSPI_AutoPolling(). | In: uint8_t match, uint8_t mask, uint32_t timeout Out: HAL_OK on success; HAL_ERROR (or another HAL status) is propagated on failure. | Calls: QSPI_CommandDefaults(), HAL_QSPI_AutoPolling().
QSPI_WaitReady() qspi_assets.c:218–220 Active | Waits for the W25Q128 BUSY bit to clear. It coordinates QSPI_PollStatus(). | In: uint32_t timeout Out: HAL_OK on success; HAL_ERROR (or another HAL status) is propagated on failure. | Calls: QSPI_PollStatus().
QSPI_WriteEnable() qspi_assets.c:223–228 Active | Issues Write Enable and confirms the write-enable latch before erase/program operations. It coordinates QSPI_CommandOnly(), QSPI_PollStatus(). The implementation contains 1 explicit decision/error check. | In: None. Out: HAL_OK on success; HAL_ERROR (or another HAL status) is propagated on failure. | Calls: QSPI_CommandOnly(), QSPI_PollStatus().
QSPI_EnableQuadMode() qspi_assets.c:231–263 Active | Reads status register 2, sets the QE bit when needed and verifies that four-line transfers are enabled. It coordinates QSPI_ReadRegister(), QSPI_WriteEnable(), QSPI_CommandDefaults(), HAL_QSPI_Command(), HAL_QSPI_Transmit(), QSPI_WaitReady(). The implementation contains 7 explicit decision/error checks. | In: None. Out: HAL_OK on success; HAL_ERROR (or another HAL status) is propagated on failure. | Calls: QSPI_ReadRegister(), QSPI_WriteEnable(), QSPI_CommandDefaults(), HAL_QSPI_Command(), HAL_QSPI_Transmit(), QSPI_WaitReady().
QSPI_Read() qspi_assets.c:268–285 Active | Reads an arbitrary asset range with quad-output fast read into an STM32 buffer. It coordinates QSPI_CommandDefaults(), HAL_QSPI_Command(), HAL_QSPI_Receive(). The implementation contains 2 explicit decision/error checks. | In: uint32_t address, uint8_t *destination, uint32_t length Out: HAL_OK on success; HAL_ERROR (or another HAL status) is propagated on failure. | Calls: QSPI_CommandDefaults(), HAL_QSPI_Command(), HAL_QSPI_Receive().
QSPI_EraseAssetRegion() qspi_assets.c:290–312 Installer build only | Installer-only routine that erases every sector occupied by the asset store. It coordinates QSPI_WriteEnable(), QSPI_CommandDefaults(), HAL_QSPI_Command(), QSPI_WaitReady(). The implementation contains 3 explicit decision/error checks and 1 loop. | In: None. Out: HAL_OK on success; HAL_ERROR (or another HAL status) is propagated on failure. | Calls: QSPI_WriteEnable(), QSPI_CommandDefaults(), HAL_QSPI_Command(), QSPI_WaitReady().
QSPI_Program() qspi_assets.c:317–358 Installer build only | Installer-only paged programmer that respects 256-byte W25Q128 page boundaries and waits after every page. It coordinates QSPI_WriteEnable(), QSPI_CommandDefaults(), HAL_QSPI_Command(), HAL_QSPI_Transmit(), QSPI_WaitReady(). The implementation contains 5 explicit decision/error checks and 1 loop. | In: uint32_t address, const uint8_t *source, uint32_t length Out: HAL_OK on success; HAL_ERROR (or another HAL status) is propagated on failure. | Calls: QSPI_WriteEnable(), QSPI_CommandDefaults(), HAL_QSPI_Command(), HAL_QSPI_Transmit(), QSPI_WaitReady().
CRC32_Update() qspi_assets.c:365–378 Active | Updates the asset CRC-32 accumulator over a byte sequence. The implementation contains 2 loops. | In: uint32_t crc, const uint8_t *data, uint32_t length Out: Returns a numeric result of type uint32_t. | Pure/local helper; no direct peripheral dependency detected..
CRC32_Buffer() qspi_assets.c:381–383 Active | Calculates a complete CRC-32 for one in-memory buffer. It coordinates CRC32_Update(). | In: const uint8_t *data, uint32_t length Out: Returns a numeric result of type uint32_t. | Calls: CRC32_Update().
QSPI_SourceFontCRC() qspi_assets.c:388–399 Installer build only | Installer-only CRC calculation over the built-in legacy font source arrays. It coordinates CRC32_Update(). | In: None. Out: Returns a numeric result of type uint32_t. | Calls: CRC32_Update().
QSPI_SourceWeatherCRC() qspi_assets.c:405–435 Installer build only | Installer-only CRC calculation over all compiled weather background assets. It coordinates CRC32_Update(). The implementation contains 3 loops. | In: None. Out: Returns a numeric result of type uint32_t. | Calls: CRC32_Update().
QSPI_HeaderMatchesInstallerSource() qspi_assets.c:439–448 Installer build only | Checks whether the installed header version, sizes and CRCs already match the compiled installer sources. It coordinates QSPI_SourceWeatherCRC(), CRC32_Buffer(), QSPI_SourceFontCRC(). | In: const QSPI_AssetHeader *header Out: true when the operation/result is valid; false on unavailable data, validation failure or I/O error. | Calls: QSPI_SourceWeatherCRC(), CRC32_Buffer(), QSPI_SourceFontCRC().
QSPI_CRCRegion() qspi_assets.c:455–477 Active | Streams a QSPI region in chunks and computes its CRC without requiring a region-sized RAM buffer. It coordinates QSPI_Read(), CRC32_Update(). The implementation contains 2 explicit decision/error checks and 1 loop. | In: uint32_t address, uint32_t length, uint32_t *result Out: HAL_OK on success; HAL_ERROR (or another HAL status) is propagated on failure. | Calls: QSPI_Read(), CRC32_Update().
QSPI_HeaderIsValid() qspi_assets.c:480–509 Active | Validates asset magic, version, offsets, lengths and the header's own CRC before any pointer is exposed. It coordinates CRC32_Buffer(). The implementation contains 2 explicit decision/error checks. | In: const QSPI_AssetHeader *header Out: true when the operation/result is valid; false on unavailable data, validation failure or I/O error. | Calls: CRC32_Buffer().
QSPI_VerifyAssets() qspi_assets.c:512–551 Active | Recomputes CRCs for background, palette, legacy font and modern asset regions and compares them with the header. It coordinates QSPI_HeaderIsValid(), QSPI_CRCRegion(). The implementation contains 5 explicit decision/error checks. | In: const QSPI_AssetHeader *header Out: HAL_OK on success; HAL_ERROR (or another HAL status) is propagated on failure. | Calls: QSPI_HeaderIsValid(), QSPI_CRCRegion().
QSPI_InstallAssets() qspi_assets.c:556–678 Installer build only | Erases and programs the header, weather images, palette, fonts and icons, then verifies the completed flash image. It coordinates QSPI_EraseAssetRegion(), QSPI_Program(), QSPI_SourceWeatherCRC(), CRC32_Buffer(), QSPI_SourceFontCRC(), QSPI_Read(). The implementation contains 7 explicit decision/error checks and 3 loops. | In: QSPI_AssetHeader *header Out: HAL_OK on success; HAL_ERROR (or another HAL status) is propagated on failure. | Calls: QSPI_EraseAssetRegion(), QSPI_Program(), QSPI_SourceWeatherCRC(), CRC32_Buffer(), QSPI_SourceFontCRC(), QSPI_Read(), QSPI_VerifyAssets().
QSPI_EnterMemoryMappedMode() qspi_assets.c:683–696 Active | Places the W25Q128 in continuous memory-mapped quad-read mode at 0x90000000. It coordinates QSPI_CommandDefaults(), HAL_QSPI_MemoryMapped(). | In: None. Out: HAL_OK on success; HAL_ERROR (or another HAL status) is propagated on failure. | Calls: QSPI_CommandDefaults(), HAL_QSPI_MemoryMapped().
QSPI_Assets_Init() qspi_assets.c:700–787 Active | Resets and identifies the flash, enables quad mode, installs assets when requested, validates CRCs and enters memory-mapped mode. It coordinates QSPI_CommandOnly(), HAL_Delay(), QSPI_CommandDefaults(), HAL_QSPI_Command(), HAL_QSPI_Receive(), QSPI_EnableQuadMode(). The implementation contains 11 explicit decision/error checks. | In: QSPI_HandleTypeDef *hqspi, bool *installed_now Out: HAL_OK on success; HAL_ERROR (or another HAL status) is propagated on failure. | Calls: QSPI_CommandOnly(), HAL_Delay(), QSPI_CommandDefaults(), HAL_QSPI_Command(), HAL_QSPI_Receive(), QSPI_EnableQuadMode(), QSPI_Read(), QSPI_HeaderIsValid(); Uses: LTDC, QUADSPI/W25Q128.
QSPI_Assets_BackgroundL8() qspi_assets.c:790–792 Active | Compatibility accessor returning the clear-day weather background pointer. It coordinates QSPI_Assets_WeatherBackgroundL8(). | In: None. Out: Pointer into the validated memory-mapped asset store, or NULL when invalid. | Calls: QSPI_Assets_WeatherBackgroundL8().
QSPI_Assets_WeatherBackgroundL8() qspi_assets.c:795–807 Active | Returns the memory-mapped pointer to one selected 480×272 L8 weather background. The implementation contains 2 explicit decision/error checks. | In: QSPI_WeatherTheme theme Out: Pointer into the validated memory-mapped asset store, or NULL when invalid. | Pure/local helper; no direct peripheral dependency detected..
QSPI_Assets_CLUT() qspi_assets.c:810–817 Active | Returns the memory-mapped 256-entry LTDC colour lookup table. The implementation contains 1 explicit decision/error check. | In: None. Out: Pointer into the validated memory-mapped asset store, or NULL when invalid. | Pure/local helper; no direct peripheral dependency detected..
QSPI_Assets_GetGlyph5x7() qspi_assets.c:820–846 Active | Looks up a supported legacy character and returns its seven-row bitmap. The implementation contains 3 explicit decision/error checks and 1 loop. | In: char character Out: Pointer into the validated memory-mapped asset store, or NULL when invalid. | Pure/local helper; no direct peripheral dependency detected..
QSPI_ReadLE16() qspi_assets.c:849–852 Active | Decodes a little-endian 16-bit value from a packed modern-asset byte stream. | In: const uint8_t *data Out: Returns a numeric result of type uint16_t. | Pure/local helper; no direct peripheral dependency detected..
QSPI_ReadLE32() qspi_assets.c:855–860 Active | Decodes a little-endian 32-bit value from a packed modern-asset byte stream. | In: const uint8_t *data Out: Returns a numeric result of type uint32_t. | Pure/local helper; no direct peripheral dependency detected..
QSPI_ModernAssetBase() qspi_assets.c:863–888 Active | Validates the modern-font sub-header and returns its memory-mapped base pointer. It coordinates QSPI_ReadLE32(), QSPI_ReadLE16(). The implementation contains 2 explicit decision/error checks. | In: None. Out: Pointer into the validated memory-mapped asset store, or NULL when invalid. | Calls: QSPI_ReadLE32(), QSPI_ReadLE16().
QSPI_Assets_GetModernGlyph() qspi_assets.c:893–941 Active | Locates a character descriptor for a selected font size and fills a QSPI_FontGlyph view of its bitmap. It coordinates QSPI_ModernAssetBase(), QSPI_ReadLE32(). The implementation contains 5 explicit decision/error checks. | In: QSPI_FontSize size, char character, QSPI_FontGlyph *glyph Out: true when the operation/result is valid; false on unavailable data, validation failure or I/O error. | Calls: QSPI_ModernAssetBase(), QSPI_ReadLE32().
QSPI_Assets_ModernLineHeight() qspi_assets.c:944–951 Active | Returns the recommended line height for small, medium or large modern font. It coordinates QSPI_ModernAssetBase(). The implementation contains 1 explicit decision/error check. | In: QSPI_FontSize size Out: Returns a numeric result of type uint8_t. | Calls: QSPI_ModernAssetBase().
QSPI_Assets_GetIcon() qspi_assets.c:954–971 Active | Returns the bitmap address of a selected 20×20 icon after validating the requested index and asset bounds. It coordinates QSPI_ModernAssetBase(), QSPI_ReadLE32(). The implementation contains 2 explicit decision/error checks. | In: QSPI_Icon icon Out: Pointer into the validated memory-mapped asset store, or NULL when invalid. | Calls: QSPI_ModernAssetBase(), QSPI_ReadLE32().
QSPI_Assets_LastError() qspi_assets.c:974–976 Active | Returns the last detailed asset initialization/validation error code. | In: None. Out: Returns QSPI_AssetError. | Pure/local helper; no direct peripheral dependency detected..

## 2.4 Display, drawing and GUI

30 functions in this subsystem.

Function | What it does / how it works | Interface | Dependencies
LCD_SetBackground() main.c:200–211 Active | Disables the framebuffer layers and sets the LTDC controller's solid RGB background colour. | In: uint8_t red, uint8_t green, uint8_t blue Out: No return value; the function acts through hardware, buffers or state. | Uses: LTDC.
LCD_DrawPixel() main.c:256–261 Active | Writes one palette index to the current SDRAM back buffer after checking the display bounds. The implementation contains 1 explicit decision/error check. | In: uint16_t x, uint16_t y, uint16_t colour Out: No return value; the function acts through hardware, buffers or state. | Uses: SDRAM framebuffer.
LCD_FillRectangle() main.c:268–279 Active | Clips a rectangle to the panel and fills its pixels in the active back buffer. It coordinates LCD_DrawPixel(). The implementation contains 2 loops. | In: uint16_t x, uint16_t y, uint16_t width, uint16_t height, uint16_t colour Out: No return value; the function acts through hardware, buffers or state. | Calls: LCD_DrawPixel().
LCD_ClearTextLayer() main.c:282–291 Active | Fills the complete 480×272 L8 GUI buffer with one palette entry. The implementation contains 1 loop. | In: uint16_t colour Out: No return value; the function acts through hardware, buffers or state. | Uses: SDRAM framebuffer.
LCD_LoadBackground() main.c:294–303 Active | Copies the selected weather image from memory-mapped QSPI into the SDRAM back buffer, scaling the stored half-resolution asset to the panel. The implementation contains 1 explicit decision/error check. | In: None. Out: true when the operation/result is valid; false on unavailable data, validation failure or I/O error. | Uses: SDRAM framebuffer.
LCD_RestoreBackgroundRectangle() main.c:309–333 Active | Reconstructs a damaged sub-rectangle of the back buffer from the selected QSPI background. The implementation contains 3 explicit decision/error checks and 1 loop. | In: uint16_t x, uint16_t y, uint16_t width, uint16_t height Out: No return value; the function acts through hardware, buffers or state. | Uses: SDRAM framebuffer.
LCD_FontFromScale() main.c:336–344 Active | Maps the legacy numeric text scale to the small, medium or large proportional QSPI font. The implementation contains 2 explicit decision/error checks. | In: uint8_t scale Out: Returns QSPI_FontSize. | Pure/local helper; no direct peripheral dependency detected..
LCD_MeasureString() main.c:347–367 Active | Calculates the pixel width of a string so text can be centered or right-aligned before drawing. It coordinates LCD_FontFromScale(). The implementation contains 3 explicit decision/error checks and 1 loop. | In: const char *text, uint8_t scale Out: Returns a numeric result of type uint16_t. | Calls: LCD_FontFromScale().
LCD_DrawCharacter() main.c:374–409 Active | Renders one proportional QSPI glyph into the L8 SDRAM buffer and returns its horizontal advance. It coordinates LCD_FontFromScale(), LCD_DrawPixel(). The implementation contains 3 explicit decision/error checks and 2 loops. | In: uint16_t x, uint16_t y, char character, uint16_t colour, uint8_t scale Out: Returns a numeric result of type uint8_t. | Calls: LCD_FontFromScale(), LCD_DrawPixel().
LCD_DrawString() main.c:416–429 Active | Renders a null-terminated string from left to right using LCD_DrawCharacter. It coordinates LCD_DrawCharacter(). The implementation contains 1 explicit decision/error check and 1 loop. | In: uint16_t x, uint16_t y, const char *text, uint16_t colour, uint8_t scale Out: No return value; the function acts through hardware, buffers or state. | Calls: LCD_DrawCharacter().
LCD_DrawCenteredString() main.c:435–445 Active | Measures a string and draws it horizontally centered on the 480-pixel panel. It coordinates LCD_MeasureString(), LCD_DrawString(). The implementation contains 1 explicit decision/error check. | In: uint16_t y, const char *text, uint16_t colour, uint8_t scale Out: No return value; the function acts through hardware, buffers or state. | Calls: LCD_MeasureString(), LCD_DrawString().
LCD_MeasureStringZoom() main.c:450–469 Active | Measures a string using an explicitly selected QSPI font and integer zoom factor. The implementation contains 3 explicit decision/error checks and 1 loop. | In: const char *text, QSPI_FontSize font, uint8_t zoom Out: Returns a numeric result of type uint16_t. | Pure/local helper; no direct peripheral dependency detected..
LCD_DrawCharacterZoom() main.c:477–523 Active | Draws one modern proportional glyph with integer pixel enlargement and clipping. It coordinates LCD_DrawPixel(). The implementation contains 3 explicit decision/error checks and 4 loops. | In: uint16_t x, uint16_t y, char character, uint16_t colour, QSPI_FontSize font, uint8_t zoom Out: Returns a numeric result of type uint16_t. | Calls: LCD_DrawPixel().
LCD_DrawStringZoom() main.c:531–549 Active | Draws a complete string with the selected modern font and zoom. It coordinates LCD_DrawCharacterZoom(). The implementation contains 2 explicit decision/error checks and 1 loop. | In: uint16_t x, uint16_t y, const char *text, uint16_t colour, QSPI_FontSize font, uint8_t zoom Out: No return value; the function acts through hardware, buffers or state. | Calls: LCD_DrawCharacterZoom().
LCD_DrawCenteredStringShadow() main.c:555–562 Active | Draws centered text twice—offset dark shadow first, coloured foreground second—for contrast on photographs. It coordinates LCD_MeasureString(), LCD_DrawString(). | In: uint16_t y, const char *text, uint16_t colour, uint8_t scale Out: No return value; the function acts through hardware, buffers or state. | Calls: LCD_MeasureString(), LCD_DrawString().
LCD_DrawStringShadow() main.c:569–572 Active | Draws left-aligned shadowed text at an explicit coordinate. It coordinates LCD_DrawString(). | In: uint16_t x, uint16_t y, const char *text, uint16_t colour, uint8_t scale Out: No return value; the function acts through hardware, buffers or state. | Calls: LCD_DrawString().
LCD_DrawRightStringShadow() main.c:579–584 Active | Measures and draws shadowed text against a right-hand coordinate. It coordinates LCD_MeasureString(), LCD_DrawStringShadow(). | In: uint16_t right, uint16_t y, const char *text, uint16_t colour, uint8_t scale Out: No return value; the function acts through hardware, buffers or state. | Calls: LCD_MeasureString(), LCD_DrawStringShadow().
LCD_DrawCenteredZoomShadow() main.c:591–598 Active | Centers and draws enlarged modern text with a one-pixel shadow. It coordinates LCD_MeasureStringZoom(), LCD_DrawStringZoom(). | In: uint16_t y, const char *text, uint16_t colour, QSPI_FontSize font, uint8_t zoom Out: No return value; the function acts through hardware, buffers or state. | Calls: LCD_MeasureStringZoom(), LCD_DrawStringZoom().
LCD_DrawIcon() main.c:604–623 Active | Reads a 20×20 monochrome icon from QSPI and paints its set bits into the GUI buffer. It coordinates LCD_DrawPixel(). The implementation contains 2 explicit decision/error checks and 2 loops. | In: uint16_t x, uint16_t y, QSPI_Icon icon, uint16_t colour Out: No return value; the function acts through hardware, buffers or state. | Calls: LCD_DrawPixel().
LCD_PresentTextLayer() main.c:626–662 Active | Waits for vertical blanking, swaps the front/back SDRAM buffers, updates LTDC layer address, then selects the old front buffer for the next frame. It coordinates HAL_GetTick(), Error_Handler(). The implementation contains 2 explicit decision/error checks and 1 loop. | In: None. Out: No return value; the function acts through hardware, buffers or state. | Calls: __DSB(), HAL_GetTick(), Error_Handler(); Uses: LTDC, SDRAM framebuffer.
LCD_ConfigureTextLayer() main.c:665–715 Active | Programs the LTDC L8 foreground layer, loads the colour lookup table and prepares both SDRAM framebuffers for double buffering. It coordinates Error_Handler(), HAL_LTDC_ConfigLayer(), HAL_LTDC_ConfigCLUT(), HAL_LTDC_EnableCLUT(). The implementation contains 4 explicit decision/error checks. | In: None. Out: No return value; the function acts through hardware, buffers or state. | Calls: Error_Handler(), HAL_LTDC_ConfigLayer(), HAL_LTDC_ConfigCLUT(), HAL_LTDC_EnableCLUT(), __HAL_LTDC_LAYER_DISABLE(), __HAL_LTDC_LAYER_ENABLE(), __HAL_LTDC_RELOAD_CONFIG(); Uses: LTDC, SDRAM framebuffer.
LCD_TextDemo() main.c:718–737 Active | Optional bench page that exercises QSPI fonts, colours and icons before the normal dashboard starts. It coordinates LCD_ConfigureTextLayer(), LCD_ClearTextLayer(), LCD_DrawCenteredString(), LCD_PresentTextLayer(). | In: None. Out: No return value; the function acts through hardware, buffers or state. | Calls: LCD_ConfigureTextLayer(), LCD_ClearTextLayer(), LCD_DrawCenteredString(), LCD_PresentTextLayer().
GUI_DrawRectangle() main.c:1229–1237 Active | Draws a rectangular outline by combining four filled edge rectangles. It coordinates LCD_FillRectangle(). The implementation contains 1 explicit decision/error check. | In: uint16_t x, uint16_t y, uint16_t width, uint16_t height, uint16_t colour Out: No return value; the function acts through hardware, buffers or state. | Calls: LCD_FillRectangle().
GUI_DrawCard() main.c:1245–1251 Active | Paints a filled dashboard card plus its accent border. It coordinates LCD_FillRectangle(), GUI_DrawRectangle(). | In: uint16_t x, uint16_t y, uint16_t width, uint16_t height, uint16_t fill, uint16_t accent Out: No return value; the function acts through hardware, buffers or state. | Calls: LCD_FillRectangle(), GUI_DrawRectangle().
GUI_DrawCenteredInBox() main.c:1259–1267 Active | Centers a text string inside an arbitrary horizontal box. It coordinates LCD_MeasureString(), LCD_DrawString(). The implementation contains 1 explicit decision/error check. | In: uint16_t x, uint16_t width, uint16_t y, const char *text, uint16_t colour, uint8_t scale Out: No return value; the function acts through hardware, buffers or state. | Calls: LCD_MeasureString(), LCD_DrawString().
GUI_FormatSignedTenths() main.c:1273–1288 Active | Formats a fixed-point signed value stored in tenths without requiring floating-point arithmetic. The implementation contains 1 explicit decision/error check. | In: char *buffer, size_t capacity, int32_t value10, const char *unit Out: No return value; the function acts through hardware, buffers or state. | Pure/local helper; no direct peripheral dependency detected..
GUI_ShowDashboard() main.c:1503–1722 Active | Legacy indoor-only dashboard renderer retained as a fallback/test view. It coordinates AirQuality_Get(), AirQuality_Colour(), LCD_LoadBackground(), Error_Handler(), LCD_DrawString(), GUI_DrawCard(). The implementation contains 10 explicit decision/error checks. | In: bool scd_ok, bool bme_ok, bool wifi_ok, bool blynk_ok, const SensorValues *values Out: No return value; the function acts through hardware, buffers or state. | Calls: AirQuality_Get(), AirQuality_Colour(), LCD_LoadBackground(), Error_Handler(), LCD_DrawString(), GUI_DrawCard(), LCD_DrawIcon(), LCD_RestoreBackgroundRectangle().
GUI_ShowAlarm() main.c:1727–1913 Active | Renders the highest-priority alarm page and updates only the changing value area when possible. It coordinates GUI_FormatSignedTenths(), LCD_ClearTextLayer(), GUI_DrawRectangle(), GUI_DrawCenteredInBox(), LCD_FillRectangle(), LCD_PresentTextLayer(). The implementation contains 4 explicit decision/error checks. | In: SystemAlarm alarm, bool flash, const SensorValues *values Out: No return value; the function acts through hardware, buffers or state. | Calls: GUI_FormatSignedTenths(), LCD_ClearTextLayer(), GUI_DrawRectangle(), GUI_DrawCenteredInBox(), LCD_FillRectangle(), LCD_PresentTextLayer().
LCD_ShowStatus() main.c:2376–2386 Active | Shows a two-line startup status page, but deliberately becomes a no-op after the live dashboard is active. It coordinates LCD_ClearTextLayer(), LCD_DrawCenteredString(), LCD_PresentTextLayer(). The implementation contains 1 explicit decision/error check. | In: const char *line1, const char *line2, uint16_t colour Out: No return value; the function acts through hardware, buffers or state. | Calls: LCD_ClearTextLayer(), LCD_DrawCenteredString(), LCD_PresentTextLayer().
GUI_ShowWeatherDashboard() main.c:4167–4363 Active | Builds the normal weather-and-room dashboard from cached sensor, location, weather and network state, then presents one complete frame. It coordinates Clock_Format(), LCD_LoadBackground(), Error_Handler(), LCD_MeasureString(), HAL_GetTick(), LCD_DrawStringShadow(). The implementation contains 5 explicit decision/error checks. | In: bool scd_ok, bool bme_ok, bool wifi_ok, bool blynk_ok, const SensorValues *values, const InternetWeather *weather Out: No return value; the function acts through hardware, buffers or state. | Calls: Clock_Format(), LCD_LoadBackground(), Error_Handler(), LCD_MeasureString(), HAL_GetTick(), LCD_DrawStringShadow(), LCD_DrawRightStringShadow(), LCD_DrawCenteredStringShadow().

## 2.5 Environmental sensors

11 functions in this subsystem.

Function | What it does / how it works | Interface | Dependencies
SCD41_CRC8() main.c:826–843 Active | Computes the Sensirion CRC-8 used to validate each two-byte SCD41 data word. The implementation contains 1 explicit decision/error check and 2 loops. | In: const uint8_t *data Out: Returns a numeric result of type uint8_t. | Pure/local helper; no direct peripheral dependency detected..
SCD41_SendCommand() main.c:846–857 Active | Serializes a 16-bit command in big-endian order and transmits it on I2C4. It coordinates HAL_I2C_Master_Transmit(). | In: uint16_t command Out: HAL_OK on success; HAL_ERROR (or another HAL status) is propagated on failure. | Calls: HAL_I2C_Master_Transmit(); Uses: I2C4/SCD41.
SCD41_IsDataReady() main.c:860–884 Active | Requests the SCD41 data-ready status, checks its CRC and reports whether a fresh sample is available. It coordinates SCD41_SendCommand(), HAL_Delay(), HAL_I2C_Master_Receive(), SCD41_CRC8(). The implementation contains 3 explicit decision/error checks. | In: None. Out: true when the operation/result is valid; false on unavailable data, validation failure or I/O error. | Calls: SCD41_SendCommand(), HAL_Delay(), HAL_I2C_Master_Receive(), SCD41_CRC8(); Uses: I2C4/SCD41.
SCD41_Init() main.c:887–910 Active | Checks the SCD41 address, stops any previous measurement session, then starts periodic CO₂ measurement. It coordinates HAL_I2C_IsDeviceReady(), SCD41_SendCommand(), HAL_Delay(). The implementation contains 2 explicit decision/error checks. | In: None. Out: true when the operation/result is valid; false on unavailable data, validation failure or I/O error. | Calls: HAL_I2C_IsDeviceReady(), SCD41_SendCommand(), HAL_Delay(); Uses: I2C4/SCD41.
SCD41_Read() main.c:913–972 Active | Reads the SCD41 CO₂, temperature and humidity words, verifies all CRC bytes and updates SensorValues. It coordinates SCD41_IsDataReady(), HAL_Delay(), SCD41_SendCommand(), HAL_I2C_Master_Receive(), SCD41_CRC8(). The implementation contains 5 explicit decision/error checks and 1 loop. | In: SensorValues *values Out: true when the operation/result is valid; false on unavailable data, validation failure or I/O error. | Calls: SCD41_IsDataReady(), HAL_Delay(), SCD41_SendCommand(), HAL_I2C_Master_Receive(), SCD41_CRC8(); Uses: I2C4/SCD41.
BME688_I2C_Read() main.c:993–1006 Active | Bosch-driver callback that reads BME688 registers through STM32 HAL I2C3. It coordinates HAL_I2C_Mem_Read(). | In: uint8_t reg, uint8_t *data, uint32_t length, void *interface_ptr Out: Returns a numeric result of type int8_t. | Calls: HAL_I2C_Mem_Read().
BME688_I2C_Write() main.c:1012–1025 Active | Bosch-driver callback that writes BME688 registers through STM32 HAL I2C3. It coordinates HAL_I2C_Mem_Write(). | In: uint8_t reg, const uint8_t *data, uint32_t length, void *interface_ptr Out: Returns a numeric result of type int8_t. | Calls: HAL_I2C_Mem_Write().
BME688_DelayUs() main.c:1028–1033 Active | Bosch-driver delay callback implemented with HAL_Delay at millisecond resolution. It coordinates HAL_Delay(). The implementation contains 1 explicit decision/error check. | In: uint32_t period_us, void *interface_ptr Out: No return value; the function acts through hardware, buffers or state. | Calls: HAL_Delay().
BME688_Init() main.c:1036–1095 Active | Connects the Bosch BME68x API to I2C3, verifies the chip and configures oversampling, filter and heater settings. It coordinates HAL_I2C_IsDeviceReady(). The implementation contains 5 explicit decision/error checks. | In: None. Out: true when the operation/result is valid; false on unavailable data, validation failure or I/O error. | Calls: HAL_I2C_IsDeviceReady(); Uses: I2C3/BME688.
BME688_Read() main.c:1098–1163 Active | Triggers forced mode, waits for conversion, obtains compensated temperature/humidity/pressure/gas values and stores fixed-point results. The implementation contains 4 explicit decision/error checks. | In: SensorValues *values Out: true when the operation/result is valid; false on unavailable data, validation failure or I/O error. | Pure/local helper; no direct peripheral dependency detected..
BME688_GasTestScreen() main.c:2694–2859 Active | Standalone gas commissioning page that shows raw gas resistance, baseline progress, ratio and alarm state. It coordinates LCD_ClearTextLayer(), LCD_DrawString(), LCD_PresentTextLayer(), BME688_Read(). The implementation contains 9 explicit decision/error checks. | In: bool sensor_online Out: No return value; the function acts through hardware, buffers or state. | Calls: LCD_ClearTextLayer(), LCD_DrawString(), LCD_PresentTextLayer(), BME688_Read().

## 2.6 Flame and gas safety

5 functions in this subsystem.

Function | What it does / how it works | Interface | Dependencies
FlameSensor_ReadADC() main.c:2448–2470 Active | Starts ADC1 on PA1, polls for conversion and returns the raw flame phototransistor value. It coordinates HAL_ADC_Start(), HAL_ADC_PollForConversion(), HAL_ADC_Stop(), HAL_ADC_GetValue(). The implementation contains 3 explicit decision/error checks. | In: uint16_t *raw Out: HAL_OK on success; HAL_ERROR (or another HAL status) is propagated on failure. | Calls: HAL_ADC_Start(), HAL_ADC_PollForConversion(), HAL_ADC_Stop(), HAL_ADC_GetValue(); Uses: ADC1/PA1.
FlameSensor_ReadAll() main.c:2473–2489 Active | Combines the PA1 analog reading with PH2 digital comparator input and updates flame voltage/detected fields. It coordinates HAL_GPIO_ReadPin(), FlameSensor_ReadADC(). The implementation contains 2 explicit decision/error checks. | In: SensorValues *values Out: true when the operation/result is valid; false on unavailable data, validation failure or I/O error. | Calls: HAL_GPIO_ReadPin(), FlameSensor_ReadADC().
GasMonitor_Update() main.c:2492–2600 Active | Learns a clean-air BME688 gas-resistance baseline, calculates the current percentage ratio and applies confirm/clear counters for stable alarms. The implementation contains 12 explicit decision/error checks. | In: SensorValues *values Out: No return value; the function acts through hardware, buffers or state. | Pure/local helper; no direct peripheral dependency detected..
FlameSensor_TestScreen() main.c:2604–2692 Active | Standalone flame-sensor test loop that displays ADC, voltage and digital state. It coordinates HAL_GPIO_ReadPin(), LCD_ClearTextLayer(), LCD_DrawString(), FlameSensor_ReadADC(), HAL_UART_Transmit(), LCD_PresentTextLayer(). The implementation contains 2 explicit decision/error checks. | In: None. Out: No return value; the function acts through hardware, buffers or state. | Calls: HAL_GPIO_ReadPin(), LCD_ClearTextLayer(), LCD_DrawString(), FlameSensor_ReadADC(), HAL_UART_Transmit(), LCD_PresentTextLayer(); Uses: USART3 debug.
Safety_FlameActiveDuringNetwork() main.c:2867–2881 Active | Samples the flame digital input during blocking ESP operations so a fire condition can abort network work immediately. It coordinates HAL_GPIO_ReadPin(), HAL_GPIO_WritePin(). The implementation contains 1 explicit decision/error check. | In: None. Out: true when the operation/result is valid; false on unavailable data, validation failure or I/O error. | Calls: HAL_GPIO_ReadPin(), HAL_GPIO_WritePin(); Uses: buzzer GPIO.

## 2.7 Air-quality and alarm logic

6 functions in this subsystem.

Function | What it does / how it works | Interface | Dependencies
AirQuality_Get() main.c:1293–1311 Active | Classifies indoor air as unknown, good, fair, poor or danger using sensor health, CO₂ and learned gas-ratio thresholds. The implementation contains 4 explicit decision/error checks. | In: bool scd_ok, bool bme_ok, const SensorValues *values Out: AirQualityLevel classification enum. | Pure/local helper; no direct peripheral dependency detected..
AirQuality_Name() main.c:1314–1323 Active | Converts an AirQualityLevel enum into the short label shown on the display. | In: AirQualityLevel level Out: Pointer to a static/received text value; ownership is not transferred. | Pure/local helper; no direct peripheral dependency detected..
AirQuality_Explanation() main.c:1327–1354 Active | Selects the user-facing ventilation or sensor-status explanation for the current air-quality state. The implementation contains 1 explicit decision/error check. | In: AirQualityLevel level, const SensorValues *values Out: Pointer to a static/received text value; ownership is not transferred. | Pure/local helper; no direct peripheral dependency detected..
AirQuality_Colour() main.c:1357–1366 Active | Maps each air-quality state to its palette colour. | In: AirQualityLevel level Out: Returns a numeric result of type uint16_t. | Pure/local helper; no direct peripheral dependency detected..
SystemAlarm_Evaluate() main.c:1373–1465 Active | Applies alarm priority and thresholds to flame, sensor-health, CO₂, temperature, humidity, pressure and gas state, returning an alarm type plus buzzer pattern. The implementation contains 13 explicit decision/error checks. | In: bool measurements_ready, bool scd_healthy, bool bme_healthy, bool flame_sensor_healthy, const SensorValues *values Out: SystemAlarm containing the selected alarm type and buzzer pattern. | Uses: buzzer GPIO.
Buzzer_Update() main.c:1468–1496 Active | Runs the non-blocking buzzer state machine and drives the GPIO according to off, warning or critical cadence. It coordinates HAL_GPIO_WritePin(). | In: BuzzerPattern pattern, uint32_t now Out: No return value; the function acts through hardware, buffers or state. | Calls: HAL_GPIO_WritePin(); Uses: buzzer GPIO.

## 2.8 ESP-01 and HTTP transport

9 functions in this subsystem.

Function | What it does / how it works | Interface | Dependencies
ESP01_SendCommand() main.c:2887–2939 Active | Flushes stale UART bytes, sends an AT command to USART1 and collects the response until timeout while monitoring flame safety. It coordinates HAL_UART_Receive(), HAL_UART_Transmit(), HAL_GetTick(), Safety_FlameActiveDuringNetwork(). The implementation contains 5 explicit decision/error checks and 2 loops. | In: const char *command, char *response, uint16_t capacity, uint32_t timeout_ms Out: Returns a numeric result of type uint16_t. | Calls: HAL_UART_Receive(), HAL_UART_Transmit(), HAL_GetTick(), Safety_FlameActiveDuringNetwork(); Uses: USART1/ESP-01.
ESP01_TestScreen() main.c:2941–3015 Active | Resets/probes the ESP-01 and confirms that its AT firmware responds before Wi-Fi setup proceeds. It coordinates HAL_Delay(), HAL_UART_Init(), ESP01_SendCommand(), LCD_ClearTextLayer(), LCD_DrawString(), HAL_UART_Transmit(). The implementation contains 3 explicit decision/error checks and 1 loop. | In: None. Out: true when the operation/result is valid; false on unavailable data, validation failure or I/O error. | Calls: HAL_Delay(), HAL_UART_Init(), ESP01_SendCommand(), LCD_ClearTextLayer(), LCD_DrawString(), HAL_UART_Transmit(), LCD_PresentTextLayer(); Uses: USART1/ESP-01, USART3 debug.
ESP01_ConnectWiFi() main.c:3017–3167 Active | Configures station mode, joins the configured access point and verifies that the module obtained an IP connection. It coordinates ESP01_SendCommand(), LCD_ShowStatus(), HAL_UART_Transmit(), LCD_ClearTextLayer(), LCD_DrawString(), LCD_PresentTextLayer(). The implementation contains 6 explicit decision/error checks. | In: None. Out: true when the operation/result is valid; false on unavailable data, validation failure or I/O error. | Calls: ESP01_SendCommand(), LCD_ShowStatus(), HAL_UART_Transmit(), LCD_ClearTextLayer(), LCD_DrawString(), LCD_PresentTextLayer(); Uses: USART3 debug.
ESP01_ReadUntil() main.c:3173–3212 Active | Receives USART1 bytes into a bounded buffer until success text, failure text, safety abort or timeout occurs. It coordinates HAL_GetTick(), Safety_FlameActiveDuringNetwork(), HAL_UART_Receive(). The implementation contains 5 explicit decision/error checks and 1 loop. | In: char *response, uint16_t capacity, const char *success, const char *failure, uint32_t timeout_ms Out: Returns a numeric result of type uint16_t. | Calls: HAL_GetTick(), Safety_FlameActiveDuringNetwork(), HAL_UART_Receive(); Uses: USART1/ESP-01.
ESP01_PrepareDataSend() main.c:3215–3270 Active | Opens the ESP AT send prompt for an exact HTTP payload length and verifies the prompt before transmission. It coordinates HAL_UART_Receive(), HAL_UART_Transmit(), ESP01_ReadUntil(). The implementation contains 2 explicit decision/error checks and 1 loop. | In: uint16_t data_length Out: true when the operation/result is valid; false on unavailable data, validation failure or I/O error. | Calls: HAL_UART_Receive(), HAL_UART_Transmit(), ESP01_ReadUntil(); Uses: USART1/ESP-01, USART3 debug.
Text_ContainsInsensitive() main.c:3278–3300 Active | Performs a case-insensitive substring test without changing either input string. The implementation contains 2 explicit decision/error checks and 2 loops. | In: const char *text, const char *word Out: true when the requested text is found; otherwise false. | Pure/local helper; no direct peripheral dependency detected..
Text_ToDisplayUpper() main.c:3305–3344 Active | Copies text into a bounded display buffer while converting letters to uppercase and replacing unsupported characters. The implementation contains 5 explicit decision/error checks and 2 loops. | In: char *destination, size_t capacity, const char *source Out: No return value; the function acts through hardware, buffers or state. | Pure/local helper; no direct peripheral dependency detected..
ESP01_HTTPGet() main.c:3351–3464 Active | Opens a TCP socket, sends one HTTP/1.1 GET request, captures the modem/HTTP response and accepts only a successful status. It coordinates ESP01_SendCommand(), HAL_Delay(), ESP01_PrepareDataSend(), HAL_UART_Transmit(), ESP01_ReadUntil(). The implementation contains 7 explicit decision/error checks. | In: const char *host, const char *path, char *response, uint16_t response_capacity, uint32_t timeout_ms Out: true when the operation/result is valid; false on unavailable data, validation failure or I/O error. | Calls: ESP01_SendCommand(), HAL_Delay(), ESP01_PrepareDataSend(), HAL_UART_Transmit(), ESP01_ReadUntil(); Uses: USART1/ESP-01, USART3 debug.
HTTP_Body() main.c:3467–3488 Active | Returns the first byte after the HTTP header separator, or the original pointer when no separator exists. The implementation contains 4 explicit decision/error checks. | In: const char *response Out: Pointer to a static/received text value; ownership is not transferred. | Pure/local helper; no direct peripheral dependency detected..

## 2.9 Location, time and weather

16 functions in this subsystem.

Function | What it does / how it works | Interface | Dependencies
Date_MonthNumber() main.c:3491–3505 Active | Converts a three-letter HTTP month name into month number 1–12. The implementation contains 1 explicit decision/error check and 1 loop. | In: const char *month Out: Returns a numeric result of type int32_t. | Pure/local helper; no direct peripheral dependency detected..
Date_DaysFromCivil() main.c:3510–3522 Active | Converts a Gregorian date to a day count relative to the Unix epoch using an integer civil-date algorithm. | In: int32_t year, uint32_t month, uint32_t day Out: Returns a numeric result of type int64_t. | Pure/local helper; no direct peripheral dependency detected..
Clock_SyncFromHTTPDate() main.c:3526–3579 Active | Parses an HTTP Date header, converts it to UTC epoch seconds and stores the local clock synchronization reference. It coordinates Date_MonthNumber(), Date_DaysFromCivil(), HAL_GetTick(). The implementation contains 5 explicit decision/error checks. | In: InternetWeather *weather, const char *response Out: true when the operation/result is valid; false on unavailable data, validation failure or I/O error. | Calls: Date_MonthNumber(), Date_DaysFromCivil(), HAL_GetTick().
Clock_LocalEpoch() main.c:3582–3597 Active | Advances the last synchronized UTC epoch by HAL tick elapsed time and applies the geolocated UTC offset. It coordinates HAL_GetTick(). The implementation contains 2 explicit decision/error checks. | In: const InternetWeather *weather Out: Returns a numeric result of type uint32_t. | Calls: HAL_GetTick().
Clock_CivilFromDays() main.c:3603–3625 Active | Converts an epoch day count back into Gregorian year, month and day. | In: int64_t days, int32_t *year, uint32_t *month, uint32_t *day Out: No return value; the function acts through hardware, buffers or state. | Pure/local helper; no direct peripheral dependency detected..
Clock_Format() main.c:3633–3678 Active | Produces display-ready local time/date strings and optionally returns the current minute of day. It coordinates Clock_LocalEpoch(), Clock_CivilFromDays(). The implementation contains 5 explicit decision/error checks. | In: const InternetWeather *weather, char *time_text, size_t time_capacity, char *date_text, size_t date_capacity, uint16_t *minutes_today Out: No return value; the function acts through hardware, buffers or state. | Calls: Clock_LocalEpoch(), Clock_CivilFromDays().
JSON_CopyValue() main.c:3684–3729 Active | Copies a simple quoted or scalar JSON value associated with a key into a bounded destination buffer. The implementation contains 5 explicit decision/error checks and 2 loops. | In: const char *json, const char *key, char *destination, size_t capacity Out: true when the operation/result is valid; false on unavailable data, validation failure or I/O error. | Pure/local helper; no direct peripheral dependency detected..
Location_Fetch() main.c:3732–3789 Active | Queries ip-api.com, parses city/coordinates/time-zone offset and synchronizes the clock from the HTTP response date. It coordinates ESP01_HTTPGet(), HTTP_Body(), JSON_CopyValue(), Text_ToDisplayUpper(), Clock_SyncFromHTTPDate(). The implementation contains 4 explicit decision/error checks. | In: InternetWeather *weather Out: true when the operation/result is valid; false on unavailable data, validation failure or I/O error. | Calls: ESP01_HTTPGet(), HTTP_Body(), JSON_CopyValue(), Text_ToDisplayUpper(), Clock_SyncFromHTTPDate().
Weather_JSONValueStart() main.c:3793–3824 Active | Finds the start of a named JSON value within a selected Open-Meteo response section. The implementation contains 3 explicit decision/error checks and 2 loops. | In: const char *section, const char *key Out: Pointer to a static/received text value; ownership is not transferred. | Pure/local helper; no direct peripheral dependency detected..
Weather_JSONRoundedInteger() main.c:3830–3855 Active | Parses one JSON number and rounds it to a signed 16-bit integer. It coordinates Weather_JSONValueStart(). The implementation contains 4 explicit decision/error checks. | In: const char *section, const char *key, int16_t *result Out: true when the operation/result is valid; false on unavailable data, validation failure or I/O error. | Calls: Weather_JSONValueStart().
Weather_JSONFirstString() main.c:3861–3884 Active | Copies the first string element of a JSON array into a bounded destination. It coordinates Weather_JSONValueStart(). The implementation contains 4 explicit decision/error checks. | In: const char *section, const char *key, char *destination, size_t capacity Out: true when the operation/result is valid; false on unavailable data, validation failure or I/O error. | Calls: Weather_JSONValueStart().
Weather_ParseMinutes() main.c:3887–3909 Active | Converts an ISO time ending in HH:MM into minutes after midnight. It coordinates Text_ContainsInsensitive(). The implementation contains 4 explicit decision/error checks. | In: const char *text Out: Returns a numeric result of type uint16_t. | Calls: Text_ContainsInsensitive().
Weather_SelectTheme() main.c:3912–4000 Active | Chooses clear-day, dawn, sunset, night, cloudy, rain, storm or snow background based on weather code and local time. It coordinates Text_ContainsInsensitive(), Clock_Format(). The implementation contains 11 explicit decision/error checks. | In: InternetWeather *weather Out: No return value; the function acts through hardware, buffers or state. | Calls: Text_ContainsInsensitive(), Clock_Format().
Weather_WMODescription() main.c:4003–4028 Active | Maps a WMO weather code and day/night flag to a short human-readable condition. The implementation contains 11 explicit decision/error checks. | In: uint16_t code, bool is_day Out: Pointer to a static/received text value; ownership is not transferred. | Pure/local helper; no direct peripheral dependency detected..
Weather_ParseOpenMeteo() main.c:4032–4120 Active | Extracts current temperature, apparent temperature, min/max, weather code, sunrise/sunset and update time from Open-Meteo JSON. It coordinates Weather_JSONRoundedInteger(), Weather_JSONFirstString(), Weather_WMODescription(), Weather_ParseMinutes(), HAL_GetTick(), Weather_SelectTheme(). The implementation contains 5 explicit decision/error checks. | In: InternetWeather *weather, const char *body Out: true when the operation/result is valid; false on unavailable data, validation failure or I/O error. | Calls: Weather_JSONRoundedInteger(), Weather_JSONFirstString(), Weather_WMODescription(), Weather_ParseMinutes(), HAL_GetTick(), Weather_SelectTheme().
Weather_Fetch() main.c:4123–4159 Active | Builds the Open-Meteo request from detected coordinates, performs HTTP GET, parses the response and updates validity/theme timestamps. It coordinates ESP01_HTTPGet(), Clock_SyncFromHTTPDate(), HTTP_Body(), Weather_ParseOpenMeteo(). The implementation contains 3 explicit decision/error checks. | In: InternetWeather *weather Out: true when the operation/result is valid; false on unavailable data, validation failure or I/O error. | Calls: ESP01_HTTPGet(), Clock_SyncFromHTTPDate(), HTTP_Body(), Weather_ParseOpenMeteo().

## 2.10 Blynk telemetry and formatting

5 functions in this subsystem.

Function | What it does / how it works | Interface | Dependencies
Blynk_UpdateVirtualPin() main.c:4367–4702 Active | Sends one value to one Blynk virtual pin through a plain-HTTP API request and validates the HTTP response. It coordinates LCD_ShowStatus(), HAL_Delay(), ESP01_SendCommand(), HAL_UART_Transmit(), ESP01_PrepareDataSend(), ESP01_ReadUntil(). The implementation contains 15 explicit decision/error checks. | In: uint8_t virtual_pin, const char *value Out: true when the operation/result is valid; false on unavailable data, validation failure or I/O error. | Calls: LCD_ShowStatus(), HAL_Delay(), ESP01_SendCommand(), HAL_UART_Transmit(), ESP01_PrepareDataSend(), ESP01_ReadUntil(); Uses: USART1/ESP-01, USART3 debug.
BufferAppend() main.c:4708–4735 Active | Bounds-checks and appends formatted text to a shared request buffer using vsnprintf. The implementation contains 2 explicit decision/error checks. | In: char *buffer, size_t capacity, size_t *used, const char *format, ... Out: true when the operation/result is valid; false on unavailable data, validation failure or I/O error. | Pure/local helper; no direct peripheral dependency detected..
FormatSignedTenthsValue() main.c:4740–4757 Active | Converts a signed fixed-point tenths value into a compact decimal string. The implementation contains 2 explicit decision/error checks. | In: char *buffer, size_t capacity, int32_t value10 Out: No return value; the function acts through hardware, buffers or state. | Pure/local helper; no direct peripheral dependency detected..
FormatUnsignedTenthsValue() main.c:4762–4771 Active | Converts an unsigned fixed-point tenths value into a compact decimal string. The implementation contains 1 explicit decision/error check. | In: char *buffer, size_t capacity, uint32_t value10 Out: No return value; the function acts through hardware, buffers or state. | Pure/local helper; no direct peripheral dependency detected..
Blynk_UpdateAllMeasurements() main.c:4778–5028 Active | Formats all current readings and transmits them in one batched Blynk HTTP update to reduce socket overhead. It coordinates BufferAppend(), FormatSignedTenthsValue(), FormatUnsignedTenthsValue(), ESP01_SendCommand(), HAL_Delay(), ESP01_PrepareDataSend(). The implementation contains 20 explicit decision/error checks. | In: bool scd_ok, bool bme_ok, bool flame_adc_ok, const SensorValues *values, const InternetWeather *weather Out: true when the operation/result is valid; false on unavailable data, validation failure or I/O error. | Calls: BufferAppend(), FormatSignedTenthsValue(), FormatUnsignedTenthsValue(), ESP01_SendCommand(), HAL_Delay(), ESP01_PrepareDataSend(), HAL_UART_Transmit(), ESP01_ReadUntil(); Uses: USART1/ESP-01, USART3 debug.

3 Critical-function walkthroughs

The execution paths that are most important for debugging and future modification

### 1. main() — Cooperative application scheduler

int main(void)

Initializes memory, peripherals, sensors and Wi-Fi, then runs the cooperative scheduler for sampling, alarms, GUI, weather and Blynk uploads.

1. Configures MPU and clocks, initializes all CubeMX peripherals, starts SDRAM, validates/maps QSPI assets, and only then enables the LTDC GUI.

2. Initializes SCD41, BME688 and ESP-01; when Wi-Fi is available it performs location detection followed by the first weather request.

3. Samples flame every 200 ms and environmental sensors every 5 s, maintaining health counters and retrying disconnected I²C sensors.

4. Evaluates alarms and services the buzzer before any network work, refreshes the display every 500 ms, and serializes location/weather/Blynk requests so only one blocking request happens at a time.

5. Uses HAL_GetTick subtraction for wrap-safe timing and finishes each loop with a short 10 ms delay.

IMPLEMENTATION NOTE

The design is intentionally cooperative rather than RTOS-based. Any new network operation must preserve flame checks and must not add long unmonitored blocking delays.

### 2. SDRAM_Startup() — IS42S16400J power-up sequence

static HAL_StatusTypeDef SDRAM_Startup(void)

Sends the JEDEC SDRAM power-up command sequence and programs the proven 66.7 MHz refresh count.

1. Send CLOCK ENABLE to SDRAM Bank 1.

2. Wait at least 100 µs (implemented conservatively as 1 ms).

3. Precharge all banks, then issue eight auto-refresh cycles.

4. Load burst-length 1, sequential burst, CAS 3 and single-write-burst mode.

5. Program refresh count 1022 for FMC SDCLK ≈66.7 MHz and 4096 rows.

IMPLEMENTATION NOTE

Nothing may access 0xC0000000 before this function returns HAL_OK.

### 3. QSPI_Assets_Init() — Persistent asset-store boot path

HAL_StatusTypeDef QSPI_Assets_Init(QSPI_HandleTypeDef *hqspi, bool *installed_now)

Resets and identifies the flash, enables quad mode, installs assets when requested, validates CRCs and enters memory-mapped mode.

1. Validate the HAL handle, reset the W25Q128 and read JEDEC ID EF 40 18.

2. Enable quad mode and read the versioned asset header.

3. When the installer build is enabled and sources differ, erase/program/verify the asset region once.

4. Validate header geometry and CRCs, then enter memory-mapped quad-read mode at 0x90000000.

IMPLEMENTATION NOTE

After a successful one-time installation, QSPI_ASSET_INSTALLER should be set to 0 and the large generated source arrays excluded from normal firmware builds.

### 4. LCD_ConfigureTextLayer() — Double-buffer creation

static void LCD_ConfigureTextLayer(void)

Programs the LTDC L8 foreground layer, loads the colour lookup table and prepares both SDRAM framebuffers for double buffering.

1. Assign two 480×272 L8 frames at 0xC0000000 and 0xC0040000.

2. Clear both frames and load the 256-entry palette from memory-mapped QSPI.

3. Configure LTDC foreground layer format, window and first frame address.

4. Enable double-buffer state so subsequent drawing always targets the non-visible frame.

IMPLEMENTATION NOTE

The SDRAM MPU region is non-cacheable, so CPU writes are immediately visible to LTDC without cache maintenance.

### 5. LCD_PresentTextLayer() — Tear-free frame presentation

static void LCD_PresentTextLayer(void)

Waits for vertical blanking, swaps the front/back SDRAM buffers, updates LTDC layer address, then selects the old front buffer for the next frame.

1. Request LTDC vertical-blank reload and wait for the safe display interval.

2. Swap the software front/back pointers.

3. Program the LTDC layer framebuffer address with the completed back frame.

4. Reload the layer and redirect all later drawing to the old front frame.

IMPLEMENTATION NOTE

All screen composition should finish before this call; presenting repeatedly during drawing would reintroduce flashing or tearing.

### 6. GUI_ShowWeatherDashboard() — Normal dashboard composition

static void GUI_ShowWeatherDashboard(bool scd_ok, bool bme_ok, bool wifi_ok, bool blynk_ok, const SensorValues *values, const InternetWeather *weather)

Builds the normal weather-and-room dashboard from cached sensor, location, weather and network state, then presents one complete frame.

1. Reject null data, format local time/date, and compare current state with cached last state to skip identical frames.

2. Copy the weather-dependent background from QSPI to the SDRAM back frame.

3. Draw location/outside weather and the room temperature, humidity, CO₂, pressure, air-quality explanation and network state using QSPI fonts/icons.

4. Present once, then cache every displayed input so the next call only rebuilds when something changed.

IMPLEMENTATION NOTE

This change-detection plus one-shot buffer swap is the reason live values update without the whole panel visibly flashing.

### 7. SCD41_Read() — CO₂ measurement transaction

static bool SCD41_Read(SensorValues *values)

Reads the SCD41 CO₂, temperature and humidity words, verifies all CRC bytes and updates SensorValues.

1. Check the data-ready command first; return without corrupting prior values if no fresh sample exists.

2. Issue Read Measurement and receive three two-byte words, each followed by its own CRC byte.

3. Reject the complete sample if any CRC fails.

4. Convert raw temperature and humidity with Sensirion formulas and store CO₂ plus tenths-scaled values.

IMPLEMENTATION NOTE

A false return means the caller should keep the last known sample and increment its health counter.

### 8. BME688_Read() — Forced-mode environmental conversion

static bool BME688_Read(SensorValues *values)

Triggers forced mode, waits for conversion, obtains compensated temperature/humidity/pressure/gas values and stores fixed-point results.

1. Set forced mode so one conversion uses the configured oversampling and heater profile.

2. Calculate and wait for the required measurement duration.

3. Read Bosch-compensated field data and accept only a new valid measurement.

4. Convert temperature, humidity, pressure and gas resistance into the integer/fixed-point representation used by the UI and Blynk.

IMPLEMENTATION NOTE

The Bosch BME68x driver performs compensation; this function owns scheduling and project-specific unit conversion.

### 9. GasMonitor_Update() — Adaptive gas-change detector

static void GasMonitor_Update(SensorValues *values)

Learns a clean-air BME688 gas-resistance baseline, calculates the current percentage ratio and applies confirm/clear counters for stable alarms.

1. Accumulate a clean-air resistance average during the warm-up/baseline window.

2. Express each new gas resistance as a percentage of the baseline.

3. Require several consecutive low-ratio samples before asserting the gas alarm.

4. Require several consecutive recovered samples before clearing it, providing hysteresis and noise rejection.

IMPLEMENTATION NOTE

The gas state is monitored in the background and used for alarms/Blynk; it is intentionally not presented as an absolute gas concentration.

### 10. SystemAlarm_Evaluate() — Alarm priority encoder

static SystemAlarm SystemAlarm_Evaluate(bool measurements_ready, bool scd_healthy, bool bme_healthy, bool flame_sensor_healthy, const SensorValues *values)

Applies alarm priority and thresholds to flame, sensor-health, CO₂, temperature, humidity, pressure and gas state, returning an alarm type plus buzzer pattern.

1. Return no alarm until the first scheduled measurement pass is complete.

2. Evaluate flame first, then sensor failures and environmental danger conditions in fixed priority order.

3. Associate each alarm with either critical or warning buzzer cadence.

4. Return the first/highest-priority condition so only one clear instruction is displayed.

IMPLEMENTATION NOTE

Adding a new hazard requires an explicit priority decision; do not simply append it without considering flame and sensor-failure behavior.

### 11. ESP01_HTTPGet() — Reusable plain-HTTP GET transaction

static bool ESP01_HTTPGet(const char *host, const char *path, char *response, uint16_t response_capacity, uint32_t timeout_ms)

Opens a TCP socket, sends one HTTP/1.1 GET request, captures the modem/HTTP response and accepts only a successful status.

1. Close any stale socket and open TCP to the requested host on port 80.

2. Build a bounded HTTP/1.1 request with Host and Connection: close headers.

3. Ask the ESP for an exact send length, transmit immediately after the prompt, then collect the response until CLOSED/ERROR/timeout.

4. Mirror diagnostics to USART3 and accept only HTTP 200.

IMPLEMENTATION NOTE

The current implementation is HTTP, not TLS. Authentication tokens therefore should only be used on a trusted network for this student prototype.

### 12. Weather_Fetch() — Outside-weather update

static bool Weather_Fetch(InternetWeather *weather)

Builds the Open-Meteo request from detected coordinates, performs HTTP GET, parses the response and updates validity/theme timestamps.

1. Require valid geolocation coordinates and build an Open-Meteo path for current/daily values in the detected timezone.

2. Execute ESP01_HTTPGet and synchronize the local clock from the response Date header.

3. Pass the HTTP body to Weather_ParseOpenMeteo; preserve old valid weather if the new response cannot be parsed.

4. On success update validity/timestamp and select the appropriate QSPI theme.

IMPLEMENTATION NOTE

The normal scheduler retries failures after one minute and refreshes successful weather every fifteen minutes.

### 13. Blynk_UpdateAllMeasurements() — Batched cloud upload

static bool Blynk_UpdateAllMeasurements(bool scd_ok, bool bme_ok, bool flame_adc_ok, const SensorValues *values, const InternetWeather *weather)

Formats all current readings and transmits them in one batched Blynk HTTP update to reduce socket overhead.

1. Format all fixed-point sensor/weather values into decimal strings.

2. Build one bounded Blynk batch path containing all virtual-pin assignments.

3. Open one TCP connection and send one HTTP request rather than one connection per measurement.

4. Collect the response and report success only for HTTP 200.

IMPLEMENTATION NOTE

Flame transitions can trigger an immediate batch; normal telemetry is rate-limited to the configured ten-second interval.

4 Modification and debugging guide

Where to make common changes without breaking unrelated subsystems

Goal | Primary function(s) | Do not forget
Change dashboard layout | GUI_ShowWeatherDashboard(), LCD_Draw*(), LCD_DrawIcon() | Compose only in the back buffer and call LCD_PresentTextLayer() once per completed frame.
Change alarm limits | SystemAlarm_Evaluate(), AirQuality_Get() | Keep hysteresis/confirmation for noisy gas readings and preserve flame priority.
Change sample rates | Timing #defines + main() | Use unsigned HAL tick subtraction so wraparound remains safe.
Add a Blynk value | Blynk_UpdateAllMeasurements() | Assign a unique virtual pin and keep request construction bounded through BufferAppend().
Add a weather theme | QSPI_WeatherTheme, Weather_SelectTheme(), asset generator | Increment asset version, reinstall once, then disable installer mode.
Debug I²C | SCD41_Read()/BME688_Read() and USART3 output | Do not replace the live display from background network/sensor diagnostics.
Retest SDRAM | Dedicated SDRAM diagnostic firmware | The retained SDRAM_Test() is destructive and must never run while GUI buffers are live.

## 4.1 Recommended debugging order

1. Confirm the failing subsystem's hardware power and pin configuration before changing code.

2. Use USART3 to capture exact HAL/AT responses; keep the dashboard active for user-facing state only.

3. Verify the producer first (sensor/network parser), then the cached data structure, then the GUI formatter.

4. For display corruption, verify SDRAM startup and QSPI asset CRCs before editing draw coordinates.

5. After any scheduling change, repeat flame detection while a network request is deliberately slow.

RELEASE CHECKLIST

Set Wi-Fi and Blynk credentials outside version control; set QSPI_ASSET_INSTALLER to 0 after successful installation; keep destructive memory tests excluded; compile with warnings enabled; verify sensors, alarms, weather, Blynk and the full 8 MiB SDRAM test before demonstration.

Appendix A Function count and coverage

Subsystem | Total | Active | Conditional
Startup, scheduler and fault handling | 6 | 5 | 1
CubeMX peripheral initialization | 10 | 10 | 0
External memory and QSPI assets | 43 | 27 | 16
Display, drawing and GUI | 30 | 30 | 0
Environmental sensors | 11 | 11 | 0
Flame and gas safety | 5 | 5 | 0
Air-quality and alarm logic | 6 | 6 | 0
ESP-01 and HTTP transport | 9 | 9 | 0
Location, time and weather | 16 | 16 | 0
Blynk telemetry and formatting | 5 | 5 | 0
TOTAL | 141 | 124 | 17

Coverage statement: all C function definitions found by brace-aware parsing of Core/Src/main.c and Core/Src/qspi_assets.c are represented in Section 2. Data-only generated asset modules contain no functions. STM32 HAL and Bosch BME68x library functions are dependencies and are not re-documented here.

Mahmoud Mostafa Code Guide Rev 1.0 · 15 August 2026 Page 1 of 1

SMART HOME HUB | FIRMWARE CODE GUIDE

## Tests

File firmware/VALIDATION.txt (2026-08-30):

Validation completed 2026-08-16

PASS  Restored main.c structural C syntax parse
PASS  MCP2221A console compiled with GCC -Wall -Wextra -Werror
PASS  Host simulation: input "PING" produced the expected "PONG" response
PASS  No direct HAL_UART_Transmit/HAL_UART_Receive calls remain for huart3
PASS  USART1 ESP-01 accesses remain separate from the USART3 console
PASS  C lexical brace-balance check
PASS  Invalid/leftover Markdown escape scan

Important: a complete target link was not possible in this workspace because
the submitted artifact contained main.c rather than the complete CubeIDE
Drivers, main.h, bme68x and QSPI asset sources. Copy the supplied files into the
working HUB_test project, refresh, clean and build there.

SCD41 compensation update
-------------------------
PASS  C-aware delimiter/structure scan
PASS  SCD41 9.3 degC command payload calculation (24 1D 0D 9B 12)
PASS  Host test of offset conversion, CRC and room-temperature IIR filter
PASS  GUI, room alarms and Blynk V4/V5 compensated-field integration checks

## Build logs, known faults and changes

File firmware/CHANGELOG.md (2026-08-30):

# Organized-source changes

## SCD41 room-environment compensation

- Made the SCD41 the authoritative source for displayed room temperature and
  humidity.
- Configured a 9.3 °C SCD41 integration offset at every boot, derived from the
  stabilized 32.3 °C sensor output, a 27.0 °C reference, and the sensor's
  existing 4.0 °C default offset.
- Added light IIR smoothing to the displayed room temperature.
- Changed temperature and humidity alarms to use the compensated SCD41 data.
- Retained the BME688 temperature as a PCB/heater diagnostic; pressure and gas
  measurements still come from the BME688.
- Added the BME-to-room thermal delta to the MCP2221A `SENSORS` report.

## Initial organization and MCP2221A integration

- Converted the supplied Markdown-formatted listing back into valid C source.
- Preserved the working LCD, QSPI, SDRAM, SCD41, BME688, flame, buzzer,
  ESP-01, weather and Blynk application logic.
- Reserved USART1 exclusively for the ESP-01.
- Added `mcp2221a_console.c/.h` for the MCP2221A on USART3.
- Replaced scattered direct USART3 transmissions with one console API.
- Added a startup banner, boot diagnostics and two-way terminal commands.
- Added live `STATUS`, `SENSORS`, `NETWORK` and `MEMORY` reports.
- Moved timing, alarm thresholds and Blynk pin assignments into
  `app_config.h`.
- Moved private credentials into `app_secrets.h` and added a safe example.
- Fixed the malformed `+CIFSR:STAIP` search string and Markdown-escaped
  bitwise-NOT operators found in the submitted listing.
- Documented all required Blynk V0-V16 datastreams.

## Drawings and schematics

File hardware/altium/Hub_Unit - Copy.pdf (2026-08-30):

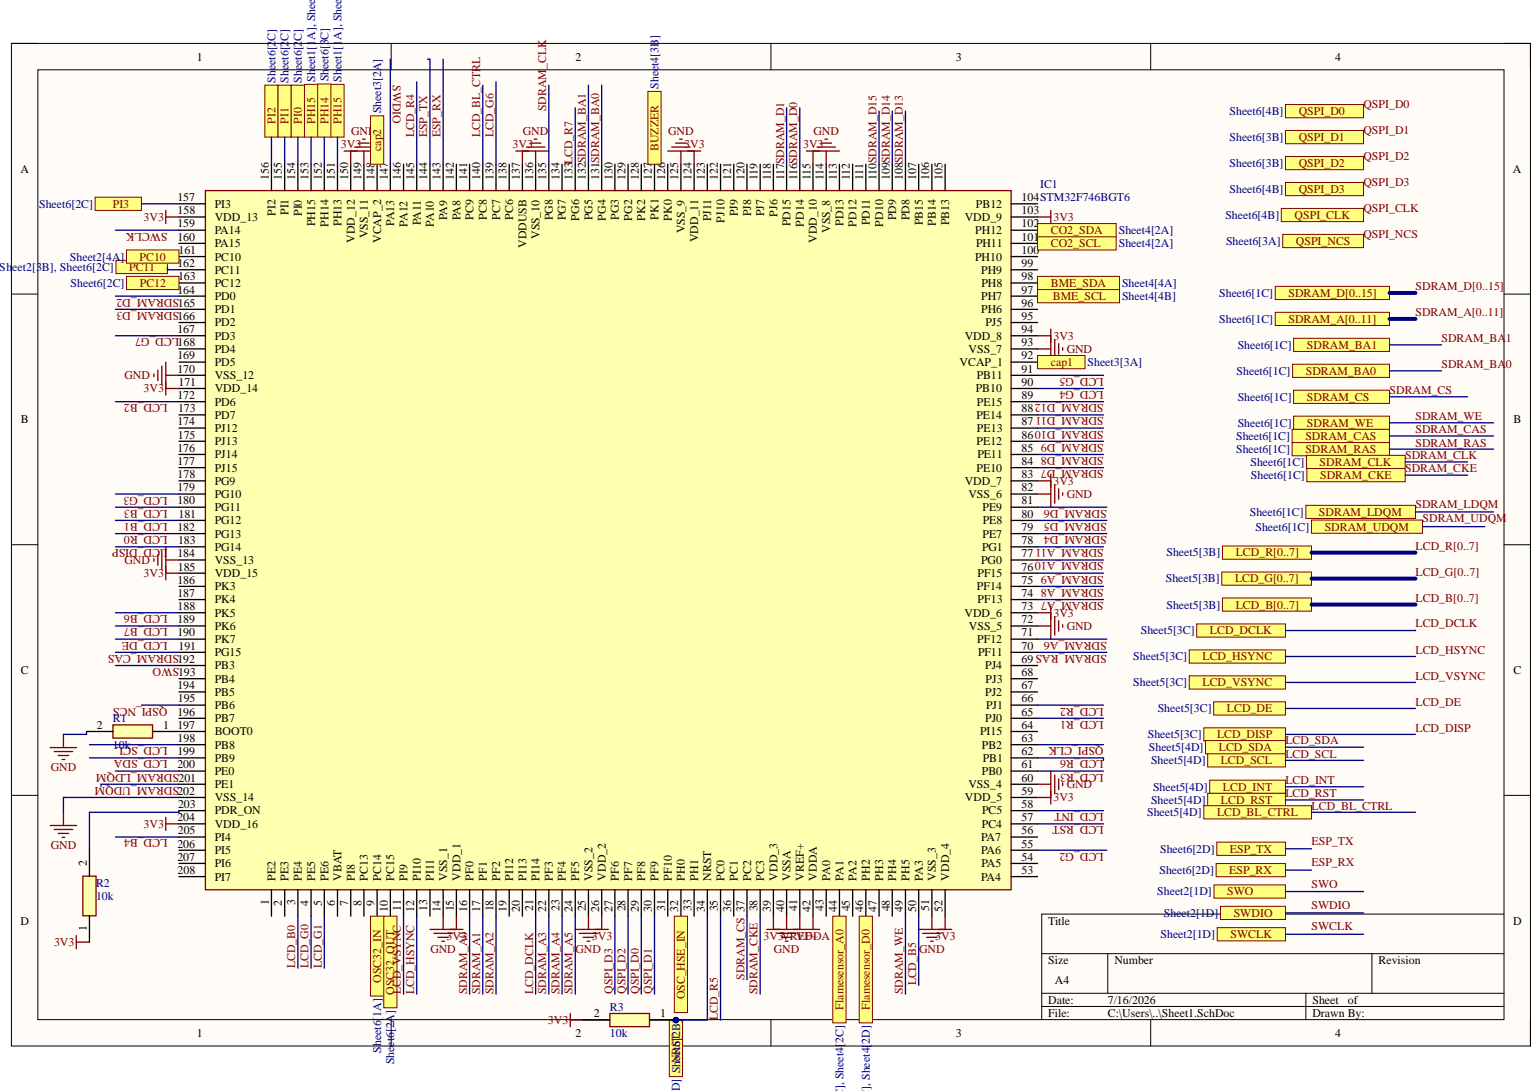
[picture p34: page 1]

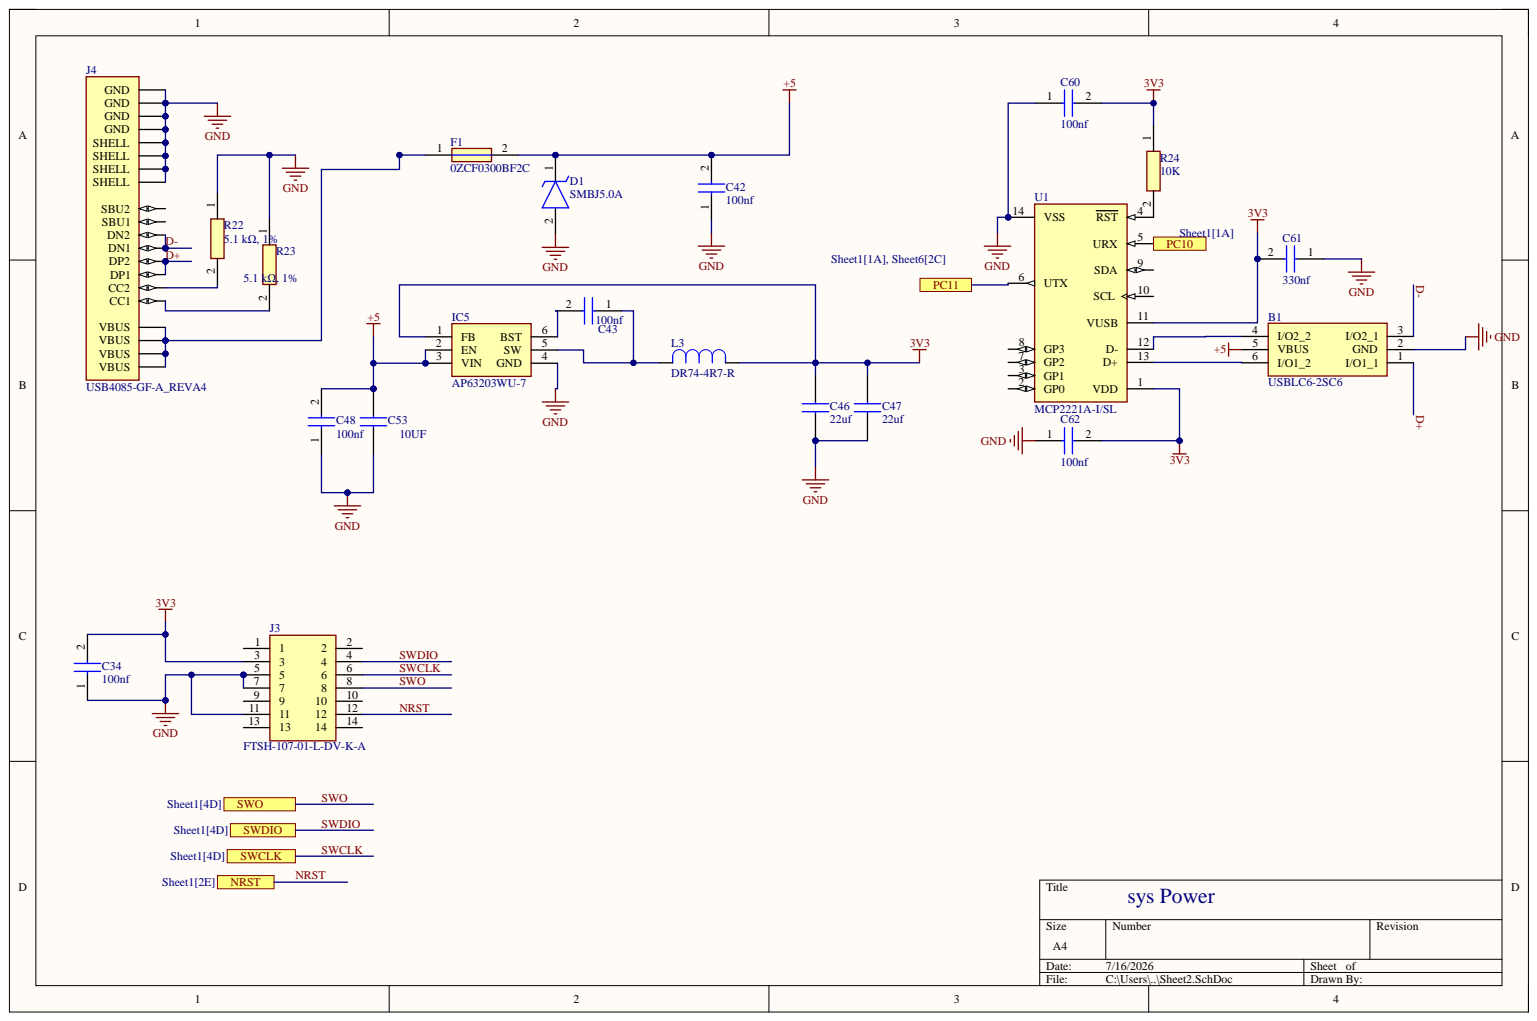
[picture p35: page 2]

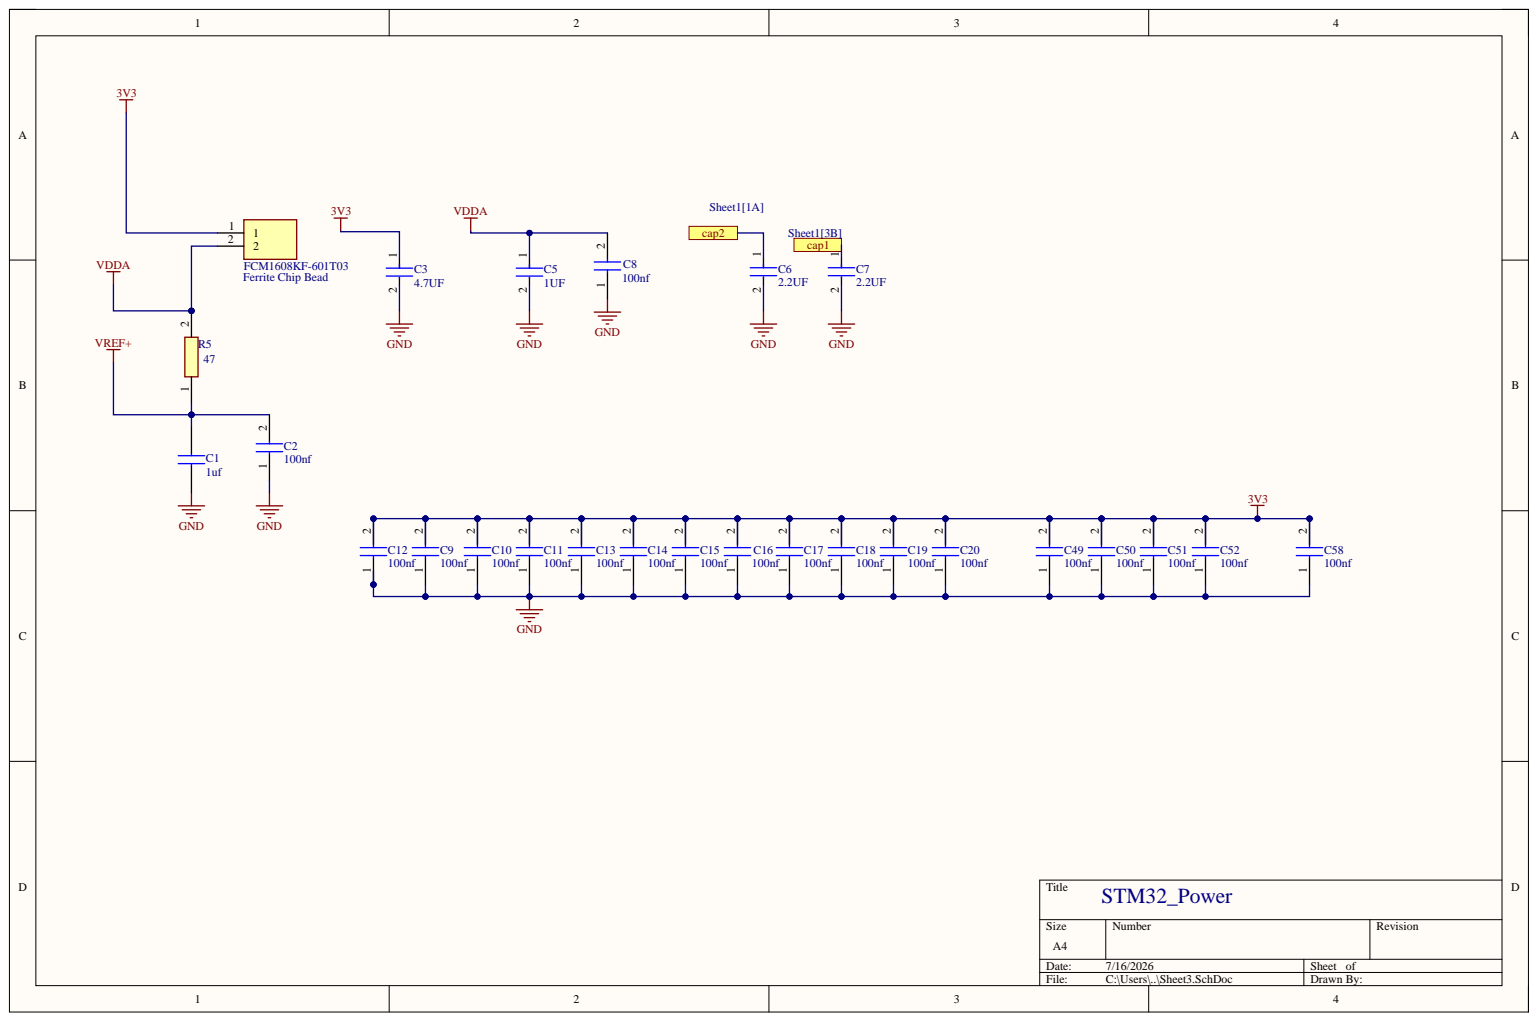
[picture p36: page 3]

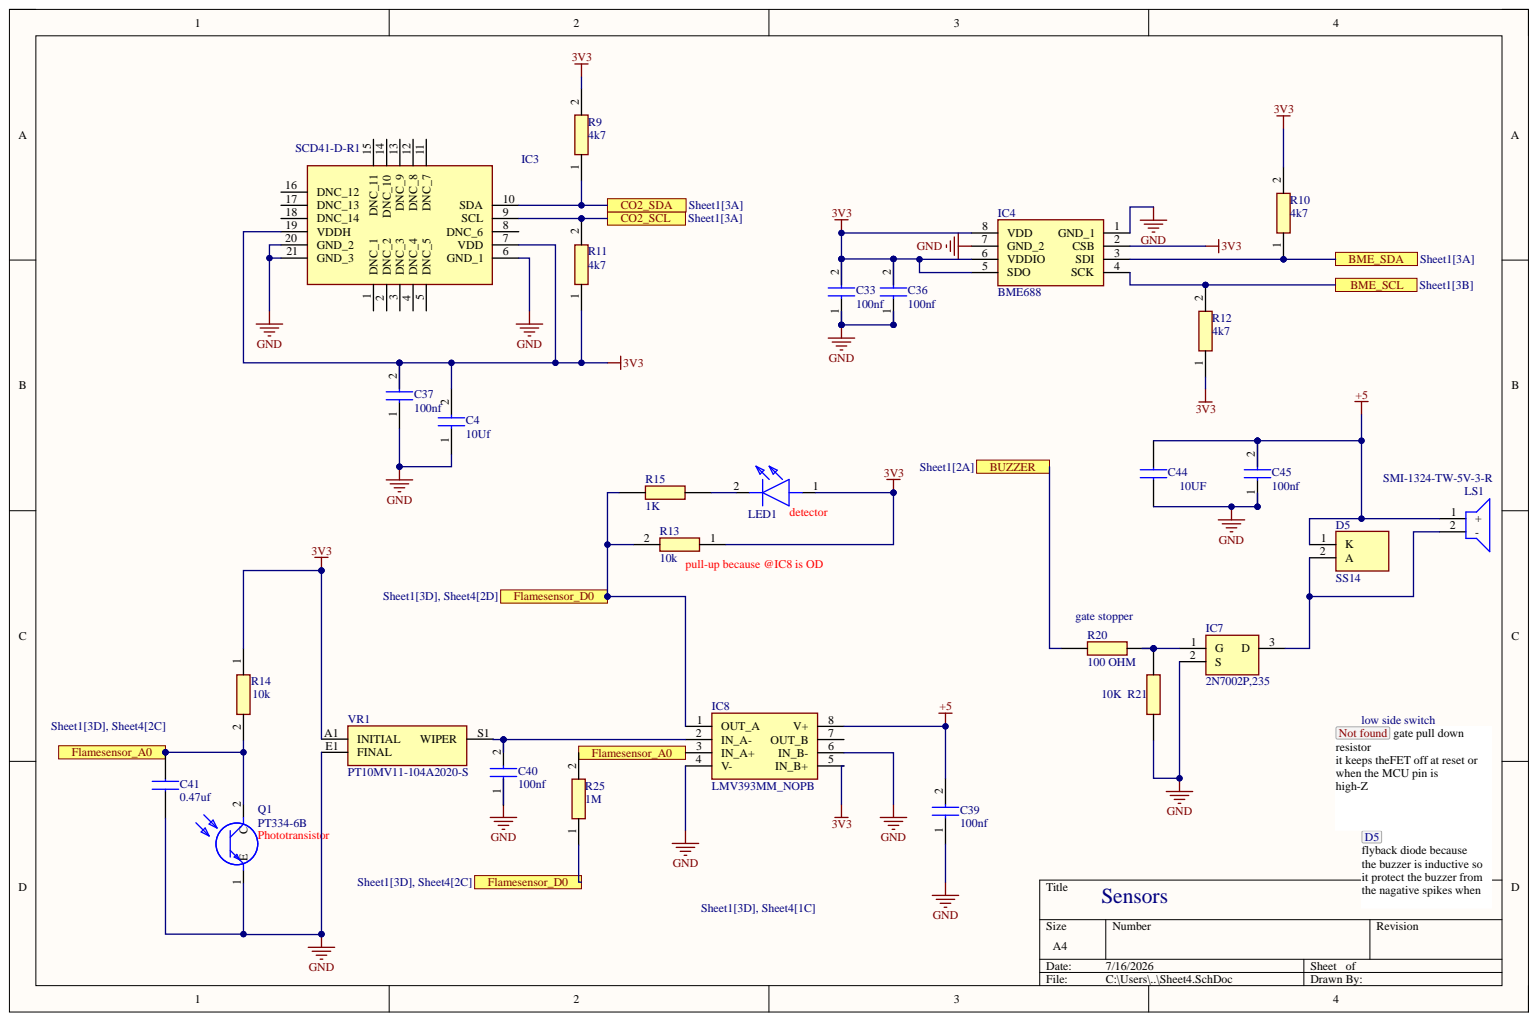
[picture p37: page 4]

D5 | | - 2
K 1

pull-up because @IC8 is OD

low side switch
Not found gate pull down
resistor
it keeps theFET off at reset or
when the MCU pin is
high-Z

flyback diode because
the buzzer is inductive so
it protect the buzzer from
the nagative spikes when

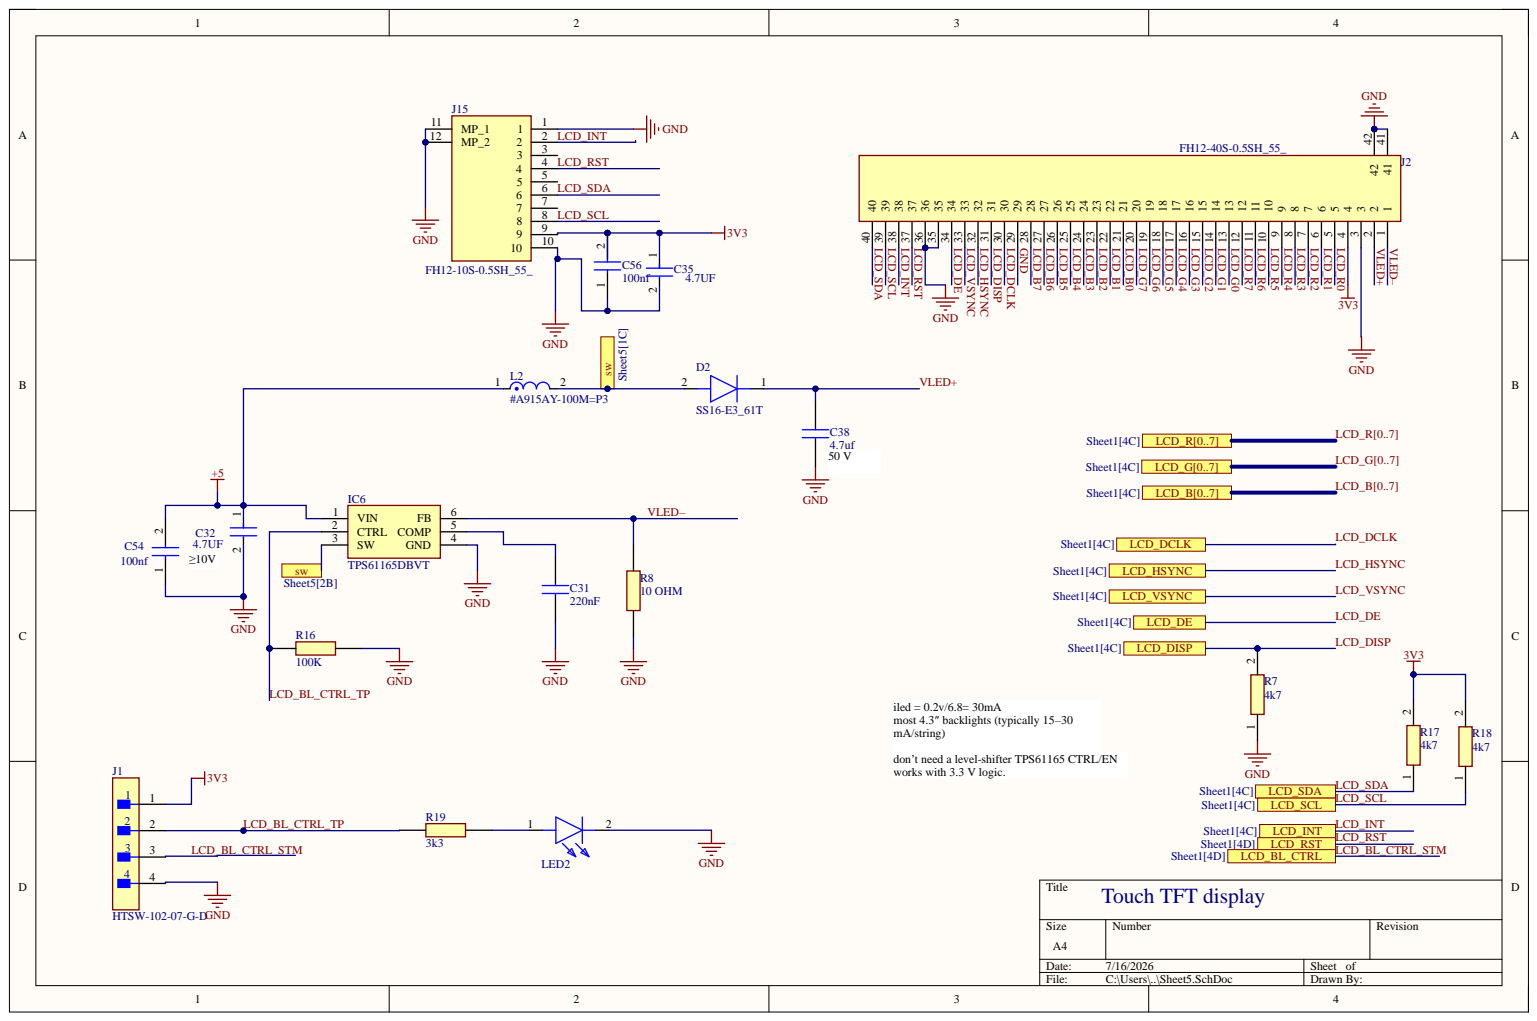
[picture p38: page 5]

don’t need a level-shifter TPS61165 CTRL/EN
works with 3.3 V logic.

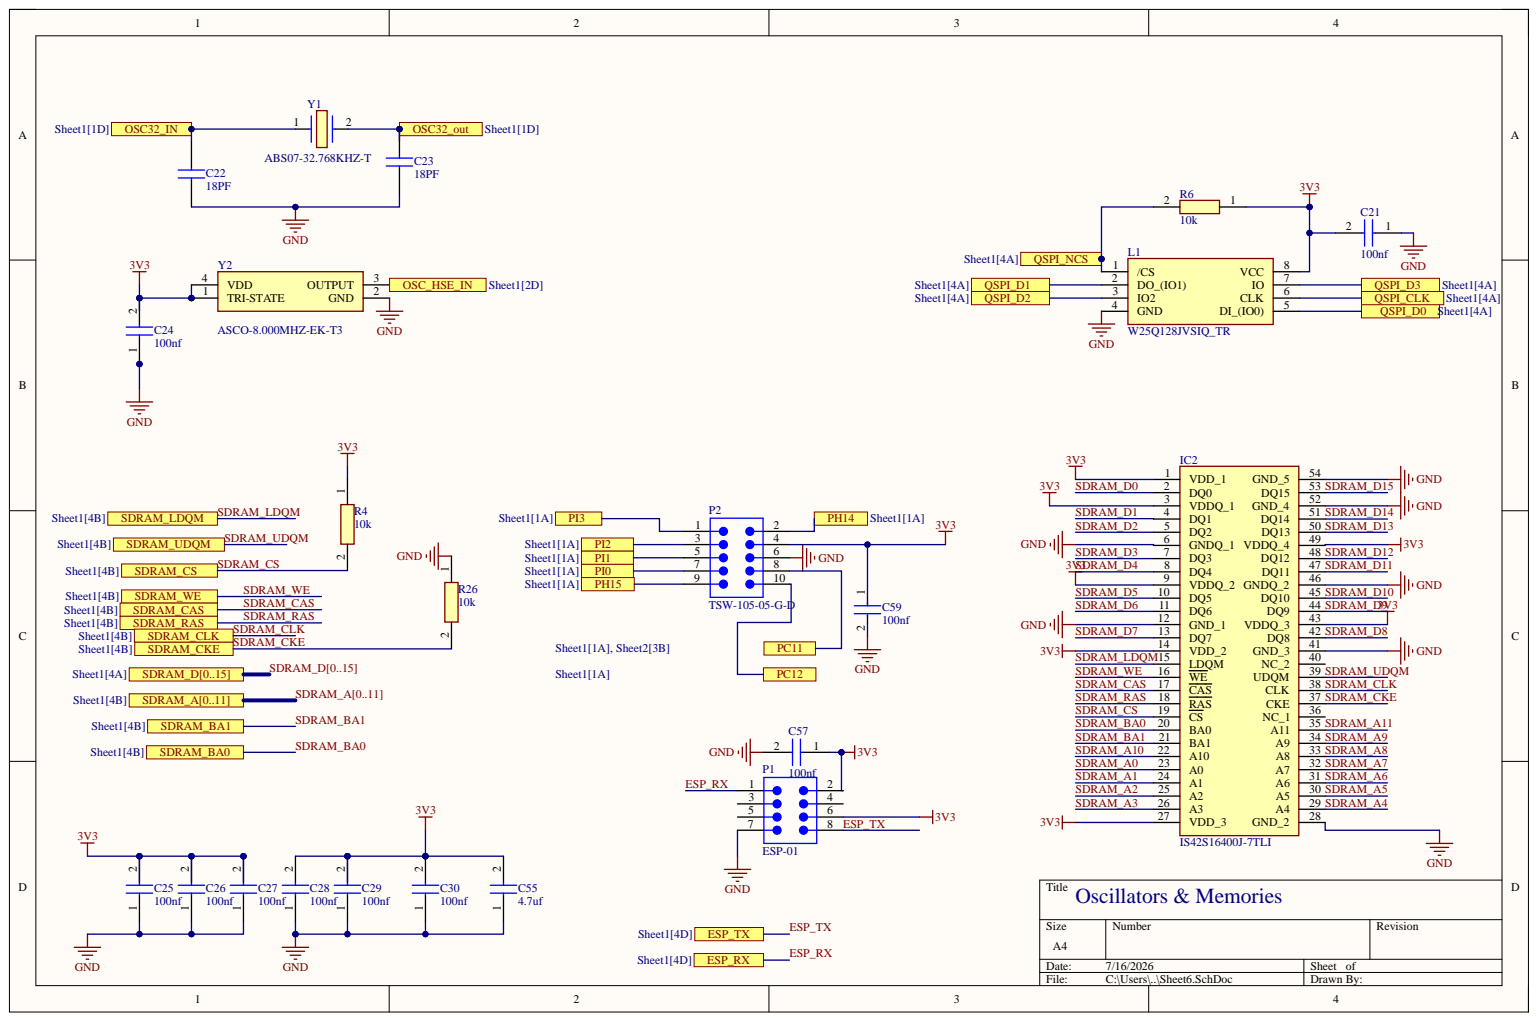
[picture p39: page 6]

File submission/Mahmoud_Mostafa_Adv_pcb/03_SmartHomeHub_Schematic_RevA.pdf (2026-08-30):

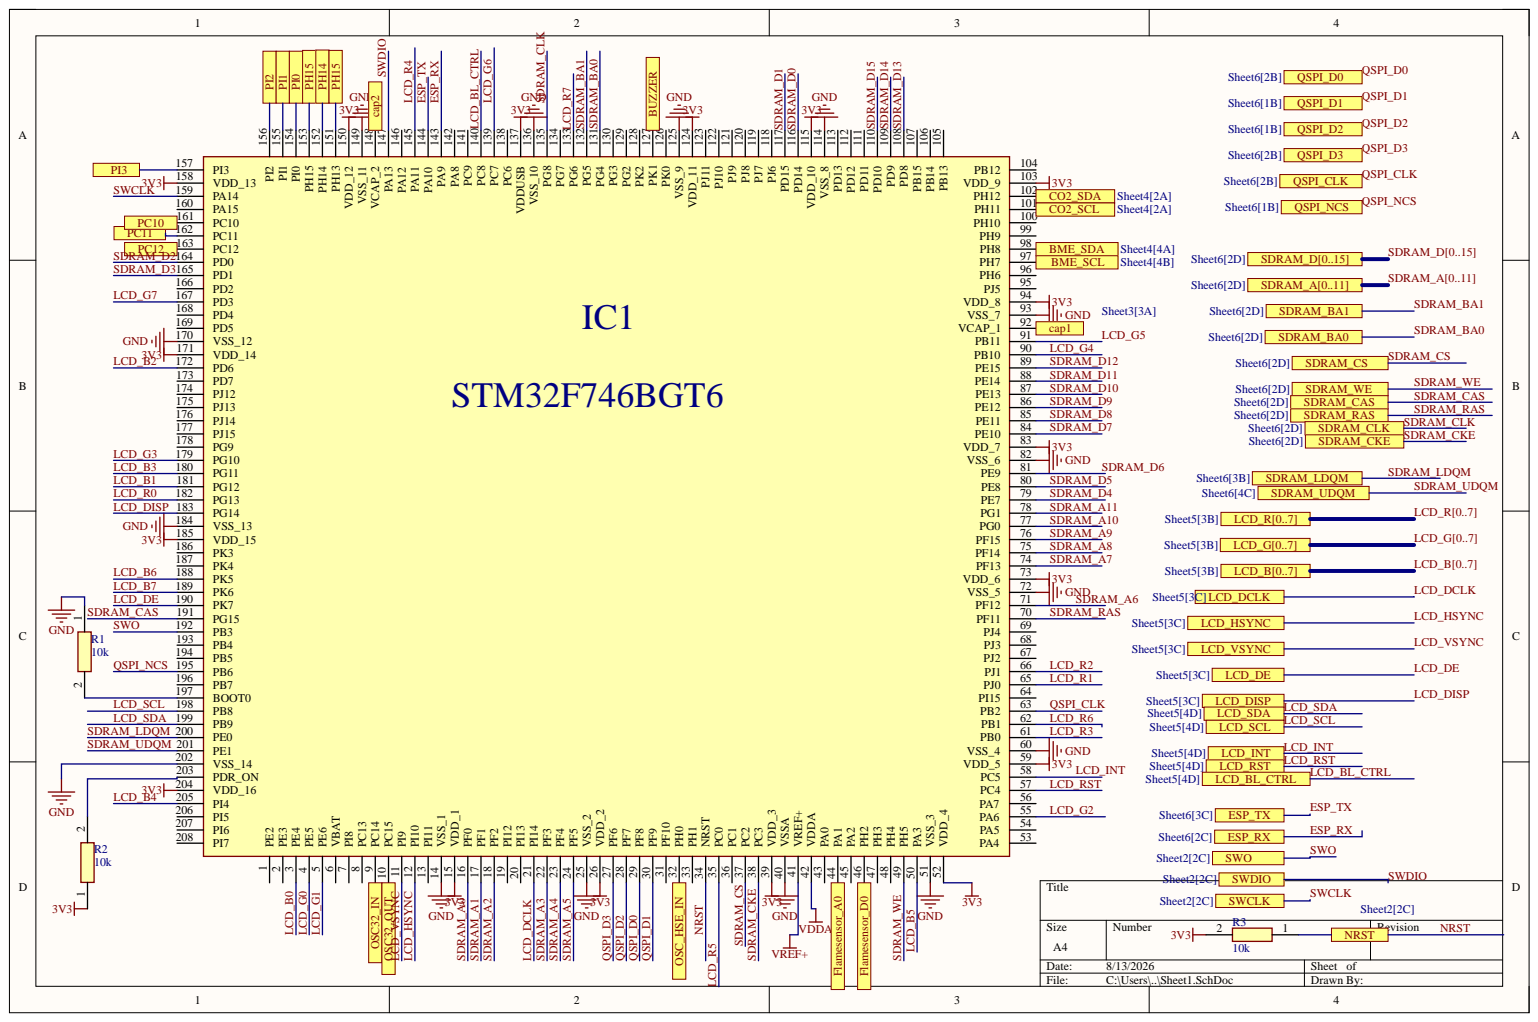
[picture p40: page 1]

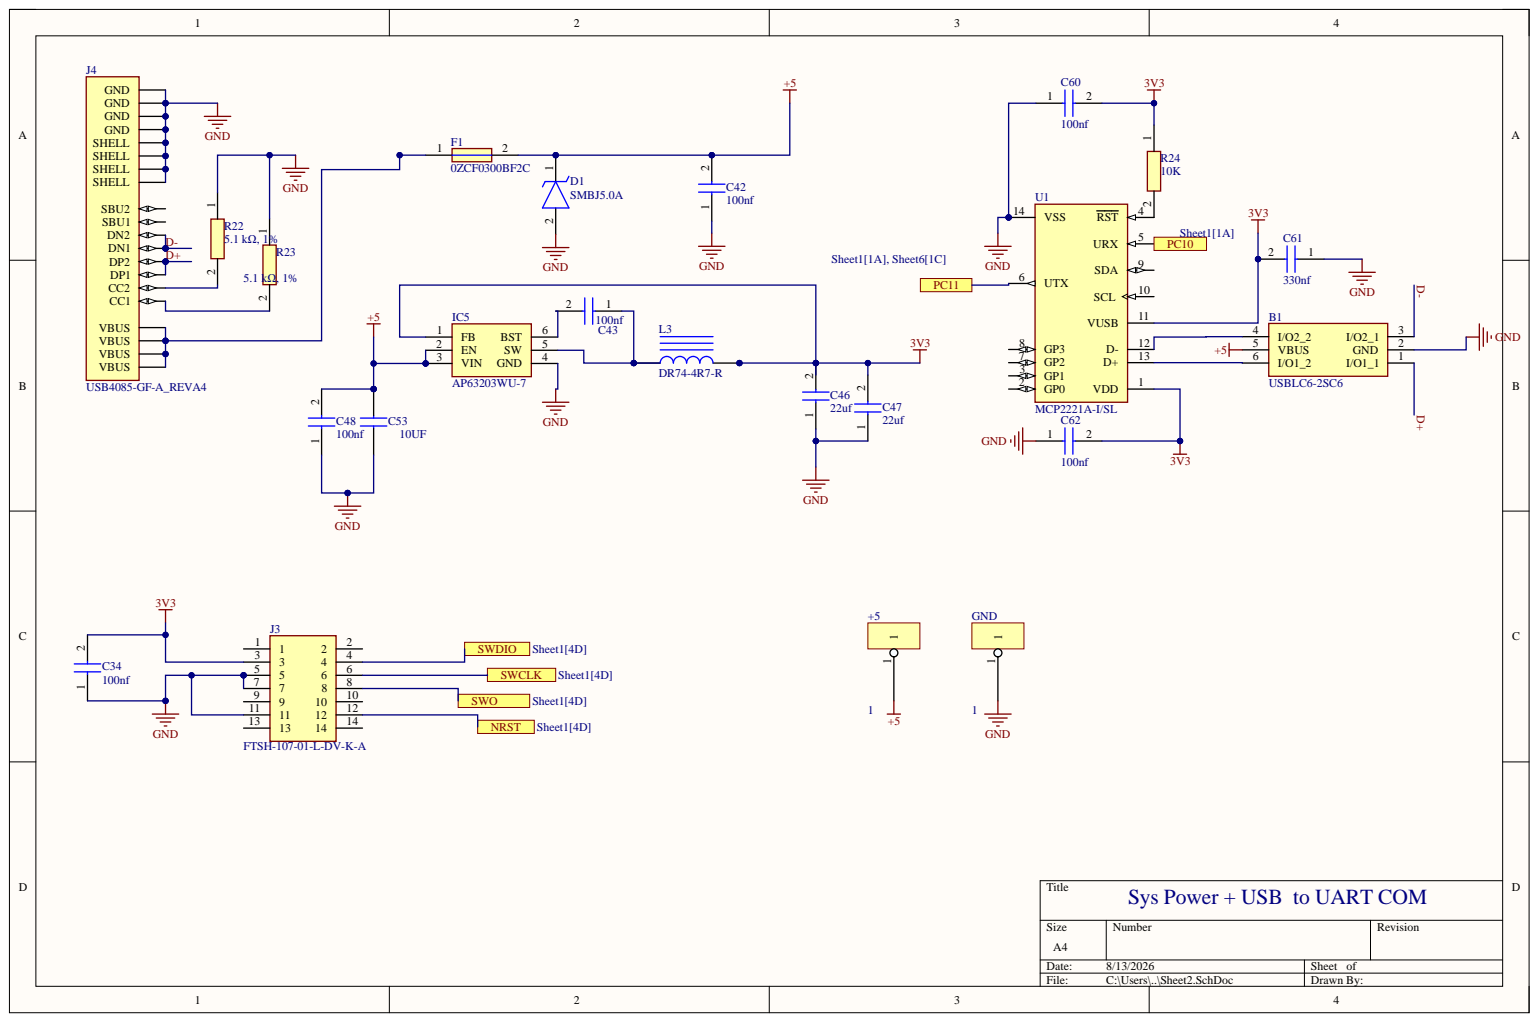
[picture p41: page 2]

Sys Power + USB to UART COM

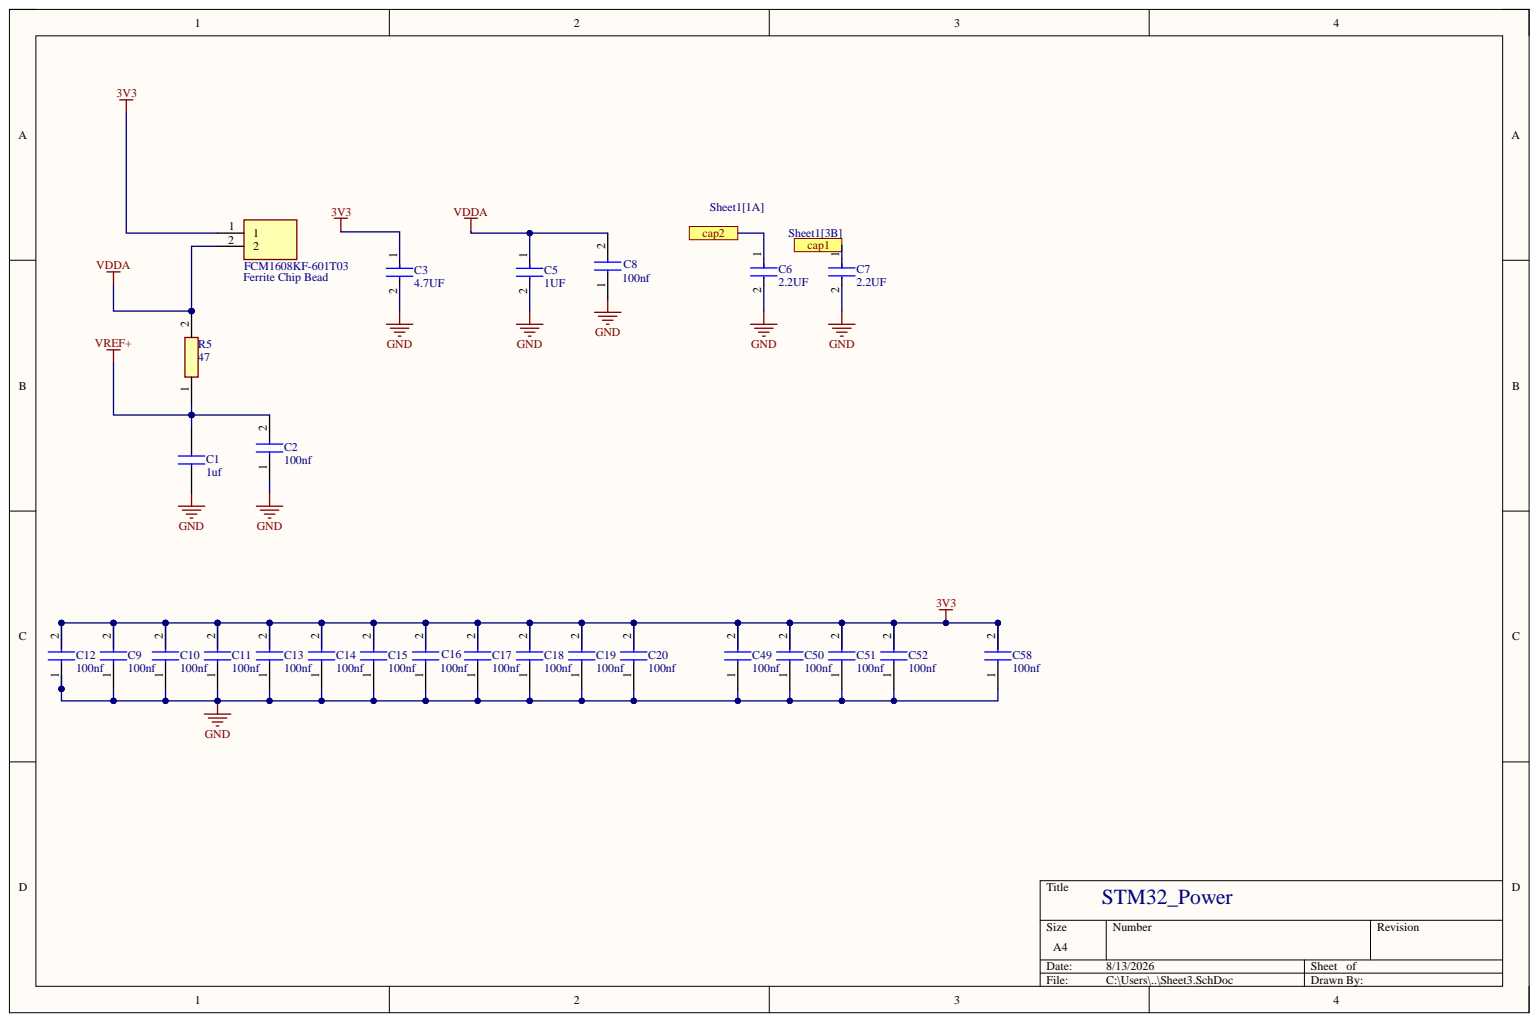
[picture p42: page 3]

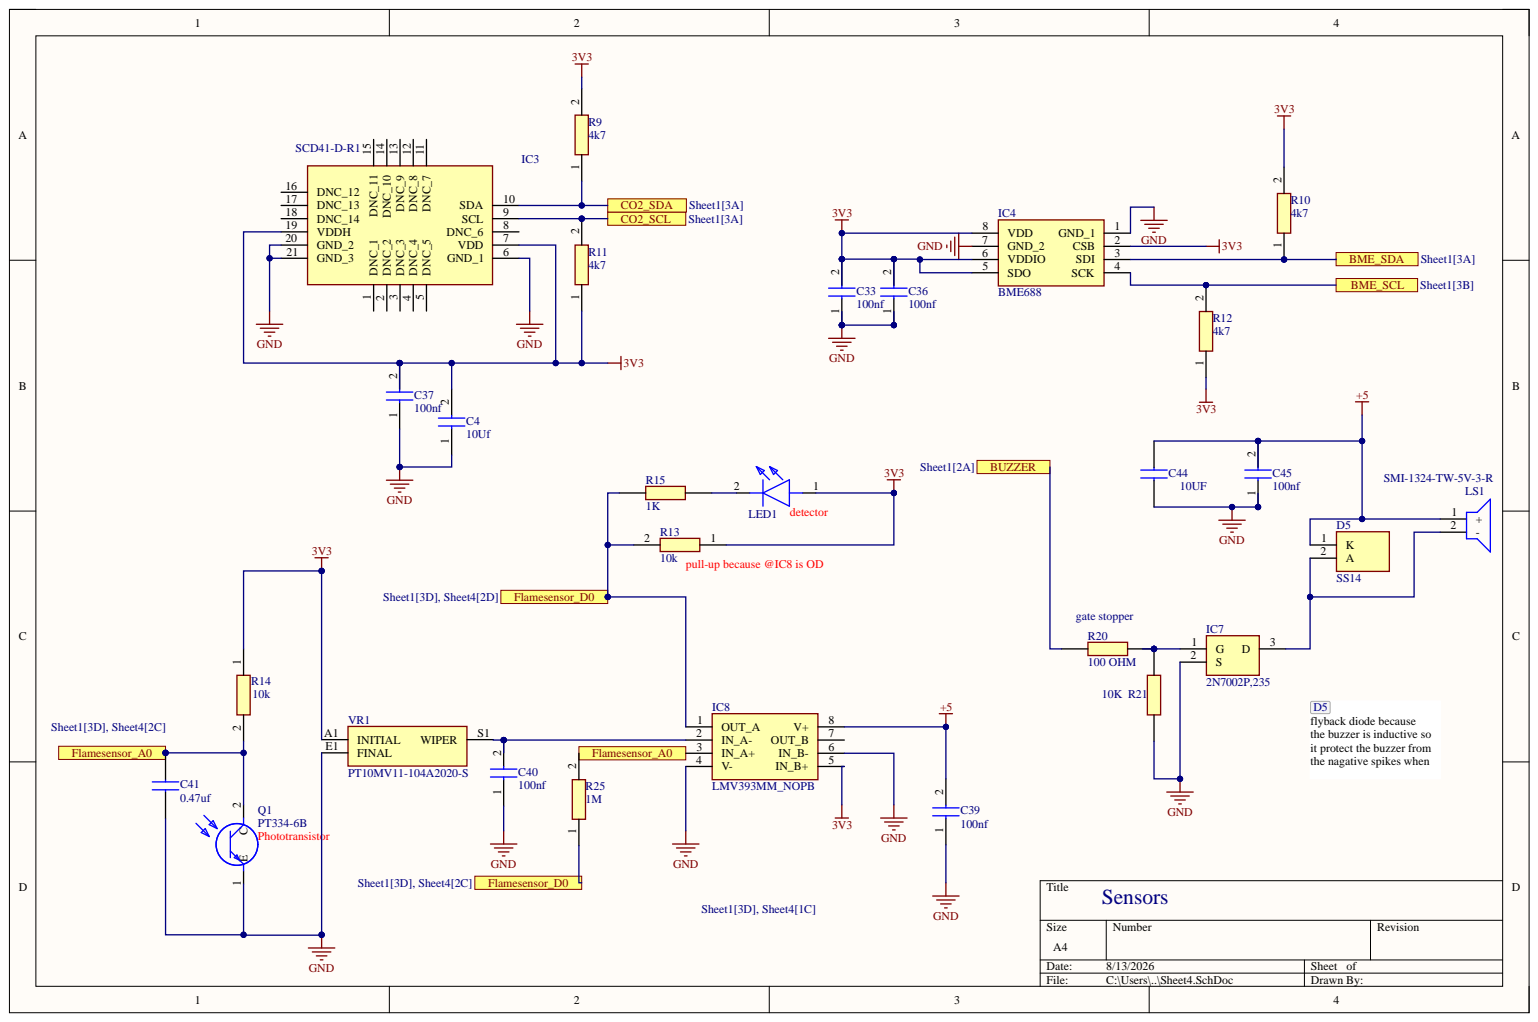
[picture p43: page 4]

pull-up because @IC8 is OD

flyback diode because
the buzzer is inductive so
it protect the buzzer from
the nagative spikes when

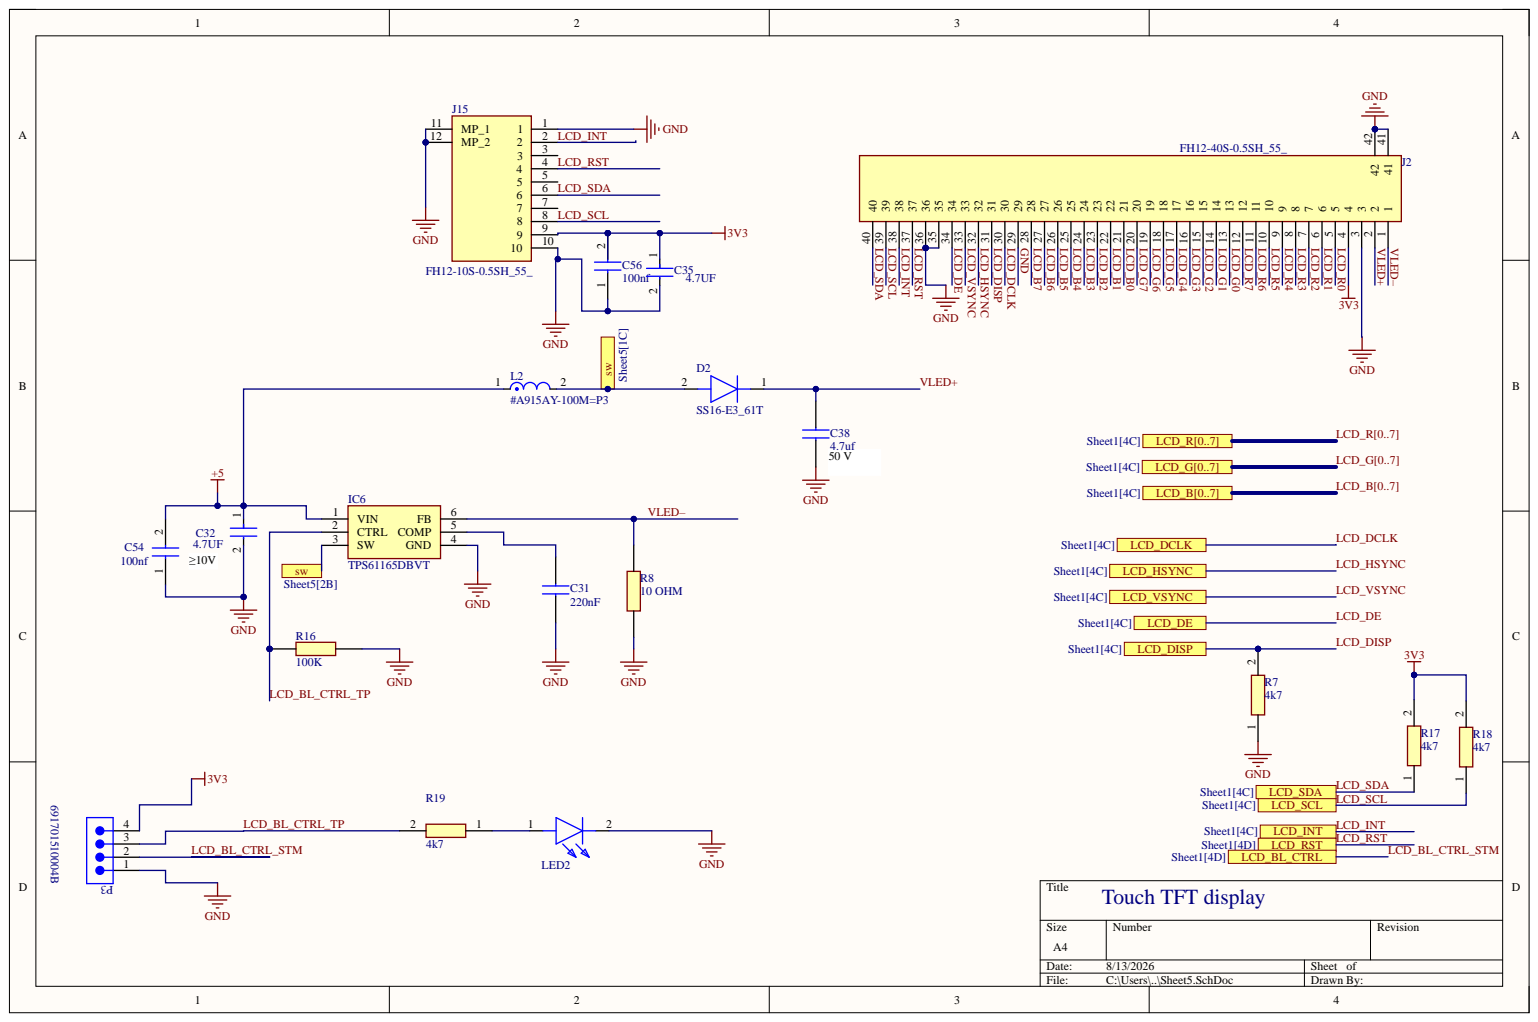
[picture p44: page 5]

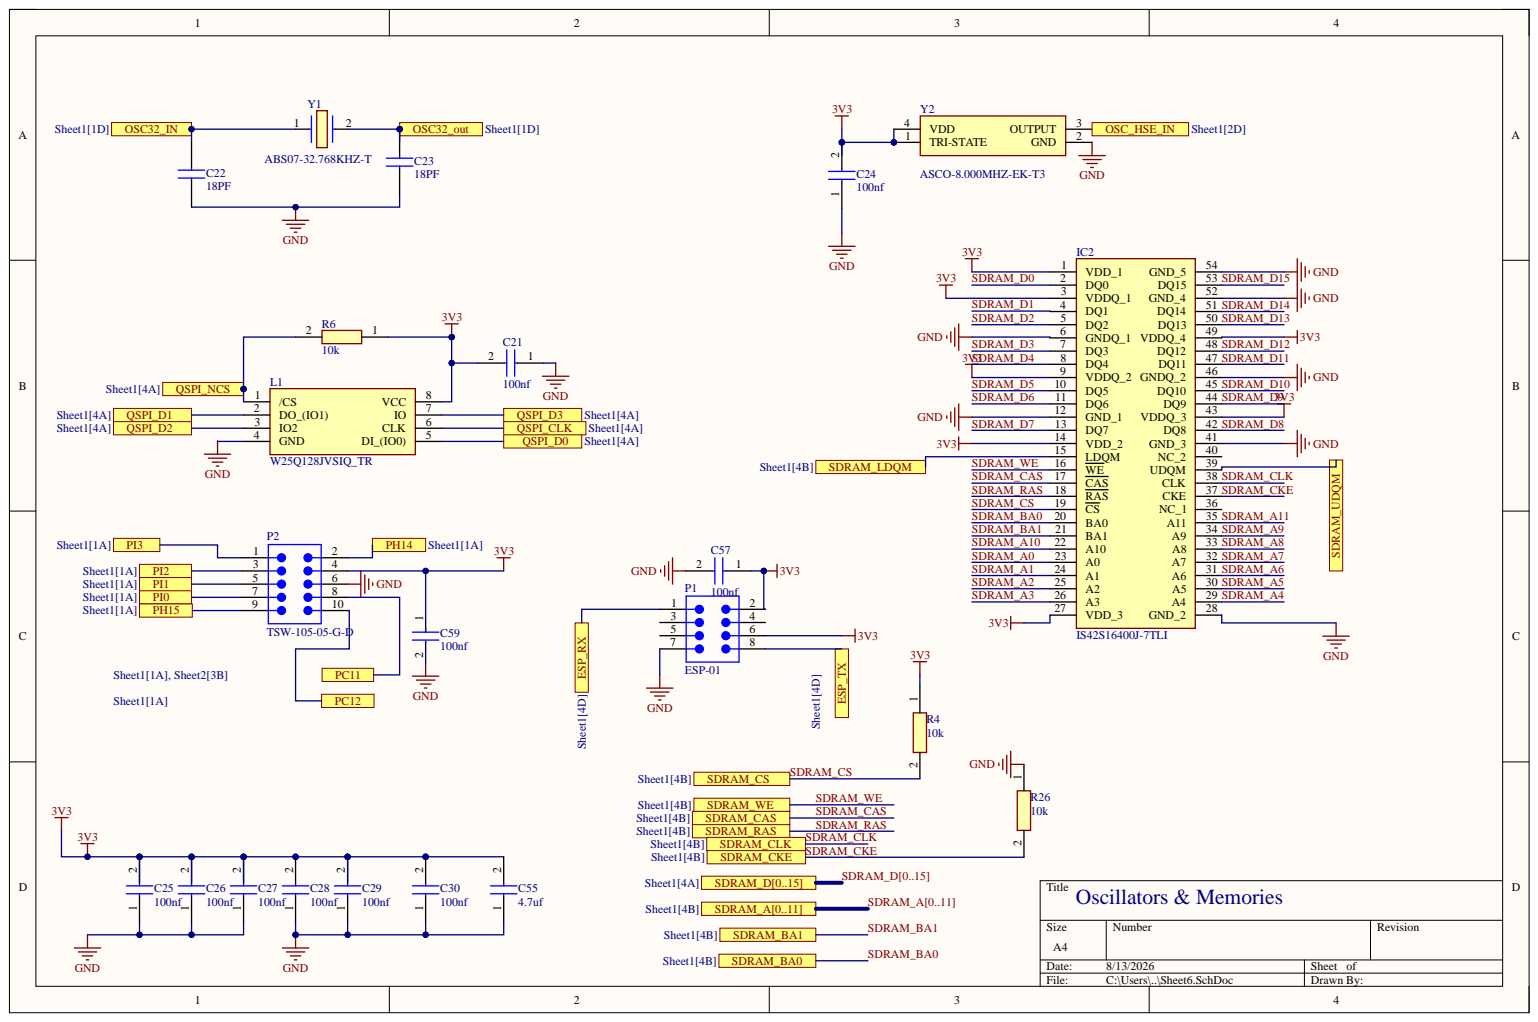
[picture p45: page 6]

SDRAM_WE | | WE 16

CAS 17 | SDRAM_CLK

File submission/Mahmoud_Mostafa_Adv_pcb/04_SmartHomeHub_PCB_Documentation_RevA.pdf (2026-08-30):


View from Top side (Scale 1:1)

View from Bottom side (Scale 1:1)

Top Layer (Scale 1:2); Bottom Layer (Scale 1:2); Layer 1 (Scale 1:2); Layer 2 (Scale 1:2); Material; Layer; Thickness Dielectric Material Type; Gerber; Top Overlay; Legend; GTO; Surface Material Top Solder; Solder Resist; Solder Mask; GTS; Copper; Top Layer; Signal; GTL; Prepreg; Dielectric; Layer 1; Internal Plane GP1; Layer 2; Internal Plane GP2; Bottom Layer 0.04mm; GBL; Surface Material Bottom Solder 0.01mm; GBS; Bottom Overlay; GBO; Total thickness: 0.62mm

Layer Stack Legend

Symbol Count 444 16 4 2 2 18 3 4 4 1 498 Total; Hole Size 0.35mm 0.40mm 0.60mm 0.92mm 1.02mm 1.02mm 1.30mm 1.60mm 3.20mm 4.00mm; Plated Plated Plated Plated Plated Non-Plated Plated Plated Plated Non-Plated Non-Plated; Hole Tolerance; Drill Table

Drill Drawing View (Scale 1:1)

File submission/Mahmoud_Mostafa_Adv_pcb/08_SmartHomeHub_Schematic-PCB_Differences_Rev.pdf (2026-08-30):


[NRST]
Extra Pins in Nets


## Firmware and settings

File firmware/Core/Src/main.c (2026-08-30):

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
/* Includes ------------------------------------------------------------------*/
#include "main.h"

/* USER CODE BEGIN Includes */
#include "app_config.h"
#include "bme68x.h"
#include "mcp2221a_console.h"
#include "qspi_assets.h"
#include <stdbool.h>
#include <ctype.h>
#include <stdlib.h>
#include <stdarg.h>
#include <stdio.h>
#include <string.h>

/* Display size */
#define LCD_WIDTH            480U
#define LCD_HEIGHT           272U
/* USER CODE END Includes */

/* USER CODE BEGIN PTD */
/* Full-screen 8-bit indexed GUI: 480 x 272 = 130560 bytes per frame. */
#define TEXT_WIDTH           LCD_WIDTH
#define TEXT_HEIGHT          LCD_HEIGHT
#define TEXT_X               0U
#define TEXT_Y               0U

/* Palette indices used by the LTDC L8 foreground layer. */
#define LCD_BLACK            1U
#define LCD_WHITE            2U
#define LCD_RED              3U
#define LCD_GREEN            4U
#define LCD_BLUE             5U
#define LCD_CYAN             6U
#define LCD_YELLOW           7U
#define LCD_DARK_BLUE        8U
#define LCD_CARD             9U
#define LCD_CARD_ALT         10U
#define LCD_MUTED            11U
#define LCD_ORANGE           12U
#define LCD_TEAL             13U
#define LCD_WARNING_BG       14U
#define LCD_DANGER_BG        15U

/* -------------------- SDRAM -------------------- */

#define SDRAM_BASE_ADDRESS       0xC0000000UL

/*
 * Proven IS42S16400J configuration:
 * HCLK = 200 MHz, FMC SDCLK = HCLK / 3 = 66.667 MHz.
 * Refresh = (64 ms / 4096 rows) * 66.667 MHz - 20 = about 1022.
 */
#define SDRAM_REFRESH_COUNT      1022U

/* Two 480x272 L8 buffers, deliberately 256-KiB apart. */
#define LCD_FRAME_BYTES          (TEXT_WIDTH * TEXT_HEIGHT)
#define LCD_FRAMEBUFFER_0_ADDR   (SDRAM_BASE_ADDRESS + 0x00000000UL)
#define LCD_FRAMEBUFFER_1_ADDR   (SDRAM_BASE_ADDRESS + 0x00040000UL)

#define SDRAM_MODEREG_BURST_LENGTH_1          0x0000U
#define SDRAM_MODEREG_BURST_TYPE_SEQUENTIAL   0x0000U
#define SDRAM_MODEREG_CAS_LATENCY_3            0x0030U
#define SDRAM_MODEREG_OPERATING_MODE_STANDARD  0x0000U
#define SDRAM_MODEREG_WRITEBURST_MODE_SINGLE   0x0200U
/* USER CODE END PTD */

/* USER CODE BEGIN PM */

/* Frame pixels live in SDRAM, not in the STM32's internal SRAM. */
static uint8_t *text_framebuffer =
    (uint8_t *)(uintptr_t)LCD_FRAMEBUFFER_1_ADDR;
static uint8_t *lcd_front_buffer =
    (uint8_t *)(uintptr_t)LCD_FRAMEBUFFER_0_ADDR;
static uint8_t *lcd_back_buffer =
    (uint8_t *)(uintptr_t)LCD_FRAMEBUFFER_1_ADDR;
static bool lcd_double_buffer_ready = false;
static QSPI_WeatherTheme lcd_background_theme = QSPI_WEATHER_CLEAR_DAY;

/* USER CODE END PM */

ADC_HandleTypeDef hadc1;

I2C_HandleTypeDef hi2c1;
I2C_HandleTypeDef hi2c3;
I2C_HandleTypeDef hi2c4;

LTDC_HandleTypeDef hltdc;

QSPI_HandleTypeDef hqspi;

UART_HandleTypeDef huart1;
UART_HandleTypeDef huart3;

SDRAM_HandleTypeDef hsdram1;

/* USER CODE BEGIN PV */
static void BME688_GasTestScreen(bool sensor_online);
static bool gui_dashboard_active = false;
/* USER CODE END PV */

void SystemClock_Config(void);
static void MPU_Config(void);
static void MX_GPIO_Init(void);
static void MX_LTDC_Init(void);
static void MX_USART1_UART_Init(void);
static void MX_ADC1_Init(void);
static void MX_I2C1_Init(void);
static void MX_I2C3_Init(void);
static void MX_I2C4_Init(void);
static void MX_USART3_UART_Init(void);
static void MX_FMC_Init(void);
static void MX_QUADSPI_Init(void);
/* USER CODE BEGIN PFP */
static void App_ConsoleCommand(const char *command);
static HAL_StatusTypeDef FlameSensor_ReadADC(uint16_t *raw);
static void FlameSensor_TestScreen(void);
static bool Safety_FlameActiveDuringNetwork(void);
static uint16_t ESP01_SendCommand(const char *command,
                                  char *response,
                                  uint16_t capacity,
                                  uint32_t timeout_ms);

static bool ESP01_TestScreen(void);
static bool ESP01_ConnectWiFi(void);
static uint16_t ESP01_ReadUntil(char *response,
                                uint16_t capacity,
                                const char *success,
                                const char *failure,
                                uint32_t timeout_ms);

static bool ESP01_PrepareDataSend(uint16_t data_length);

static bool Blynk_UpdateVirtualPin(uint8_t virtual_pin,
                                   const char *value);
/* USER CODE END PFP */

/* USER CODE BEGIN 0 */

static void LCD_DrawPixel(uint16_t x, uint16_t y, uint16_t colour)
{
    if ((x < TEXT_WIDTH) && (y < TEXT_HEIGHT))
    {
        text_framebuffer[(y * TEXT_WIDTH) + x] = (uint8_t)colour;
    }
}

static void LCD_FillRectangle(uint16_t x,
                              uint16_t y,
                              uint16_t width,
                              uint16_t height,
                              uint16_t colour)
{
    uint16_t px;
    uint16_t py;

    for (py = 0U; py < height; py++)
    {
        for (px = 0U; px < width; px++)
        {
            LCD_DrawPixel(x + px, y + py, colour);
        }
    }
}

static void LCD_ClearTextLayer(uint16_t colour)
{
    uint32_t pixel;

    for (pixel = 0U;
         pixel < (TEXT_WIDTH * TEXT_HEIGHT);
         pixel++)
    {
        text_framebuffer[pixel] = (uint8_t)colour;
    }
}

static bool LCD_LoadBackground(void)
{
    const uint8_t *background =
        QSPI_Assets_WeatherBackgroundL8(lcd_background_theme);

    if (background == NULL)
        return false;

    memcpy(text_framebuffer, background, LCD_FRAME_BYTES);
    return true;
}

static void LCD_RestoreBackgroundRectangle(uint16_t x,
                                           uint16_t y,
                                           uint16_t width,
                                           uint16_t height)
{
    const uint8_t *background =
        QSPI_Assets_WeatherBackgroundL8(lcd_background_theme);

    if ((background == NULL) ||
        (x >= TEXT_WIDTH) ||
        (y >= TEXT_HEIGHT))
    {
        return;
    }

    if (((uint32_t)x + width) > TEXT_WIDTH)
        width = (uint16_t)(TEXT_WIDTH - x);

    if (((uint32_t)y + height) > TEXT_HEIGHT)
        height = (uint16_t)(TEXT_HEIGHT - y);

    for (uint16_t row = 0U; row < height; row++)
    {
        uint32_t offset = ((uint32_t)y + row) * TEXT_WIDTH + x;
        memcpy(&text_framebuffer[offset],
               &background[offset],
               width);
    }
}

static QSPI_FontSize LCD_FontFromScale(uint8_t scale)
{
    if (scale >= 3U)
        return QSPI_FONT_LARGE;

    if (scale == 2U)
        return QSPI_FONT_MEDIUM;

    return QSPI_FONT_SMALL;
}

static uint16_t LCD_MeasureString(const char *text, uint8_t scale)
{
    QSPI_FontGlyph glyph;
    QSPI_FontSize font = LCD_FontFromScale(scale);
    uint32_t width = 0U;

    if (text == NULL)
        return 0U;

    while (*text != '\0')
    {
        if (QSPI_Assets_GetModernGlyph(font, *text, &glyph))
            width += (uint32_t)glyph.advance + 1U;

        text++;
    }

    if (width != 0U)
        width--;

    return (width > 0xFFFFU) ? 0xFFFFU : (uint16_t)width;
}

static uint8_t LCD_DrawCharacter(uint16_t x,
                                 uint16_t y,
                                 char character,
                                 uint16_t colour,
                                 uint8_t scale)
{
    QSPI_FontGlyph glyph;
    QSPI_FontSize font = LCD_FontFromScale(scale);
    uint8_t row;
    uint8_t column;

    if (!QSPI_Assets_GetModernGlyph(font, character, &glyph))
        return 0U;

    for (row = 0U; row < glyph.height; row++)
    {
        for (column = 0U; column < glyph.width; column++)
        {
            uint8_t pixel = glyph.bitmap[
                ((uint32_t)row * glyph.row_bytes) + (column >> 3U)
            ];

            if ((pixel & (uint8_t)(0x80U >> (column & 7U))) != 0U)
            {
                int32_t pixel_x = (int32_t)x + glyph.left + column;
                int32_t pixel_y = (int32_t)y + glyph.top + row;

                if ((pixel_x >= 0) && (pixel_y >= 0) &&
                    (pixel_x < (int32_t)TEXT_WIDTH) &&
                    (pixel_y < (int32_t)TEXT_HEIGHT))
                {
                    LCD_DrawPixel((uint16_t)pixel_x,
                                  (uint16_t)pixel_y,
                                  colour);
                }
            }
        }
    }

    return glyph.advance;
}

static void LCD_DrawString(uint16_t x,
                           uint16_t y,
                           const char *text,
                           uint16_t colour,
                           uint8_t scale)
{
    while (*text != '\0')
    {
        uint8_t advance = LCD_DrawCharacter(x, y, *text, colour, scale);

        x += (uint16_t)advance + 1U;
        text++;

        if (x >= TEXT_WIDTH)
        {
            break;
        }
    }
}

static void LCD_DrawCenteredString(uint16_t y,
                                   const char *text,
                                   uint16_t colour,
                                   uint8_t scale)
{
    uint16_t width = LCD_MeasureString(text, scale);
    uint16_t x = 0U;

    if (width < TEXT_WIDTH)
    {
        x = (uint16_t)((TEXT_WIDTH - width) / 2U);
    }

    LCD_DrawString(x, y, text, colour, scale);
}

static uint16_t LCD_MeasureStringZoom(const char *text,
                                      QSPI_FontSize font,
                                      uint8_t zoom)
{
    QSPI_FontGlyph glyph;
    uint32_t width = 0U;

    if ((text == NULL) || (zoom == 0U))
        return 0U;

    while (*text != '\0')
    {
        if (QSPI_Assets_GetModernGlyph(font, *text, &glyph))
            width += ((uint32_t)glyph.advance + 1U) * zoom;

        text++;
    }

    if (width >= zoom)
        width -= zoom;

    return (width > 0xFFFFU) ? 0xFFFFU : (uint16_t)width;
}

static uint16_t LCD_DrawCharacterZoom(uint16_t x,
                                      uint16_t y,
                                      char character,
                                      uint16_t colour,
                                      QSPI_FontSize font,
                                      uint8_t zoom)
{
    QSPI_FontGlyph glyph;

    if ((zoom == 0U) ||
        !QSPI_Assets_GetModernGlyph(font, character, &glyph))
    {
        return 0U;
    }

    for (uint8_t row = 0U; row < glyph.height; row++)
    {
        for (uint8_t column = 0U; column < glyph.width; column++)
        {
            uint8_t pixel = glyph.bitmap[
                ((uint32_t)row * glyph.row_bytes) + (column >> 3U)
            ];

            if ((pixel & (uint8_t)(0x80U >> (column & 7U))) != 0U)
            {
                int32_t pixel_x = (int32_t)x +
                    ((int32_t)glyph.left + column) * zoom;
                int32_t pixel_y = (int32_t)y +
                    ((int32_t)glyph.top + row) * zoom;

                for (uint8_t zy = 0U; zy < zoom; zy++)
                {
                    for (uint8_t zx = 0U; zx < zoom; zx++)
                    {
                        int32_t draw_x = pixel_x + zx;
                        int32_t draw_y = pixel_y + zy;

                        if ((draw_x >= 0) && (draw_y >= 0) &&
                            (draw_x < (int32_t)TEXT_WIDTH) &&
                            (draw_y < (int32_t)TEXT_HEIGHT))
                        {
                            LCD_DrawPixel((uint16_t)draw_x,
                                          (uint16_t)draw_y,
                                          colour);
                        }
                    }
                }
            }
        }
    }

    return (uint16_t)glyph.advance * zoom;
}

static void LCD_DrawStringZoom(uint16_t x,
                               uint16_t y,
                               const char *text,
                               uint16_t colour,
                               QSPI_FontSize font,
                               uint8_t zoom)
{
    if (text == NULL)
        return;

    while (*text != '\0')
    {
        uint16_t advance = LCD_DrawCharacterZoom(x,
                                                 y,
                                                 *text,
                                                 colour,
                                                 font,
                                                 zoom);
        x += advance + zoom;
        text++;

        if (x >= TEXT_WIDTH)
            break;
    }
}

static void LCD_DrawCenteredStringShadow(uint16_t y,
                                         const char *text,
                                         uint16_t colour,
                                         uint8_t scale)
{
    uint16_t width = LCD_MeasureString(text, scale);
    uint16_t x = (width < TEXT_WIDTH) ?
        (uint16_t)((TEXT_WIDTH - width) / 2U) : 0U;

    LCD_DrawString(x + 1U, y + 1U, text, LCD_BLACK, scale);
    LCD_DrawString(x, y, text, colour, scale);
}

static void LCD_DrawStringShadow(uint16_t x,
                                 uint16_t y,
                                 const char *text,
                                 uint16_t colour,
                                 uint8_t scale)
{
    LCD_DrawString(x + 1U, y + 1U, text, LCD_BLACK, scale);
    LCD_DrawString(x, y, text, colour, scale);
}
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
int main(void)
{

  /* MPU Configuration--------------------------------------------------------*/
  MPU_Config();

  /* MCU Configuration--------------------------------------------------------*/

  /* Reset of all peripherals, Initializes the Flash interface and the Systick. */
  HAL_Init();

  /* USER CODE BEGIN Init */

  /* Re-assert the protected SDRAM and QSPI MPU regions after HAL reset. */
  MPU_FixExternalMemory();

  /* USER CODE END Init */

  /* Configure the system clock */
  SystemClock_Config();

  /* Initialize all configured peripherals */
  MX_GPIO_Init();
  MX_LTDC_Init();
  MX_USART1_UART_Init();
  MX_ADC1_Init();
  MX_I2C1_Init();
  MX_I2C3_Init();
  MX_I2C4_Init();
  MX_USART3_UART_Init();
  MCP2221A_Console_Init(&huart3, App_ConsoleCommand);
  MCP2221A_Console_PrintBanner();
  MX_FMC_Init();
  MX_QUADSPI_Init();
  /* USER CODE BEGIN 2 */

  bool qspi_assets_installed_now = false;

  /* SDRAM must be awake before either GUI framebuffer is touched. */
  if (SDRAM_Startup() != HAL_OK)
  {
      MCP2221A_Console_Print("[FAIL] SDRAM startup\r\n");
      Error_Handler();
  }

  app_runtime.sdram_ok = true;
  MCP2221A_Console_Print("[PASS] SDRAM startup\r\n");
  MCP2221A_Console_Print("[....] QSPI asset initialization\r\n");

  if (QSPI_Assets_Init(&hqspi, &qspi_assets_installed_now) != HAL_OK)
  {
      char qspi_error_line[40];
      int qspi_error_length = snprintf(
          qspi_error_line,
          sizeof(qspi_error_line),
          "QSPI ASSET ERROR %u\r\n",
          (unsigned int)QSPI_Assets_LastError()
      );

      if (qspi_error_length > 0)
      {
          MCP2221A_Console_Write(qspi_error_line,
                                 (size_t)qspi_error_length);
      }

      Error_Handler();
  }

  app_runtime.qspi_ok = true;
  MCP2221A_Console_Printf("[PASS] QSPI assets %s\r\n",
                          qspi_assets_installed_now ?
                              "installed" : "ready");

  /* Configure LTDC only after SDRAM is ready and QSPI is memory mapped. */
  LCD_ConfigureTextLayer();
  LCD_ShowStatus("QSPI ASSETS",
                 qspi_assets_installed_now ? "INSTALLED" : "READY",
                 LCD_GREEN);
  HAL_Delay(qspi_assets_installed_now ? 2000U : 500U);

  /* The separate diagnostic firmware already verified all 8 MiB. Never run
   * a destructive SDRAM/QSPI test after GUI memory is live. */
  bool scd41_online;
  bool bme688_online;
  bool scd41_read_ok = false;
  bool bme688_read_ok = false;
  bool flame_adc_ok = false;
  bool scd41_has_sample = false;
  bool bme688_has_sample = false;
  bool flame_has_sample = false;
  bool scd41_healthy = false;
  bool bme688_healthy = false;
  bool flame_sensor_healthy = false;
  bool measurements_ready = false;
  bool esp_ok;
  bool wifi_ok = false;
  bool blynk_ok = false;
  uint8_t scd41_failures = 0U;
  uint8_t bme688_failures = 0U;
  uint8_t flame_failures = 0U;
  SystemAlarm current_alarm = {ALARM_NONE, BUZZER_OFF};
  int8_t last_uploaded_flame = -1;
  uint32_t now;
  uint32_t last_flame_tick;
  uint32_t last_sensor_tick;
  uint32_t last_display_tick;
  uint32_t last_blynk_success_tick;
  uint32_t last_blynk_attempt_tick;
  uint32_t last_wifi_retry_tick;
  uint32_t last_sensor_retry_tick;
  uint32_t last_location_attempt_tick;
  uint32_t last_weather_attempt_tick;

  LCD_ShowStatus("INITIALIZING",
                 "SCD41 AND BME688",
                 LCD_CYAN);

  scd41_online = SCD41_Init();
  bme688_online = BME688_Init();

  app_runtime.scd41_ok = scd41_online;
  app_runtime.bme688_ok = bme688_online;
  MCP2221A_Console_Printf("[%s] SCD41 on I2C4\r\n",
                          scd41_online ? "PASS" : "FAIL");
  if (scd41_online)
  {
      MCP2221A_Console_Printf(
          "[INFO] SCD41 integration offset=%u.%u C; room T/RH source=SCD41\r\n",
          (unsigned int)(SCD41_TEMPERATURE_OFFSET10 / 10U),
          (unsigned int)(SCD41_TEMPERATURE_OFFSET10 % 10U));
  }
  MCP2221A_Console_Printf("[%s] BME688 on I2C3\r\n",
                          bme688_online ? "PASS" : "FAIL");

  if (!scd41_online)
      scd41_failures = SENSOR_FAILURE_LIMIT;

  if (!bme688_online)
      bme688_failures = SENSOR_FAILURE_LIMIT;

  LCD_ShowStatus("INITIALIZING",
                 "ESP-01 WIFI",
                 LCD_CYAN);

  esp_ok = ESP01_TestScreen();
  app_runtime.esp_ok = esp_ok;
  MCP2221A_Console_Printf("[%s] ESP-01 AT interface on USART1\r\n",
                          esp_ok ? "PASS" : "FAIL");

  if (esp_ok)
  {
      HAL_Delay(1000U);
      wifi_ok = ESP01_ConnectWiFi();
      app_runtime.wifi_ok = wifi_ok;
      MCP2221A_Console_Printf("[%s] Wi-Fi connection\r\n",
                              wifi_ok ? "PASS" : "FAIL");
//      if (wifi_ok)
//      {
//          Weather_DebugRawResponse();
//      }
      if (wifi_ok)
      {
          LCD_ShowStatus("MY LOCATION",
                         "DETECTING...",
                         LCD_CYAN);

          if (Location_Fetch(&internet_weather))
          {
              LCD_ShowStatus("OUTSIDE WEATHER",
                             "DOWNLOADING...",
                             LCD_CYAN);
              (void)Weather_Fetch(&internet_weather);
          }
      }
  }

  now = HAL_GetTick();
  last_flame_tick = now - FLAME_SAMPLE_PERIOD_MS;
  last_sensor_tick = now - SENSOR_SAMPLE_PERIOD_MS;
  last_display_tick = now - DISPLAY_REFRESH_MS;
  last_blynk_success_tick = now - BLYNK_UPLOAD_PERIOD_MS;
  last_blynk_attempt_tick = now - BLYNK_RETRY_PERIOD_MS;
  last_wifi_retry_tick = now;
  last_sensor_retry_tick = now;
  last_location_attempt_tick = now;
  last_weather_attempt_tick = now;

  /* The GPIO default is already low, but repeat it here so no previous test
   * state can leave the active buzzer enabled. */
  HAL_GPIO_WritePin(BUZZER_GPIO_Port, BUZZER_Pin, GPIO_PIN_RESET);

  /* From this point onward network debug functions may print to USART3, but
   * they may not replace the live dashboard on the LCD. */
  gui_dashboard_active = true;

  MCP2221A_Console_Print("[READY] Home HUB application running\r\n> ");


  /* USER CODE END 2 */

  /* Infinite loop */
  /* USER CODE BEGIN WHILE */
  while (1)
  {
    /* USER CODE END WHILE */

    /* USER CODE BEGIN 3 */

      bool upload_due;
      bool flame_changed;
      bool network_request_made = false;

      MCP2221A_Console_Process();
      now = HAL_GetTick();

      /* Fast local flame sampling. */
      if ((uint32_t)(now - last_flame_tick) >=
          FLAME_SAMPLE_PERIOD_MS)
      {
          last_flame_tick = now;
          flame_adc_ok = FlameSensor_ReadAll(&sensor_values);

          if (flame_adc_ok)
          {
              flame_has_sample = true;
              flame_failures = 0U;
          }
          else if (flame_failures < SENSOR_FAILURE_LIMIT)
          {
              flame_failures++;
          }
      }

      /* Environmental sensors: the SCD41 produces one sample per 5 s. */
      if ((uint32_t)(now - last_sensor_tick) >=
          SENSOR_SAMPLE_PERIOD_MS)
      {
          last_sensor_tick = now;

          scd41_read_ok =
              scd41_online && SCD41_Read(&sensor_values);

          bme688_read_ok =
              bme688_online && BME688_Read(&sensor_values);

          if (scd41_read_ok)
          {
              scd41_has_sample = true;
              scd41_failures = 0U;
          }
          else if (scd41_failures < SENSOR_FAILURE_LIMIT)
          {
              scd41_failures++;
          }

          if (bme688_read_ok)
          {
              bme688_has_sample = true;
              bme688_failures = 0U;
          }
          else if (bme688_failures < SENSOR_FAILURE_LIMIT)
          {
              bme688_failures++;
          }

          if (bme688_read_ok)
              GasMonitor_Update(&sensor_values);

          measurements_ready = true;
      }

      scd41_healthy =
          scd41_online && scd41_has_sample &&
          (scd41_failures < SENSOR_FAILURE_LIMIT);

      bme688_healthy =
          bme688_online && bme688_has_sample &&
          (bme688_failures < SENSOR_FAILURE_LIMIT);

      flame_sensor_healthy =
          flame_has_sample &&
          (flame_failures < SENSOR_FAILURE_LIMIT);

      /* A disconnected I2C sensor is retried without rebooting the hub. */
      if (((!scd41_healthy) || (!bme688_healthy)) &&
          ((uint32_t)(now - last_sensor_retry_tick) >=
           SENSOR_RETRY_PERIOD_MS))
      {
          last_sensor_retry_tick = now;

          if (!scd41_healthy)
          {
              scd41_online = SCD41_Init();

              if (scd41_online)
              {
                  scd41_failures = 0U;
                  last_sensor_tick =
                      HAL_GetTick() - SENSOR_SAMPLE_PERIOD_MS;
              }
          }
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

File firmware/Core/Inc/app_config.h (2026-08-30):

#ifndef APP_CONFIG_H
#define APP_CONFIG_H

/*
 * Central application configuration.
 *
 * Keep hardware-independent timing, thresholds and Blynk virtual-pin
 * assignments here. Private Wi-Fi/Blynk credentials live in app_secrets.h.
 */

#include "app_secrets.h"

#if defined(__GNUC__)
#define APP_UNUSED __attribute__((unused))
#else
#define APP_UNUSED
#endif

/* Remote services used by the ESP-01 AT firmware. */
#define BLYNK_SERVER                 "lon1.blynk.cloud"
#define BLYNK_TEMPLATE_ID            "TMPL58WLMvqE4"
#define BLYNK_TEMPLATE_NAME          "Home HUB"
#define LOCATION_SERVER              "ip-api.com"
#define WEATHER_SERVER               "wttr.in"
#define WEATHER_FALLBACK_SERVER      "wttr.is"

/* Application timing. */
#define FLAME_SAMPLE_PERIOD_MS       200U
#define SENSOR_SAMPLE_PERIOD_MS      5000U
#define DISPLAY_REFRESH_MS           500U
#define BLYNK_UPLOAD_PERIOD_MS       10000U
#define BLYNK_RETRY_PERIOD_MS        3000U
#define WIFI_RETRY_PERIOD_MS         30000U
#define SENSOR_RETRY_PERIOD_MS       30000U
#define WEATHER_REFRESH_MS           10000U
#define WEATHER_RETRY_MS             10000U
#define LOCATION_REFRESH_MS          21600000U
#define LOCATION_RETRY_MS            300000U

/* Retained for the optional single-pin Blynk diagnostic page. */
#define BLYNK_SCREEN_DELAY_MS        1500U

/* Indoor-comfort and alarm thresholds. Values ending in 10 use 0.1 units. */
#define CO2_FAIR_PPM                 1000U
#define CO2_POOR_PPM                 1500U
#define CO2_DANGER_PPM               2500U
#define ROOM_TEMP_LOW10              100
#define ROOM_TEMP_HIGH10             350
#define ROOM_RH_LOW10                200U
#define ROOM_RH_HIGH10               750U
#define PRESSURE_MIN_HPA10           8500U
#define PRESSURE_MAX_HPA10           11000U

/*
 * SCD41 integration temperature offset, in 0.1 degC.
 *
 * Calibrated after the assembled hub reached thermal equilibrium:
 *   SCD41 output  = 32.3 degC
 *   reference     = 27.0 degC
 *   previous SCD41 offset = 4.0 degC (factory default)
 *
 * Sensirion's equation gives: 32.3 - 27.0 + 4.0 = 9.3 degC.
 * The firmware writes this absolute offset at every boot while the sensor is
 * idle. It is intentionally not persisted, avoiding unnecessary EEPROM writes.
 * Recalibrate this value after changing the enclosure, airflow or heat load.
 */
#define SCD41_TEMPERATURE_OFFSET10   93U

/* IIR filter: each new SCD41 sample contributes 1/4 of the displayed value. */
#define ROOM_TEMPERATURE_FILTER_DIV  4
#define SENSOR_FAILURE_LIMIT         3U

/* BME688 adaptive gas-change detection. */
#define GAS_BASELINE_SAMPLES         60U
#define GAS_TRIGGER_RATIO_PERCENT    55U
#define GAS_CLEAR_RATIO_PERCENT      75U
#define GAS_ALARM_CONFIRM_SAMPLES    6U
#define GAS_CLEAR_CONFIRM_SAMPLES    6U
#define GAS_TRIGGER_CHANGE_PERCENT   (100U - GAS_TRIGGER_RATIO_PERCENT)
#define GAS_CLEAR_CHANGE_PERCENT     (100U - GAS_CLEAR_RATIO_PERCENT)

/* Blynk virtual-pin assignments. Each pin must exist in the Home HUB template. */
#define VPIN_FLAME_DETECTED          0U
#define VPIN_FLAME_ADC               1U
#define VPIN_FLAME_VOLTAGE           2U
#define VPIN_CO2                     3U
#define VPIN_SCD_TEMPERATURE         4U
#define VPIN_SCD_HUMIDITY            5U
#define VPIN_BME_TEMPERATURE         6U
#define VPIN_BME_HUMIDITY            7U
#define VPIN_BME_PRESSURE            8U
#define VPIN_GAS_RESISTANCE          9U
#define VPIN_GAS_RATIO               10U
#define VPIN_GAS_ALARM               11U
#define VPIN_OUTSIDE_TEMP            12U
#define VPIN_OUTSIDE_FEELS           13U
#define VPIN_OUTSIDE_HIGH            14U
#define VPIN_OUTSIDE_LOW             15U
#define VPIN_WEATHER_THEME           16U

#endif /* APP_CONFIG_H */

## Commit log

2026-08-30 Stage checksum-verified complete project archive
2026-08-30 Upload complete Smart Home Hub project
    [05_SmartHomeHub_BOM_RevA.xlsx, Blynk_Datastreams.csv, Hub_Unit - Copy.PrjPcb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]

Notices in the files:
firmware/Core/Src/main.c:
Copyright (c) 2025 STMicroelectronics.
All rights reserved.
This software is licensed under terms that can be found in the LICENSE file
